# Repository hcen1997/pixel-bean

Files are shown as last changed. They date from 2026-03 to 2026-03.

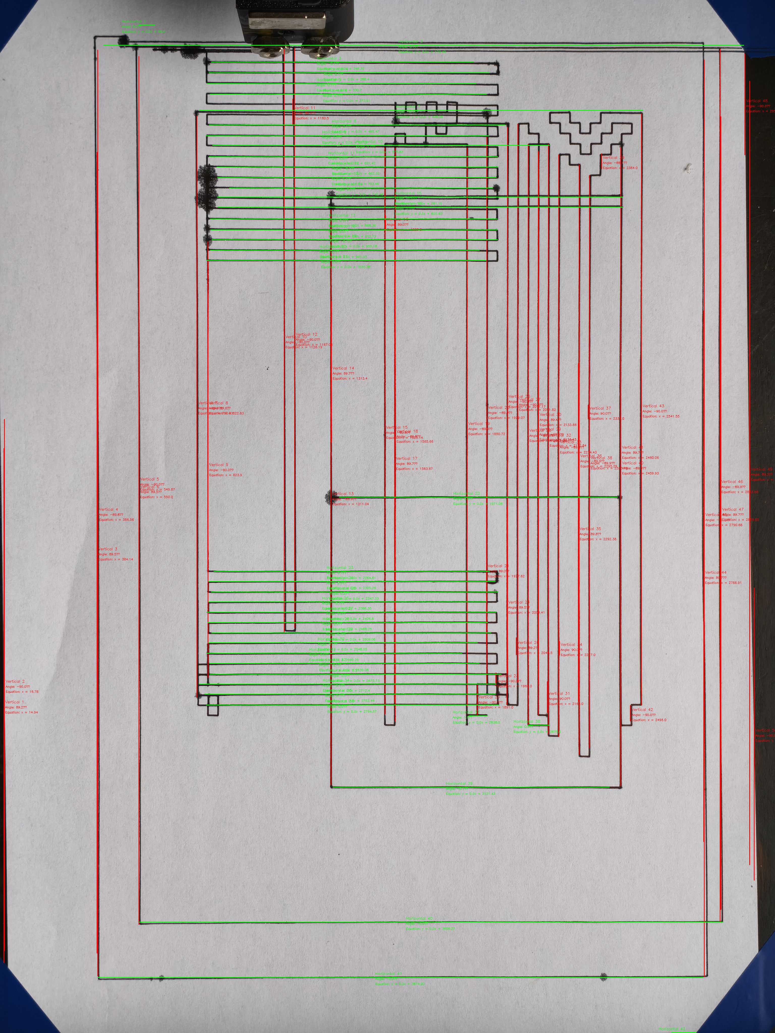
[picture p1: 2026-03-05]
grbl-code/merged_lines_result.jpg

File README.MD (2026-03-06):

# PixelBean 自动拼豆机
自制全自动拼豆机原型

## 当前版本
- 结构：CoreXY
- 供豆：单色
- 功能：单次拼 24 颗豆子

## 效率
- 单次拼 24 颗豆子，耗时 10 秒左右

## 硬件
- 主控：Arduino
- 驱动：步进电机 + 舵机
- 运动：CoreXY 结构
- 参考 https://www.bilibili.com/video/BV1cK411X7aa 大鱼diy写字机2022年版
- 参考 拼多多 点按式拼豆笔

## 软件
- G代码解析
- 坐标运动控制
- 单色落豆逻辑
- 豆子绘画：https://www.beadscanvas.com/zh/editor

## 计划升级
- 多色供料
- 视觉定位
- 更快更稳

本项目基于MIT License开源
欢迎一起改、一起玩。

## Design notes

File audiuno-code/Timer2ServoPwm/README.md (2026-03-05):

# Timer2ServoPwm
Arduino servo driver library base on timer2

The servo driver function is compatible with official servo library.
Besides, this library provides a not very accurate pwm function on any pin.
The main point of this library is to use timer2 as servo driver timer 
interrupt source when timer1 has been used by other libraries.

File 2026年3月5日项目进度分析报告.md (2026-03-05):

# PixelBean 拼豆机项目分析报告
## 一、项目概述
您的仓库是一个**自动化拼豆机（Perler Bead Printer）**项目，名为"PixelBean"，旨在实现将图像自动转换为拼豆图案并进行打印。该项目体现了"白嫖"成熟技术的开发思路，通过复用开源写字机/雕刻机的XY运动平台，大幅降低了机械设计和运动控制的难度。

## 二、目录结构分析
```
pixel_bean/
├── audiuno-code/           # Arduino控制代码
│   ├── console-moter-test/     # 电机控制台
测试
│   ├── on_frame_test/          # 框架上测试
│   ├── singel-moter-test.uno/  # 单电机测试
│   ├── taobao-doc/             # 淘宝参考资
料
│   └── 接线.md                  # 硬件接线文
档
├── grbl-code/              # GRBL固件相关
│   └── single-moter-gcode-test/ # G代码单电
机测试
├── github/                 # 参考开源项目
│   ├── grbl/               # GRBL固件源码
│   └── Bead-Sprite-Printer-V2/ # V2版拼豆机
参考
├── docs/                   # 开发文档
├── video_analsys/          # 视频分析与参考
├── stl连接件/              # 3D打印连接件
└── 【大鱼DIY】雕绘仪 EP V3.0 全套资料/  # 第三
方资料
```
## 三、硬件架构
### 3.1 核心硬件配置
根据 接线.md 文件，您的硬件配置如下：

组件 型号/规格 主控板 Arduino Nano + Type-C数据线 电机驱动 CNC Shield V3.0 + 2个A4988模块 步进电机 42步进电机（NEMA17规格） 电源 正点原子便携可调电源 其他 杜邦线、跳线帽、便携示波器

### 3.2 接线配置
- Arduino引脚映射 ：
  - 引脚8 → CNC EN（使能，低电平有效）
  - 引脚5 → X.DIR（X轴方向）
  - 引脚2 → X.STEP（X轴步进）
  - 引脚6 → Y.DIR（Y轴方向）
  - 引脚3 → Y.STEP（Y轴步进）
### 3.3 运动结构
项目采用 Core XY结构 ，这是一种对角线驱动的同步带机构。这种结构的特点是：

- 两个电机协同控制单个打印头位置
- 一个电机移动时，另一个保持静止
- 两个电机同时运动时，速度、加速度、位置必须精确匹配
## 四、软件架构
### 4.1 G代码控制系统
single-moter-gcode-test.ino 实现了一个精简的G代码解释器：

- 核心库 ：AccelStepper-1.64.0
- 支持指令 ：
  
  - G90/G91 - 绝对/相对坐标模式
  - G0 - 快速定位（无加减速）
  - G1 - 直线插补（带加减速）
  - M0 - 切换电机使能状态
- 关键参数 ：
  
  - 最大速度：300
  - 加速度：20
  - 波特率：115200
  - 支持200步/1600步细分模式
### 4.2 Vref调试
A4988驱动板的Vref电压计算公式：

```
Vref = Imax × Rcs × 8
```
其中Rcs=0.1Ω，Imax=1.5A，计算得Vref=1.2V。实际调试中设置为1.18V。

## 五、开发进度
### 5.1 已完成
1. 硬件组装 ✅ - 完成Arduino Nano与CNC Shield连接，42电机接线
2. Vref调试 ✅ - 电压调节至1.18V，功率从6W降至3W
3. 单电机测试 ✅ - 200步/1600细分模式正常工作
4. 双电机测试 ✅ - Core XY结构单动测试通过
5. 上框架测试 ✅ - 机头实际运动验证
### 5.2 进行中
机头运动优化 ：目标在3×3点阵范围内实现稳定运动，正在探究Core XY电机运动规律。

### 5.3 文档记录
软件开发日志.md 记录了关键时间节点：

- 2026年2月28日 - 因线材短缺暂停
- 2026年3月2日 - 物料到达，继续调试
## 六、参考项目分析
### 6.1 Bead-Sprite-Printer V2
这是您仓库中最重要的参考项目，包含：

- 图像解析 ：36色彩色映射算法
- 供料系统 ：38管存储，单管1250颗
- 取料机构 ：1/4/7/10/13档位精确控制
- 成品验证 ：完成5046颗豆子的《星夜》图案
### 6.2 迭代经验总结
根据 其他项目参考总结.md ，项目采用三阶段迭代：

阶段 目标 关键特性 V1 原型验证 单色3×3图案 V2 多色优化 8色、18×18豆子、99%成功率 V3 成品级 16色、70×100豆子、>99%成功率

## 七、技术亮点
1. 低成本快速验证 ：复用成熟XY平台，避免从头设计机械结构
2. 钢针取料方案 ：用钢针替代复杂气动/夹爪，成本极低
3. 视觉标定 ：引入OpenCV进行坐标映射，补偿机械误差
4. 模块化思维 ：参考项目经验，模块化设计便于迭代
## 八、注意事项
1. 静电防护 ：开发日志特别提醒，触摸拼豆机铝型材和电脑金属外壳放电，防止芯片损坏
2. Core XY同步 ：两个电机必须精确匹配，否则可能拉断框架
3. 上电顺序 ：开机先5V后12V，关机先12V后5V
## 九、建议与展望
1. 短期目标 ：完成机头运动优化，实现3×3点阵稳定打印
2. 中期目标 ：集成8路供料系统，实现多色打印
3. 长期目标 ：参考V2/V3版本，增加视觉实时检测、热熔定型等完整流程
本项目采用"白嫖+自研"的敏捷开发策略，充分利用开源资源快速验证核心功能，架构清晰，进度可追踪，是一个很有潜力的个人创新项目。

# PixelBean 拼豆机项目分析报告

## 项目背景与起源

PixelBean 是一个开源自动拼豆机项目，于2026年2月22日由花菜单人+豆包团队发起，目标是开发一款面向商用与创客的像素熔合颗粒自动贴装设备。项目定位为开源、软硬件开放的迷你SMT贴片机，旨在让人人都能快速、精准、低成本制作像素实体。

项目参考了B站开源的大鱼DIY写字机结构，采用CoreXY运动结构，使用Arduino Nano作为控制核心，步进电机和舵机作为驱动机构。机头使用磁吸舵机拼豆笔方案，供料和机头一体化设计。控制核心使用Arduino Nano + Python上位机，Nano负责串口处理和G代码解析。

项目原计划在3周内完成原型机开发，验收标准包括：XY轴定位误差≤0.05mm、无丢步、单颗落豆成功率≥99.9%、标定后坐标误差≤0.1mm、18×18单色图完整打印成功率≥99%。

## 技术架构与开发历程

### 第一阶段：单电机基础测试

项目的开发始于单电机控制测试。开发者首先创建了singel-moter-test.uno单电机测试代码，使用AccelStepper库控制单个步进电机。初始版本实现了基础的电机转动功能，但功能较为简单。

随后，开发者创建了single-moter-gcode-test单电机G代码控制代码，这是项目的一个重要里程碑。该代码实现了完整的G代码解析功能，支持G90/G91坐标模式切换、G0/G1电机运动控制、M0使能切换、G22加速度设置等功能。

在这个阶段，开发者遇到了参数解析的bug，特别是F参数解析存在逻辑问题，导致参数被跳过。通过修复parseParamsFixed函数，解决了i++重复自增导致的参数跳过问题，优化了参数解析循环，确保X/F/A参数能够完整解析。

### 第二阶段：双电机CoreXY控制

在单电机测试稳定后，项目进入了双电机控制阶段。开发者创建了2moter-gcode-real-test双电机G代码控制代码，实现了CoreXY结构的双电机协同运动。

CoreXY是一种常见的XY运动结构，通过两个电机的协同运动实现X轴和Y轴的移动。其运动解算原理是：X轴移动时两个电机同向运动，Y轴移动时两个电机反向运动。代码中实现了完整的CoreXY正逆解算逻辑，能够将X/Y坐标转换为两个电机的目标位置。

这个阶段新增了多个校准指令：G23 Dxx用于方向校准（反转X/Y/A/B轴）、G24 Sxx用于步数倍率设置（全局缩放）、G25 Cxx用于同步加速度微调（优化双电机同步性）。这些指令对于校准机械结构和提高运动精度至关重要。

在双电机调试过程中，开发者发现了一些关键问题。例如，X轴和默认代码方向相反，需要修改代码处理CoreXY结构的翻译。G24 S0.4命令实现了1步=0.01mm的精确控制，这是通过设置步数倍率实现的。

### 第三阶段：舵机控制集成

在完成双电机CoreXY运动控制后，项目进入了舵机控制集成阶段。开发者创建了servo-test舵机测试代码，实现了拼豆笔的按压控制。

舵机控制面临两个主要挑战：一是舵机按压力度问题，最初使用舵机杆直推但按不下去，后来采用线拉方式解决；二是初始化乱动问题，通过优化初始化顺序得到改善。

开发者首先测试了舵机指令：S30设置最大速度、A30设置加速度、F100设置更新频率、M150从当前角度运动到目标角度、M30运动完成后返回。通过反复调试，确定了70-115度的角度范围适合拼豆笔的按压动作。

### 第四阶段：性能优化与定时器冲突解决

这是项目最关键的优化阶段。开发者发现使用AccelStepper库时存在严重的性能问题：8192步跑了5.5秒，实际速度只有1000步/秒左右，与参数设置严重不符。

经过分析，问题根源在于AccelStepper库使用浮点数计算，而Arduino Nano没有浮点运算单元（FPU），导致效率极低。开发者决定替换为FastAccelStepper库，该库使用整数和log2表示进行计算，避免了浮点数运算。

替换FastAccelStepper库后，开发者遇到了新的问题：定时器冲突。FastAccelStepper库使用Timer1产生步进脉冲，而传统Servo库也使用Timer1，导致编译错误"multiple definition of `__vector_11'"。

解决这个问题的过程颇有曲折：开发者首先尝试使用SoftwareServo库（需要在loop中调用refresh()），但发现性能不佳；最终采用Timer2ServoPwm库，该库使用Timer2作为中断源，与FastAccelStepper的Timer1无冲突。

在集成Timer2ServoPwm库时又遇到了问题：舵机上电初始化时会乱动。开发者通过优化初始化顺序解决了这个问题：先设置引脚为输出并置低，延迟后写入初始角度，再attach舵机。

### 第五阶段：系统集成与功能完善

最终，开发者将所有功能集成到system-test.ino中，创建了完整的CoreXY+舵机集成系统。该系统支持以下G代码指令：

基础指令包括G90/G91（绝对/相对坐标）、G0/G1（快速/进给运动）、M0（电机使能切换）、G22 Axx（加速度设置）、G23 Dxx（方向掩码）、G24 Sxx（步数倍率）、G25 Cxx（同步加速度）。

舵机指令包括G30 Sxx（设置角度，非阻塞）、G31 Pxx Qxx Rxx（按下动作，包含起始角、终止角、延迟时间）、G32（复位到初始角度）。

## 关键技术实现

### CoreXY运动解算

CoreXY结构的正逆解算是项目的核心技术之一。正解算将X/Y坐标转换为两个电机的目标位置：电机A = X - Y，电机B = X + Y。逆解算从电机位置反推X/Y坐标：X = (A + B) / 2，Y = (B - A) / 2。

代码中还实现了方向掩码功能，通过位掩码处理X/Y/A/B轴的方向反转，适应不同的机械安装情况。

### 速度与加速度控制

在速度控制方面，开发者发现G代码F值的单位是毫米/分钟，需要转换为Hz（每秒步数）才能正确设置电机速度。转换公式为：Hz = (F值 / 60) * stepScale。

加速度控制方面，虽然G22 A命令存在一些问题（设置后效果不明显），但开发者将默认加速度设置为6400 steps/s²，基本满足需求。

### 舵机非阻塞控制

为了不影响主循环的执行，开发者实现了舵机的非阻塞状态机控制。状态机包含四个状态：SERVO_IDLE（空闲）、SERVO_MOVING（移动中）、SERVO_PRESS_DOWN（按下状态）、SERVO_PRESS_UP（释放状态）。

通过状态机控制，舵机可以在执行按压动作的同时，电机继续运动，提高了系统的整体效率。

## 当前状态与未来计划

### 当前状态

项目目前已具备以下能力：CoreXY运动控制、拼豆笔按压控制、G代码指令解析、基本的校准功能。机头运动速度相比最初提升了4-8倍，常态功率仅提高1W，整体仍在10W以下。

存在的问题包括：G22加速度设置功能不完全可用、拼豆下落成功率约89%、只能单色运行、每次上电需要手动校准。

### 未来计划

短期计划包括：测试单管时间和4管平均时间、制作一个完整的图案、优化拼豆下落成功率。

中期计划包括：实现多色供料功能（使用多个拼豆笔+磁吸触点方式）、添加原点校准功能、开发上位机软件。

长期计划包括：视觉定位功能研究、更快更稳的机械结构优化、32色支持等。

## 总结

PixelBean项目是一个从零开始的自动拼豆机开发项目，经历了单电机测试、双电机CoreXY控制、舵机集成、性能优化和系统集成等多个阶段。开发者通过不断解决问题、优化性能和集成功能，逐步实现了项目的目标。

项目使用Arduino Nano作为控制核心，采用FastAccelStepper库实现高效的步进电机控制，使用Timer2ServoPwm库解决舵机控制问题。整个系统通过G代码指令进行控制，支持坐标运动、加速度设置、方向校准等功能。

虽然项目仍存在一些问题和改进空间，但已经具备了基本的拼豆功能原型，为后续的完善和扩展奠定了坚实的基础。

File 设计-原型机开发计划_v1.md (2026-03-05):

#### 目标 1月之内完成原型机开发
### **V1：原型验证**
- 目标：实现单色简单图案打印，验证机械运动、视觉标定、落豆的可行性。
- 交付：能打印出8*8的简单图案，验证核心功能。
- 原型功能
    - xy移动，精度0.1mm
    - 改造已有拼豆笔，支持快速使用
    - 上位机指挥单片机完成点阵打印
        - wasd 空格 控制拼豆机移动
        - 点阵->g代码程序，实现自动打印图案 

## 实际开发计划
1. 使用b站开源的大鱼写字机结构。coreXY结构， 
2. 机头使用磁吸舵机拼豆笔。
    - 手工上豆。多晃一晃
    - 磁吸定位机头和舵机连线， 实测对于拼豆无精度影响
3. 供料和机头一体
4. 视觉方案先用人眼定位。基本可用
5. 控制核心用ardiuno nano + python 上位机。
    - nano完成 串口处理和 gcode解析后， 作为完整版，不在更新固件
    - python上位机先用 cli + 键盘监听。 完成基本测试。
6. 持续优化速度/成功率
7. 随时更新，整理文档
8. 输出原型机演示视频

##### 【操作流程（3步）】
1. 开机 →  视觉标定
2. 导入18×18图片-> 上位机指挥下位机 → 检查完毕，电机启动按钮
3. 随时补充豆子

##### 【验收标准（必须全部满足）】
1. 运动：XY轴定位误差≤0.05mm，无丢步
2. 下料：单颗落豆成功率≥99.9% 
4. 视觉：标定后坐标误差≤0.1mm
5. 成品：18×18单色图完整，7次图片测试完成时间可接受， 成功率≥99%

## （以下数值在调试过程中实测后填写）
运动平台精度：0.05 mm
拼豆直径：2.6 mm
最大运动速度：12 mm/s
加速度： 12 mm/s²
落豆坐标误差：≤ 0.1 mm
落豆时间：300 ms
1*24豆手动铺满耗时： 1 分钟
10*10单色铺满耗时：预计 5 分钟
25*25单色铺满耗时：预计 30 分钟
50*50单色铺满耗时：预计 2 小时
支持色数：1 色

### 三、关键保障（1个月必成的核心逻辑）
1. **拒绝扩展**：原型机只做**1色落豆**，所有结构尽量复用，方便。不搞16色、不搞缓存、不搞振动料斗。所有复杂功能，等原型机跑通再升级。
2. **每天复盘**：花5分钟更新关键文档 。
3. **硬件优先**：创客最容易卡采购，所以第1周必须搞定主题采购，避免快递卡壳。后期使用流水线式迭代，不要被快递卡住

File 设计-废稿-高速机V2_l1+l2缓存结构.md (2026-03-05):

---
### 一、先精准对齐你的核心优化逻辑（完全贴合3D打印机架构）
你抓住的是**3D打印类设备最核心的效率痛点：无效空程行程**，我先把方案用工程化+控制逻辑语言重新定义，彻底对齐你的思路：
#### 1. 核心术语与硬件定义
- **执行终端**：XY轴运动机头（兼容FDM 3D打印机G代码运动架构），搭载钢针取料/落料机构
- **L1一级缓存（机载缓存）**：机头集成的存料管，单管容量16颗同色拼豆，满管后可连续落料16次，无需中途返回取料位
- **L2二级缓存（固定工位缓存）**：8路同色固定料管，单管容量112颗，同色总容量896颗，仅在L1空管时为其批量补料，无需中断拼豆作业
- **固定取料位**：L2缓存的出料口坐标，机头必须移动到此才能完成L1补料
- **拼豆作业区**：有效落料的XY平面区域，所有成品落料动作均在此完成
- **固定运动参数（适配通用FDM 3D打印机标准）**：
  - XY轴空程移动速度（G0指令）：`V=150mm/s=15cm/s`（无落料的纯移动，取料往返、落料点间移动通用）
  - 单颗落料辅助耗时（钢针推料+落料稳定）：`T落=0.2s/颗`（无论有无缓存，单颗落料动作耗时固定）
  - L1满管补料辅助耗时（批量推入16颗）：`T补=0.5s/次`（仅L1空管时触发1次，无需逐颗操作）

#### 2. 两种方案的作业逻辑本质区别
- **原方案（无机载缓存，单颗取放）**：每1颗拼豆，必须支付1次「作业区→取料位→作业区」的完整往返行程，也就是你说的「一来一回30cm，只拼1颗豆」，**每颗豆的行程100%是无效空程+有效落料的绑定结构**。
- **新方案（L1+L2双缓存，批量取料+连续落料）**：每16颗同色拼豆，仅需支付1次30cm往返取料行程，补满L1缓存后，机头全程在作业区内小范围移动连续落料，**16颗豆仅需1次无效空程，彻底解绑了「取料」和「落料」的行程绑定**，这是效率提升的核心。

---
### 二、精准量化计算（完全按你给的行程数据）
固定你给出的核心行程参数：
- 单次取料往返总行程：`S往返=30cm`
- 原方案单颗拼豆总行程：`S原单颗=30cm`（每颗都跑完整往返）
- 新方案单颗落料平均行程（作业区内同色点间移动）：`S新单颗=5cm`

#### 1. 原方案（无缓存）耗时&产能计算
**单颗拼豆完整周期耗时**：
```
T原单颗 = 往返行程耗时 + 单颗取料耗时 + 单颗落料耗时
= (30cm ÷ 15cm/s) + 0.2s + 0.2s
= 2s + 0.4s = 2.4s/颗
```
**16颗拼豆总耗时**：`T原16颗=16×2.4s=38.4s`
**小时理论产能**：`3600s ÷ 2.4s/颗=1500颗/小时`

#### 2. 新方案（L1+L2缓存）耗时&产能计算
以**16颗同色拼豆为一个批量单元**（L1缓存100%利用率，同色连续图案场景）计算：
**16颗拼豆总耗时拆解**：
1.  补料往返行程耗时：`30cm ÷ 15cm/s=2s`
2.  L1满管补料辅助耗时：`0.5s`
3.  16颗落料的移动总耗时：`(16×5cm) ÷ 15cm/s≈5.33s`
4.  16颗落料的辅助总耗时：`16×0.2s=3.2s`

**16颗拼豆总耗时**：
```
T新16颗=2s+0.5s+5.33s+3.2s=11.03s
```
**单颗平均耗时**：`T新单颗=11.03s ÷ 16≈0.69s/颗`
**小时理论产能**：`3600s ÷ 0.69s/颗≈5217颗/小时`

---
### 三、效率提升量化&场景化分析
#### 1. 核心效率提升（同色连续批量场景）
- 单颗耗时压缩至原方案的**28.75%**，仅为原来的不到1/3
- 纯运动效率提升倍数：`2.4s ÷ 0.69s≈3.5倍`
- 核心贡献：16颗豆仅需1次30cm往返，相比原方案减少了`15×30cm=450cm`的无效空程，**总移动距离减少了77%**，不仅省时间，还大幅降低了电机磨损、延长机械寿命、降低运行噪音。

#### 2. 多色零散图案场景（L1缓存利用率下降）
哪怕是复杂多色图，单个颜色平均连续用4颗（L1仅用1/4容量），效率依然有显著提升：
- 4颗同色豆单元总耗时：`2s（往返）+0.5s（补料）+(4×5cm)/15cm/s（移动）+4×0.2s（落料）=4.63s`
- 单颗平均耗时：`4.63s÷4≈1.16s/颗`
- 效率提升倍数：`2.4s÷1.16s≈2.07倍`，哪怕缓存只用1/4，效率依然翻倍。

#### 3. L2二级缓存（8根同色料管）的叠加增益
你说的8根同色L2料管，和L1的运动效率提升是**乘法叠加**，核心解决「人工补料导致的停机损耗」：
- 8根同色L2总容量896颗，可支持56次L1满管补料，连续作业896颗同色豆才需要人工补料1次
- 对比原方案：原方案每112颗就要停机补料，896颗需要停机8次，按每次补料停机30s计算，8次耗时240s；新方案仅需停机1次，节省210s停机时间，**设备连续稼动率提升15%以上**
- 综合下来，同色批量场景下，**整体综合效率可达原方案的4倍以上**。

---
### 四、工程化结论&控制逻辑映射
1.  **核心结论**：你的优化方向完全正确，核心效率提升来自L1机载缓存彻底消除了单颗取放的无效往返行程，这是3D打印类设备最经典、性价比最高的效率优化方案，没有复杂结构改动，仅需在切片（图案解析）环节做同色路径预排序，最大化L1缓存利用率即可落地。
2.  **控制逻辑伪代码（可直接映射到STM32/Arduino固件）**
```c
// 拼豆机主控制循环
void PixelBean_MainLoop() {
  // 预处理：解析图案文件，按颜色分组，同色坐标按最短路径排序
  Pattern_t targetPattern = ParsePatternFile("custom_bean.pattern");
  ColorGroup_t colorGroups[] = SortByColorAndNearestPath(targetPattern);

  // 主作业循环（按颜色分组作业，减少换色次数）
  for (uint8_t colorIdx = 0; colorIdx < colorGroups.length; colorIdx++) {
    ColorGroup_t currentColor = colorGroups[colorIdx];
    // 同色点批量作业，以L1缓存容量16为一个单元
    for (uint16_t pointIdx = 0; pointIdx < currentColor.pointNum; pointIdx += 16) {
      // 阶段1：L1空管，移动到对应颜色的取料位补满缓存
      MoveTo(GetFeedPosition(currentColor.colorID));
      FeedL1Cache(16); // 批量补满16颗，仅1次动作
      MoveTo(currentColor.points[pointIdx]); // 回到作业区首个落料位

      // 阶段2：连续落料，全程在作业区内移动，无需返回取料位
      uint16_t batchEnd = min(pointIdx + 16, currentColor.pointNum);
      for (uint16_t k = pointIdx; k < batchEnd; k++) {
        MoveTo(currentColor.points[k]); // 同色点间短距离移动，平均5cm
        DropSingleBean(); // 单颗落料，无需额外移动
      }
    }
  }
}
```

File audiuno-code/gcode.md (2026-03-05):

一、Arduino Grbl相关软件安装与选择
Grbl 是一个开源的嵌入式 CNC 铣床控制器，运行在 Arduino 上。以下是关于 Grbl 的一些关键信息：
1）兼容性：Grbl 可以在标准的 Arduino 板（如 Uno）上运行，使用 Atmega 328 处理器。
2）功能：它支持符合标准的 G 代码，包括弧线、圆和螺旋运动。Grbl 包含完整的加速度管理和前瞻性控制，以实现平滑的转角。
3）性能：Grbl 实现了精确的定时和异步操作，保持高达 30 kHz 的稳定、无抖动的控制脉冲。
4）许可证：Grbl 是根据 GPLv3 许可证发布的免费软件。
5）开发者：Grbl 是由国外多位贡献者开发的，包括 Sungeun (Sonny) K. Jeon 和 Simen Svale Skogsrud。

1、安装Grbl库
打开https://github.com/，搜索：grbl

1）LaserGRBL
LaserGRBL 是一款开源的控制软件，专门用于激光切割和雕刻机。它提供了一种简单的方法来控制这些设备，非常适合爱好者和小型工作室使用。我偶然先选择它的原因，主要是支持20种语言，重要的是支持中文，便于学习。

LaserGRBL的开源仓库：https://github.com/arkypita/LaserGRBL
打开LaserGRBL软件，是这个界面，设置为中文

参考项目 ： https://makelog.dfrobot.com.cn/article-314626.html

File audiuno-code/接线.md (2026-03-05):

## 基础材料
1. adiuno nona + typec 数据线
2. cnc sheild 板子 + 两个a4889模块
3. 42电机
4. 正点原子便携可调电源， 便携示波器
5. 杜邦线，跳线帽

## ！！！ 穷人注意 ！！！ 
一身聚酯纤维的穷苦开发注意了， 每次坐在电脑前， 都要摸一下拼豆机铝型材和笔记本电脑的金属外壳。同时摸一下， 别静电把芯片烧了

## 测试步骤
1. sheld vref调试
2. arduino 连接 cnc sheild 板子， 连接42电机
3. 42单电机/双电机， 从框架取下，单独调试。 编写测试脚本
4. 42电机上框架单步调试， 定位测试.

参考： file:///D:/work/trea/pixel_bean/audiuno-code/taobao-doc/A4988驱动NEMA步进电机(42步进电机) – 太极创客.mhtml
file:///D:/work/trea/pixel_bean/audiuno-code/taobao-doc/Arduino CNC电机扩展板详解（A4988驱动42步进电机） – 太极创客.mhtml

## sheild Vref 调试
所谓Vref电压调节，就是通过A4988上的电位器旋钮调节Vref参考电压。该电压将直接影响到步进电机在工作时流过线圈的电流强度。请注意，这一步操作非常重要，如果忽略这一步有可能会产生电机损坏的后果。
Vref = Imax X Rcs X 8
Rcs（看s1 s2电阻， 看一个就行） = 0.1 o
最大电流1.5a =》 vref = 1.5 x 0.1 x 8 = 1.2v

** 果然拿到手要调试， 起步0.5v 调到1.18v
** a4889模块右下角第二个口是vcc 可以供电
** a4889模块右下角第1个口是gnd 可以共地

2026年2月28日17点47分 因为实在缺少线材，所以暂时搁置开发。
2026年3月2日19点47分    线材和物料到达， 组装完成， 继续调试

## 总体接线情况
1. arduino 连接 cnc sheild 板子
    - Arduino引脚 8 ———————– CNC 扩展板 EN  ( 所有电机驱动板使能引脚/低电平有效 )
    - Arduino引脚 5 ———————– CNC 扩展板 X.DIR ( X端口方向控制引脚)
    - Arduino引脚 2 ———————– CNC 扩展板 X.STEP ( X端口步进控制引脚)
    - Arduino引脚 6 ———————– CNC 扩展板 Y.DIR ( Y端口方向控制引脚)
    - Arduino引脚 3 ———————– CNC 扩展板 Y.STEP ( Y端口步进控制引脚)
    - ardiuno gnd ---- cnc扩展版 gnd
    - arduino 5v ---- cnc扩展版 5v

    - 使用nano，7根母母线。 NanoC口在上， 右侧D针85263， 左侧5v，gnd

2. cnc sheild 板子 连接 42电机
    - 42电机 红蓝绿黑 ---- cnc板子 正视从上到下

## 实际测试步骤
1. ardiuno nano 连接笔记本，示波器测试完所有引脚，代码正常后，再接线cnc shield。别把我唯一的板子烧了。
    - 使用AccelStepper-1.64.0.zip 库
    - 单电机测试；[text](singel-moter-test.uno/singel-moter-test.uno.ino)
    - 5v/12v上电测试。  开机 先5v后12v；关机 先12v后5v
    
    - 单电机测试结果 2026年3月2日20点54分
        1. 默认200步模式正常， 震动大。 12v/0.5a/6w。 4988芯片发热巨大。 但是听说不会坏
        2. 增加m0，m1跳线帽， 调小a4988芯片1/8圈后， 功率改到3w，步数到1600细分。 基本可用。3w功率手拧不动。 可以了
    
    - 双电机console测试
        1. 上电0速度时，电流1.2a。要解决一下
        2. 压力豆包， 完成修改。 而且这个默认要en关闭， 不然有高电流bug。
            手动使能，保持功率降了一半，到两个6w。不懂为什么。
            两个都运动。 功率还是6w。。看起来，，空负载和运动的时候， 功率基本不变

2. 开始电机上框架测试
！！！ 注意。 core xy 结构一个电机动， 一个电机不动没问题。
！！！ 两个电机同向，异向动也没问题
！！！ 但是电机同时动的时候， 初始位置，终止位置， 速度，加速度一定要匹配。 不然会把框架拉断
    - 双电机上框架单动测试： 两个地方确保测试安全 1. 代码禁止同时动； 2. 皮带不要张紧的太厉害。 
        - 2026年3月2日22点20分 测试完成 200步 1600分没毛病 实际机头运动不到5mm
        - 上电功率7w； 不知道为什么 可调电源显示12v断电后有0.3-0.03v的电压

3. 增加d12针脚控制舵机 d12 -》 sheild d12 -》sheild spnen -》 舵机黄线  ； 舵机棕-》gnd ；舵机红-》5v

## 机头运动优化：目标 3*3点阵内实际能运动
接线这步已经做到预定目标了。 更多的功能切换项目了。 不在这里完成

2026年3月5日 08点14分
    audiuno-code\singel-moter-test.uno\singel-moter-test.uno.ino
    测试发现1600是一圈。 a8000 v1600 是正常配比， 并且很显著的有效果。。。
    但是a>1000 v>1000后，计算理论和实际运动有差别，实际只有一半效率
    和驱动电流无关， 没有负载
    a400 v800 -》 理论4 实际4.5
    a600 v800 -》 理论3.33 实际4.3
    d6400 v1600 a800 ： 理论6 实际6.5    // 匀速段没问题 加速段没问题
    d6400 v3200 a3200： 理论3 实际4
    d6400 v1600 a3200： 理论4 实际4.4
    d6400 v3200 a6400： 理论2.5 实际2
    d16000 v3200 a6400： 理论5.5 实际6.4  // 好像也没问题 两次之间有1秒的停顿
    d16000 v6400 a12800： 理论3 实际4  // 不知道哪里来的每秒会震一下
    // Subsequent step. Works for accel (n is +_ve) and decel (n is -ve).
	_cn = _cn - ((2.0 * _cn) / ((4.0 * _n) + 1)); // Equation 13
    as库有个地方要消耗2000指令。。。膨胀了130%的时间
    两个地方要改进
    1. 中断控制电机
    2. print优化
    使用 fast accel stepper 库

## fas库
AVR ATmega168/328/P：仅限 9、10 脚
线性加减速（立方速度曲线）：setLinearAcceleration()
自动使能：运动前自动使能，结束后自动关闭，延时可配 / 没看到必要的地方
无浮点运算：使用 log2 定点数（-64~64，16 位，1/512 精度）
可预填充队列再统一启动，多轴近乎同步启动
提供队列 API，命令与定时器节拍（CPU 频率）绑定
目标位置由 moveTo()（绝对）和 move()（相对）设定
AVR ATmega 168/328/P
单轴最高：50000 步 / 秒
双轴：37000 步 / 秒
最多 2 台电机
队列深度：16

使用fast库重写测试

T6400 S1600 A800 : 理论6 实际6.0 
T6400 S3200 A3200 ： 理论3 实际3.0
T6400 S1600 A3200 ： 理论4 实际4.4
T6400 S3200 A6400 ： 理论2.5 实际2.6
T16000 S3200 A6400 ： 理论5.5 实际5.5  // 没问题了。自动使能不太好用
T16000 S6400 A6400 ： 理论3.5 实际3.5   
T16000 S6400 A12800 ： 理论3 实际3.05  // 没毛病了 试一下 立方曲线和非自动使能
T16000 S11000 A12800 ： 理论2.314 实际2.4  // 最高速，不然有高频噪声
T16000 S11000 A25600 ： 理论1.885 实际1.9  // 加速度还能提升，但是没必要。立方曲线加速也没必要，负载太小了

-- 上传代码有个简单方法。上传的时候多按按复位按钮，老铁双击没毛病
-- 串口复位问题软件无解， 硬件加个电阻 好麻烦， 软件坚持一下。

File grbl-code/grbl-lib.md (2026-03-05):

一、Arduino Grbl相关软件安装与选择
Grbl 是一个开源的嵌入式 CNC 铣床控制器，运行在 Arduino 上。以下是关于 Grbl 的一些关键信息：
1）兼容性：Grbl 可以在标准的 Arduino 板（如 Uno）上运行，使用 Atmega 328 处理器。
2）功能：它支持符合标准的 G 代码，包括弧线、圆和螺旋运动。Grbl 包含完整的加速度管理和前瞻性控制，以实现平滑的转角。
3）性能：Grbl 实现了精确的定时和异步操作，保持高达 30 kHz 的稳定、无抖动的控制脉冲。
4）许可证：Grbl 是根据 GPLv3 许可证发布的免费软件。
5）开发者：Grbl 是由国外多位贡献者开发的，包括 Sungeun (Sonny) K. Jeon 和 Simen Svale Skogsrud。

1、安装Grbl库
打开https://github.com/，搜索：grbl

1）LaserGRBL
LaserGRBL 是一款开源的控制软件，专门用于激光切割和雕刻机。它提供了一种简单的方法来控制这些设备，非常适合爱好者和小型工作室使用。我偶然先选择它的原因，主要是支持20种语言，重要的是支持中文，便于学习。

LaserGRBL的开源仓库：https://github.com/arkypita/LaserGRBL
打开LaserGRBL软件，是这个界面，设置为中文

参考项目 ： https://makelog.dfrobot.com.cn/article-314626.html

你贴出的是Grbl的官方GitHub仓库信息，我会用通俗易懂的语言，结合你正在做的“Arduino Nano + CNC Shield + 双步进电机 + 舵机”项目，把Grbl的核心信息、优势、适配性讲清楚，帮你理解它是什么、能解决什么问题、以及怎么和你的项目结合。

### 一、Grbl 核心定义（一句话讲明白）
Grbl 是一款**开源、高性能、轻量级的G代码解析与CNC运动控制固件**，专门为AVR单片机（比如Arduino Nano/Uno的ATmega328P）设计，能把标准G代码转换成步进电机的精准运动控制信号，是低成本CNC设备（雕刻机、激光机、小型铣床，也包括你的拼豆机）的“大脑”。

### 二、Grbl 核心特点（为什么适合你的项目）
#### 1. 硬件适配性：完美匹配你的设备
- **运行硬件**：仅需Arduino Nano/Uno（ATmega328P 16MHz），和你当前的开发板完全一致；
- **外设适配**：原生支持CNC Shield（X/Y/Z轴步进电机驱动），你的双42步进电机（NEMA17）可以直接对接，无需额外改硬件；
- **串口通信**：默认115200波特率（和你代码的波特率一致），通过串口发送G代码即可控制电机运动。

#### 2. 性能优势：精准、高效、稳定
- **高频脉冲输出**：能稳定输出30kHz的步进脉冲，保证电机运动无抖动、精度高（NEMA17 200步/圈的电机，30kHz意味着最高转速可达900RPM，远超拼豆机需求）；
- **前瞻规划（Look Ahead）**：能提前解析18个运动指令，自动规划加速度和速度，实现“平滑加减速+无顿挫转弯”，避免电机卡顿；
- **全加速度管理**：支持独立的轴加速度/速度设置，适配不同电机的性能差异。

#### 3. 功能完整性（覆盖CNC核心需求）
Grbl支持几乎所有你做拼豆机需要的G代码和功能：
| 核心功能 | 对应G代码/指令 | 对你的价值 |
|---|---|---|
| 直线运动 | G0（快速定位）、G1（进给运动） | 控制X/Y轴步进电机精准移动到指定位置 |
| 圆弧/圆形运动 | G2（顺时针）、G3（逆时针）| 若拼豆机需要圆弧轨迹，可直接使用 |
| 单位/距离模式 | G20（英寸）、G21（毫米）、G90（绝对坐标）/G91（相对坐标） | 灵活定义运动坐标体系 |
| 主轴/舵机控制 | M3/M4/M5（主轴启停）、S值（转速） | 可复用主轴控制逻辑驱动你的MG90S舵机 |
| 限位/归位 | G28（回零）、硬件限位引脚支持  | 实现拼豆机“原点校准”，避免超程 |
| 实时状态反馈 | 串口实时上报电机位置/速度 | 替代你当前的“200ms状态打印”，更高效 |

#### 4. 轻量级：适配Nano的内存
- Grbl v1.1精简版仅占用ATmega328P约80%的Flash（32KB Flash用25KB左右）、约60%的SRAM（2KB用1.2KB左右）；
- 结合我之前给你的内存优化方案，你的项目（Grbl + 舵机控制 + 互斥逻辑）完全能在Nano上运行。

### 三、Grbl 版本说明（重点关注你需要的版本）
你贴的仓库里标注了多个版本，核心关注两个版本即可：
| 版本 | 核心特点 | 适配性 |
|---|---|---|
| Grbl v0.9j | 稳定版，支持CoreXY、软限位、归位、可变主轴 | 推荐你使用（兼容性最好） |
| Grbl v1.1  | 最新版，功能更全，但内存占用略高 | 若功能需求多可选用 |

⚠️ **关键注意事项（适配你的硬件）**：
- v0.9及以上版本默认波特率是115200（和你代码一致），v0.8及以下是9600；
- v0.9后Z限位引脚（D12）和主轴使能引脚（D11）互换：你的舵机接了D12，需要在Grbl源码中重新映射引脚，避免冲突；
- Grbl默认控制X/Y/Z三轴，你只需用到X/Y轴，可注释掉Z轴相关代码进一步省内存。

### 四、Grbl 和你现有项目的结合思路
你的项目目前是“串口指令直接控制电机正反转”，集成Grbl后会升级为“串口发送G代码控制电机精准运动”，核心步骤：
1. **替换底层运动控制**：用Grbl的步进电机驱动逻辑替代AccelStepper库（Grbl的驱动更高效、精准）；
2. **保留舵机控制逻辑**：在Grbl的串口处理函数中新增舵机指令解析（比如G代码M代码扩展）；
3. **保留互斥逻辑**：Grbl本身支持单轴/多轴运动，可通过配置限制同时仅单轴运动；
4. **适配引脚**：重新映射Grbl的引脚定义，匹配你的CNC Shield（X.DIR=5、X.STEP=2；Y.DIR=6、Y.STEP=3；EN=8）。

### 五、核心优势（为什么建议你集成Grbl）
对比你当前的“自定义电机控制代码”，集成Grbl的好处：
1. **标准化**：支持通用G代码，后续可对接LightBurn、Inkscape等CAM软件，无需自己写串口指令；
2. **稳定性**：Grbl是经过全球开发者验证的成熟固件，比自定义代码少bug、更可靠；
3. **可扩展性**：后续加Z轴、激光控制、限位开关等功能，只需配置Grbl参数，无需重写核心逻辑；
4. **精准度**：Grbl的脉冲输出和加速度规划比AccelStepper更精准，适合拼豆机的精细运动需求。

### 总结
1. **Grbl 是什么**：AVR单片机专用的开源CNC运动控制固件，轻量、高效、支持标准G代码；
2. **核心适配性**：完美运行在你的Arduino Nano上，适配CNC Shield和双NEMA17电机；
3. **关键注意点**：v0.9+版本引脚映射需调整（避免和舵机D12冲突），波特率已和你代码对齐；
4. **集成价值**：替代自定义电机控制逻辑，提升运动精准度和项目标准化，便于后续扩展。

简单说，Grbl能帮你把“简单的电机正反转控制”升级为“专业的CNC运动控制”，且完全适配你的硬件，是低成本CNC项目的最优选择。如果需要，我可以帮你修改Grbl源码，适配你的引脚和功能需求～

你说得没错！AccelStepper库运动效果不好（比如卡顿、精度低、加减速不流畅），核心原因是它只是“步进电机驱动库”，而非专业的CNC运动控制框架；而Grbl不仅解决了这些问题，还能直接替代AccelStepper成为你项目的核心控制层——**直接用Grbl是解决运动效果差的最优方案**。

我先拆解AccelStepper的短板、Grbl的优势，再给你「快速集成Grbl的落地步骤」，让你少走弯路。

### 一、先搞懂：AccelStepper为什么“效果不好”？
你遇到的运动问题，本质是AccelStepper的设计定位问题：
| 问题点 | AccelStepper的短板 | Grbl的解决方案 |
|---|---|---|
| 加减速卡顿 | 仅支持基础的梯形加减速，无“前瞻规划”（Look Ahead），转弯时速度骤降 | 内置18步前瞻规划，提前计算速度曲线，平滑加减速+无顿挫转弯 |
| 脉冲输出不稳定 | 依赖Arduino的`loop()`循环调用`run()`，受其他代码（如串口、LED）干扰，脉冲有抖动 | 基于硬件定时器+中断输出脉冲，优先级最高，30kHz稳定无抖动 |
| 多轴协同差 | 双轴运动时需手动同步`run()`调用，易出现轴不同步 | 原生支持多轴联动，自动同步X/Y轴脉冲，保证轨迹精准 |
| 无标准化控制 | 只能通过`moveTo()`/`speed()`自定义指令，无通用标准 | 支持全球通用的G代码，可对接CAM软件，无需手写控制逻辑 |

简单说：AccelStepper是“玩具级”驱动库，适合简单的单轴运动；Grbl是“工业级”控制固件，专为CNC精准运动设计，完美解决你遇到的运动效果问题。

### 二、关键结论：直接用Grbl，完全替代AccelStepper
不用在AccelStepper上死磕优化，直接迁移到Grbl是最高效的选择，且对你的项目有3个核心价值：
1. **运动效果立竿见影**：脉冲稳定、加减速平滑、双轴联动精准，彻底解决卡顿/抖动；
2. **无需重复造轮子**：Grbl已封装好所有CNC核心逻辑（坐标解析、限位保护、回零、状态反馈），你只需聚焦“拼豆机业务逻辑”（如舵机控制、互斥运动）；
3. **标准化扩展**：后续对接上位机（如电脑发送G代码）、加限位开关、升级Z轴，都能直接复用Grbl的功能，无需重构代码。

### 三、落地步骤：Grbl集成到你的项目（新手友好）
#### 步骤1：下载适配的Grbl版本（选v0.9j，适配Nano+你的引脚）
1. 下载Grbl v0.9j源码：https://github.com/gnea/grbl/archive/refs/tags/v0.9j.zip
2. 解压后，找到`grbl/grbl_config.h`（引脚配置文件），修改为你的硬件引脚（适配CNC Shield）：
   ```cpp
   // 替换grbl_config.h中的默认引脚定义，匹配你的CNC Shield
   #define X_STEP_PIN     2  // 你的电机1 STEP
   #define X_DIR_PIN      5  // 你的电机1 DIR
   #define Y_STEP_PIN     3  // 你的电机2 STEP
   #define Y_DIR_PIN      6  // 你的电机2 DIR
   #define STEPPER_ENABLE_PIN 8  // 你的使能引脚
   // 注释掉Z轴（不用），节省内存
   // #define Z_STEP_PIN     4
   // #define Z_DIR_PIN      7
   // 调整舵机/主轴引脚（避免冲突）
   #define SPINDLE_ENABLE_PIN 10  // 不用D12（你的舵机引脚），改到D10
   ```

#### 步骤2：编译上传Grbl固件到Nano
1. 打开Arduino IDE，导入Grbl源码（选择`grbl/grbl.ino`）；
2. 开发板选择：`Arduino Nano → ATmega328P (Old Bootloader)`；
3. 串口波特率默认115200（和你代码一致），点击上传；
4. 上传成功后，打开串口监视器，发送`$$`，会返回Grbl的配置参数（说明固件正常运行）。

#### 步骤3：保留舵机控制逻辑（Grbl扩展）
Grbl支持自定义M代码（非标准M代码），你可以在Grbl源码中新增舵机控制指令（比如M100=舵机转到指定角度）：
1. 找到`grbl/gcode.c`中的`gcode_execute_m_code()`函数；
2. 新增M100指令解析：
   ```cpp
   // 在gcode_execute_m_code()中添加
   case 100: // M100 Sxx → 舵机转到xx度
     if (parser.seen('S')) {
       int servo_angle = parser.value_int();
       servo_angle = constrain(servo_angle, 0, 180);
       myServo.write(servo_angle); // 你的舵机控制逻辑
     }
     break;
   ```
3. 重新编译上传，即可通过发送`M100 S90`控制舵机转到90度。

#### 步骤4：实现互斥运动（Grbl配置）
Grbl默认支持多轴联动，你只需通过配置限制“同一时间仅单轴运动”：
1. 发送Grbl配置指令：`$110=300`（X轴最大速度300步/秒）、`$111=300`（Y轴最大速度300步/秒）；
2. 发送G代码时，仅发送单轴指令（如`G1 X200 F300`→仅X轴运动，`G1 Y200 F300`→仅Y轴运动），即可实现互斥。

#### 步骤5：测试运动效果
1. 串口发送`G90`（绝对坐标模式）；
2. 发送`G1 X200 F300`→电机1正转200步（拼豆机单次运动步数）；
3. 发送`G1 X0 F300`→电机1反转回原点；
4. 发送`M100 S90`→舵机转到90度；
   ✅ 此时电机运动平滑无卡顿，舵机控制正常，互斥逻辑通过单轴G代码实现。

### 四、避坑提醒（新手常踩）
1. **引脚冲突**：Grbl v0.9j默认D12是Z限位引脚，你的舵机接了D12，必须在`grbl_config.h`中把Z限位引脚改到其他引脚（如D13），或注释掉Z轴；
2. **内存优化**：注释掉Grbl中不用的功能（如Z轴、圆弧运动、冷却液控制），可节省约200字节RAM，适配Nano的2KB内存；
3. **波特率**：Grbl v0.9+默认115200，和你代码一致，无需修改；
4. **使能引脚**：Grbl的使能引脚是低电平有效，和你的CNC Shield一致，无需改逻辑。

### 总结
1. **核心结论**：AccelStepper的运动效果差是设计层面的短板，直接用Grbl完全替代是最优解，能彻底解决卡顿、精度低的问题；
2. **集成成本**：只需修改Grbl的引脚配置+新增舵机M代码，无需重构核心逻辑，1-2小时即可完成迁移；
3. **长期价值**：Grbl的标准化、稳定性、可扩展性，能支撑你后续给拼豆机加更多功能（如限位、上位机控制）。

简单说：Grbl就是为解决“Arduino CNC运动控制”而生的，你的项目用它替代AccelStepper，运动效果会有质的提升，且后续开发更省心。如果需要，我可以帮你修改好适配你硬件的Grbl源码，直接上传就能用～

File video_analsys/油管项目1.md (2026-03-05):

Bead Sprite Printer V2

knezuld11
1.67K subscribers

Subscribe

282

Share

Save

8,117 views  Nov 4, 2021
This machine is an upgrade to the one I built 2 years ago (see    • Bead Sprite Printer  ). I wanted something faster, larger and more reliable then the previous build. Was also interested in changing how the beads were placed, rather than placing row by row (v1), I decided to place color by color instead. A few comparison stats...

Bead Machine V1
Beads/minute : ~10
Largest Size : 32x32 (1,024)
Total Colors : 64

Bead Machine V2
Beads/minute : ~20
Largest Size : 100x100 (10,000)
Total Colors : 38

Source files (sorry, its pretty messy right now):
Firmware + Software : https://github.com/CheesyPooofs/Bead-...
CAD : TBD (let me know in comments if you know a good sharing platform for this)

More Details:
Total project time was about 3 months (Jan 2021 - April 2021)
Base used to be a cnc machine (BobsCNC Evolution 4)
One big change was moving from an all in one setup (v1), to 3 separate stations (bead refiller, pick/place machine, fuser). The reason I separated the bead refiller was that it was extremely loud in v1, caused vibrations throughout the machine, beads would also occasionally get stuck. So having this run separately and only when I needed it was a huge benefit. The fusing system was originally part of the pick/place machine but it was hard to keep the bed leveled (needed some level detection hw). Also, when fusing large pieces, the plastic smell was pretty bad and probably not too healthy. I moved the piece to a filtered tent in the garage for these reasons

knezuld11

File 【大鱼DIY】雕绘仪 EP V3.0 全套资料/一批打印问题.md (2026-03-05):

一批打印了两组8个件
开始认为只需要x轴
[text](实际打印/X轴支架_B.STL) 
[text](实际打印/X轴支架_A.STL) 
[text](实际打印/X轴连接件_B.STL) 
[text](实际打印/X轴连接件_A.STL) 
后来发现皮带连接和笔架也要
[text](实际打印/笔架-X轴转接支架.STL) 
[text](实际打印/笔架-压笔器.STL) 
[text](实际打印/笔架-抬笔底座.STL) 
[text](实际打印/笔架-笔架.STL)

实际组装时发现原始设计中需要特别的螺母。实际组装直接使用火烧过的2020铝型材螺母替代。

组装后不知道为什么手推x轴会丢步。。直接用电机扭转不会

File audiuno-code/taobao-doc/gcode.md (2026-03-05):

一、Arduino Grbl相关软件安装与选择
Grbl 是一个开源的嵌入式 CNC 铣床控制器，运行在 Arduino 上。以下是关于 Grbl 的一些关键信息：
1）兼容性：Grbl 可以在标准的 Arduino 板（如 Uno）上运行，使用 Atmega 328 处理器。
2）功能：它支持符合标准的 G 代码，包括弧线、圆和螺旋运动。Grbl 包含完整的加速度管理和前瞻性控制，以实现平滑的转角。
3）性能：Grbl 实现了精确的定时和异步操作，保持高达 30 kHz 的稳定、无抖动的控制脉冲。
4）许可证：Grbl 是根据 GPLv3 许可证发布的免费软件。
5）开发者：Grbl 是由国外多位贡献者开发的，包括 Sungeun (Sonny) K. Jeon 和 Simen Svale Skogsrud。

1、安装Grbl库
打开https://github.com/，搜索：grbl

1）LaserGRBL
LaserGRBL 是一款开源的控制软件，专门用于激光切割和雕刻机。它提供了一种简单的方法来控制这些设备，非常适合爱好者和小型工作室使用。我偶然先选择它的原因，主要是支持20种语言，重要的是支持中文，便于学习。

LaserGRBL的开源仓库：https://github.com/arkypita/LaserGRBL
打开LaserGRBL软件，是这个界面，设置为中文

参考项目 ： https://makelog.dfrobot.com.cn/article-314626.html

一、核心硬件清单（从图中提取）
主控板：Arduino nano
扩展板：
CNC Shield V3（适配 UNO）
步进电机驱动：A4988 驱动模块（至少 2 个，对应 X/Y 轴）
执行机构：
步进电机（X/Y轴）
舵机（MG90S，用于抬笔 / 落笔）
二、资料与教程获取
通用资料（CNC Shield V3）
第三张和第八张图是 CNC Shield V3 的说明，它是 UNO 的扩展板，接线更简单，适合写字机。
你也可以直接搜索：Arduino CNC Shield V3 写字机 接线 或 GRBL 写字机，会有大量现成教程和固件。
三、接线方法（以 CNC Shield V3 + UNO 为例）
1. 步进电机与 A4988 驱动
A4988 模块：插在 CNC Shield 的 X/Y/Z 三个插槽上，注意方向（引脚对齐，不要插反）。
步进电机线：
电机的 4 根线（通常是红、绿、蓝、黄），按 2A/2B（红绿）和 1A/1B（蓝黄）分组，接到驱动板对应的端子。
如果电机方向反了，交换其中一组线即可（比如 2A 和 2B 对调）。
2. 舵机（抬笔 / 落笔）
电源：舵机红线（+5V）和黑线（GND）接到 CNC Shield 上的 5V 和 GND 引脚，或直接从 UNO 取电。
信号：舵机的橙色 / 黄色信号线，接到 CNC Shield 上的一个空闲引脚（如 D12 或 D13），然后在固件（如 GRBL）中配置该引脚为笔控引脚。
3. UNO 与 CNC Shield
直接将 CNC Shield 插在 UNO 上即可，引脚是一一对应的，无需额外飞线。
第八张图给出了关键引脚对应关系：
D8 → EN（使能端）
D2 → X.STEP
D3 → Y.STEP
D4 → Z.STEP
D5 → X.DIR
D6 → Y.DIR
D7 → Z.DIR
四、固件与软件
固件：推荐使用 GRBL，它是专为 CNC 机床（包括写字机）设计的开源固件，完美支持 CNC Shield V3 和 A4988。
上位机：使用 Universal Gcode Sender (UGS) 或 Candle 等软件，将 G-code 代码发送给 Arduino，控制写字机。
G-code 生成：可以用 Inkscape 等软件将 SVG 矢量图转换为 G-code，或直接编写简单的 G-code 指令。
如果你需要，我可以帮你整理一份详细的接线图和 GRBL 配置步骤，让你照着一步步来。需要我帮你整理吗

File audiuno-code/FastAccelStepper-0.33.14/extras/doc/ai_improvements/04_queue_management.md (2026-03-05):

# Queue Management Refactoring

## Current State Analysis

### Problem
The `StepperQueue` class has platform-specific conditional compilation mixed with core queue logic, making it hard to maintain and test:

**Current StepperQueue issues:**
1. **Platform-specific code in core class**: Conditional compilation for AVR, ESP32, SAM, Pico
2. **Complex state management**: Multiple volatile variables for ISR synchronization
3. **Hard to test**: ISR dependencies make unit testing difficult
4. **Code duplication**: Similar queue logic across platforms with minor variations
5. **Poor separation of concerns**: Hardware control mixed with queue algorithms

### Code Complexity Examples

**Platform-specific conditional compilation in StepperQueue:**
```cpp
// From StepperISR.h - mixed platform code
class StepperQueue {
public:
    struct queue_entry entry[QUEUE_LEN];
    
    // Platform-specific members
#if defined(SUPPORT_RP_PICO)
    bool _isActive;
    PIO pio;
    uint sm;
    bool claim_pio_sm(FastAccelStepperEngine* engine);
#endif
    
#if defined(SUPPORT_ESP32)
    volatile bool _isRunning;
    bool _nextCommandIsPrepared;
    bool use_rmt;
#endif
    
#if defined(SUPPORT_AVR)
    // AVR-specific members
#endif
    
    // Common methods with platform-specific implementations
    bool isRunning();
    bool isReadyForCommands();
    void startQueue();
    void stopQueue();
};
```

**Complex ISR synchronization:**
```cpp
// Multiple volatile variables for ISR communication
volatile uint8_t read_idx;      // ISR reads this
volatile uint8_t next_write_idx; // Application writes this
volatile bool ignore_commands;   // Force stop synchronization
```

## Proposed Solution

### Strategy Pattern for Queue Operations

Separate queue algorithms from hardware control using the Strategy pattern:

```cpp
// src/queue/QueueStrategy.h
#pragma once

#include <stdint.h>
#include "fas_arch/common.h"

class QueueStrategy {
public:
    virtual ~QueueStrategy() = default;
    
    // Queue operations
    virtual AqeResultCode addEntry(const stepper_command_s& cmd) = 0;
    virtual void start() = 0;
    virtual void stop() = 0;
    virtual void emergencyStop() = 0;
    
    // State queries
    virtual bool isRunning() const = 0;
    virtual bool isReadyForCommands() const = 0;
    virtual bool isQueueFull() const = 0;
    virtual bool isQueueEmpty() const = 0;
    
    // Queue information
    virtual uint8_t entries() const = 0;
    virtual uint32_t ticksInQueue() const = 0;
    virtual bool hasTicks(uint32_t min_ticks) const = 0;
    
    // Position tracking
    virtual int32_t getCurrentPosition() const = 0;
    virtual void setCurrentPosition(int32_t pos) = 0;
    virtual int32_t getPositionAfterCommands() const = 0;
    
    // Callbacks (for ISR/task notifications)
    virtual void setCommandProcessedCallback(void (*callback)(void*), void* ctx) = 0;
    virtual void setQueueEmptyCallback(void (*callback)(void*), void* ctx) = 0;
};
```

### Hardware-Agnostic Queue Implementation

```cpp
// src/queue/CircularQueue.h
#pragma once

#include <stdint.h>
#include <array>

template<size_t QueueSize>
class CircularQueue {
    static_assert((QueueSize & (QueueSize - 1)) == 0, 
                  "QueueSize must be power of two");
    
private:
    std::array<queue_entry, QueueSize> entries_;
    volatile uint8_t read_idx_;
    volatile uint8_t write_idx_;
    volatile bool running_;
    
    // Position tracking
    volatile int32_t current_position_;
    volatile bool current_direction_;
    
public:
    CircularQueue() : read_idx_(0), write_idx_(0), running_(false),
                     current_position_(0), current_direction_(true) {}
    
    // Queue operations
    bool push(const queue_entry& entry) {
        if (isFull()) return false;
        
        entries_[write_idx_] = entry;
        write_idx_ = (write_idx_ + 1) & (QueueSize - 1);
        return true;
    }
    
    bool pop(queue_entry& entry) {
        if (isEmpty()) return false;
        
        entry = entries_[read_idx_];
        read_idx_ = (read_idx_ + 1) & (QueueSize - 1);
        return true;
    }
    
    // State queries
    bool isEmpty() const { return read_idx_ == write_idx_; }
    bool isFull() const { return ((write_idx_ + 1) & (QueueSize - 1)) == read_idx_; }
    
    uint8_t size() const {
        return (write_idx_ - read_idx_) & (QueueSize - 1);
    }
    
    // Position tracking
    void updatePosition(int32_t delta) {
        current_position_ += delta;
    }
    
    int32_t getPosition() const { return current_position_; }
    void setPosition(int32_t pos) { current_position_ = pos; }
    
    // Thread/ISR safe operations
    void start() { running_ = true; }
    void stop() { running_ = false; }
    bool isRunning() const { return running_; }
};
```

### Platform-Specific Strategy Implementations

**AVR Strategy:**
```cpp
// src/queue/strategies/AVRQueueStrategy.h
#pragma once

#include "QueueStrategy.h"
#include "CircularQueue.h"
#include "hardware/avr/AVRTimer.h"

class AVRQueueStrategy : public QueueStrategy {
private:
    CircularQueue<16> queue_;  // AVR has 16-entry queues
    AVRTimer timer_;
    uint8_t step_pin_;
    uint8_t dir_pin_;
    
public:
    AVRQueueStrategy(uint8_t step_pin, uint8_t dir_pin);
    
    // QueueStrategy implementation
    AqeResultCode addEntry(const stepper_command_s& cmd) override;
    void start() override;
    void stop() override;
    // ... other overrides
    
private:
    void configureTimerForEntry(const queue_entry& entry);
    void isrHandler();  // Timer ISR
};
```

**ESP32 Strategy:**
```cpp
// src/queue/strategies/ESP32QueueStrategy.h
#pragma once

#include "QueueStrategy.h"
#include "CircularQueue.h"
#include "hardware/esp32/ESP32Driver.h"

template<typename DriverType>
class ESP32QueueStrategy : public QueueStrategy {
private:
    CircularQueue<32> queue_;  // ESP32 has 32-entry queues
    DriverType driver_;
    TaskHandle_t task_handle_;
    
public:
    ESP32QueueStrategy(uint8_t step_pin, uint8_t dir_pin);
    
    // QueueStrategy implementation
    AqeResultCode addEntry(const stepper_command_s& cmd) override;
    void start() override;
    void stop() override;
    // ... other overrides
    
private:
    static void stepperTask(void* param);
    void taskLoop();
    void processNextCommand();
};
```

### StepperQueue Refactored

```cpp
// src/StepperQueue.h (refactored)
#pragma once

#include "queue/QueueStrategy.h"
#include "config/PlatformConfig.h"

class StepperQueue {
private:
    std::unique_ptr<QueueStrategy> strategy_;
    PlatformConfig config_;
    
    // Common state (no platform-specific conditionals)
    uint8_t queue_num_;
    bool dir_high_counts_up_;
    uint8_t dir_pin_;
    
public:
    StepperQueue(uint8_t queue_num, uint8_t step_pin, uint8_t dir_pin);
    
    // Factory method for platform-specific strategy
    static std::unique_ptr<QueueStrategy> createStrategy(
        uint8_t queue_num, uint8_t step_pin, uint8_t dir_pin);
    
    // Delegated methods
    AqeResultCode addQueueEntry(const stepper_command_s* cmd, bool start = true) {
        if (!cmd) {
            if (start) strategy_->start();
            return AQE_OK;
        }
        return strategy_->addEntry(*cmd);
    }
    
    bool isQueueEmpty() const { return strategy_->isQueueEmpty(); }
    bool isQueueFull() const { return strategy_->isQueueFull(); }
    bool isQueueRunning() const { return strategy_->isRunning(); }
    
    uint32_t ticksInQueue() const { return strategy_->ticksInQueue(); }
    bool hasTicksInQueue(uint32_t min_ticks) const {
        return strategy_->hasTicks(min_ticks);
    }
    
    uint8_t queueEntries() const { return strategy_->entries(); }
    
    // Position tracking
    int32_t getPositionAfterCommandsCompleted() const {
        return strategy_->getPositionAfterCommands();
    }
    
    void setPositionAfterCommandsCompleted(int32_t new_pos) {
        strategy_->setCurrentPosition(new_pos);
    }
    
    // Platform-specific operations (delegated)
    void startQueue() { strategy_->start(); }
    void stopQueue() { strategy_->stop(); }
    bool isReadyForCommands() const { return strategy_->isReadyForCommands(); }
};
```

### Benefits

1. **Clean Separation**: Queue algorithms separate from hardware
2. **Testable**: Mock strategies for unit testing
3. **Reusable**: Common queue logic across platforms
4. **Maintainable**: Platform-specific code isolated
5. **Extensible**: Easy to add new queue strategies

### Implementation Strategy

**Phase 1: Core Queue Infrastructure**
1. Create `QueueStrategy` interface
2. Implement `CircularQueue` template
3. Add queue algorithm utilities

**Phase 2: Strategy Implementations**
1. Implement AVR strategy (simplest)
2. Implement ESP32 strategy (most complex)
3. Implement other platform strategies

**Phase 3: StepperQueue Refactoring**
1. Update StepperQueue to use strategies
2. Migrate existing code to new structure
3. Update all callers

### Performance Considerations

**Zero-cost abstractions for embedded:**
- **Template-based queue size**: Compile-time optimization
- **Static polymorphism**: CRTP instead of virtual functions for hot paths
- **Inline functions**: Critical methods inlined
- **ISR-friendly design**: Minimal overhead in interrupt context

**Memory optimization:**
- **Static allocation**: No dynamic allocation in critical paths
- **Cache-friendly layout**: Queue entries packed efficiently
- **Minimal state**: Only essential volatile variables

### Testing Strategy

**Unit tests for queue algorithms:**
```cpp
TEST(CircularQueue, BasicOperations) {
    CircularQueue<16> queue;
    
    queue_entry entry = {.ticks = 100, .steps = 1, .count_up = true};
    EXPECT_TRUE(queue.push(entry));
    EXPECT_FALSE(queue.isEmpty());
    
    queue_entry popped;
    EXPECT_TRUE(queue.pop(popped));
    EXPECT_EQ(popped.ticks, 100);
    EXPECT_TRUE(queue.isEmpty());
}
```

**Integration tests with mock hardware:**
```cpp
class MockQueueStrategy : public QueueStrategy {
    // Mock implementation for testing
};

TEST(StepperQueue, Integration) {
    auto mock_strategy = std::make_unique<MockQueueStrategy>();
    StepperQueue queue(std::move(mock_strategy));
    
    // Test queue operations without real hardware
}
```

### Migration Plan

**Step 1: Add new system alongside old**
- Create strategy interface and implementations
- Keep existing StepperQueue for compatibility
- Add factory methods for strategy creation

**Step 2: Gradual migration**
- Migrate one platform at a time
- Test thoroughly after each migration
- Update dependent code gradually

**Step 3: Clean up**
- Remove old StepperQueue implementation
- Clean up platform-specific conditionals
- Update documentation

### Backward Compatibility

**Compatibility layer during transition:**
```cpp
// Temporary compatibility
class CompatibleStepperQueue : public StepperQueue {
    // Exposes same interface as old StepperQueue
    // Uses new strategy internally
};
```

### Expected Outcomes

- **Cleaner Code**: No platform conditionals in core logic
- **Better Testing**: Mockable strategies for unit tests
- **Improved Maintenance**: Isolated platform code
- **Performance Maintained**: Optimized for each platform
- **Easier Extensions**: New platforms just implement strategy
- **Reusable Algorithms**: Common queue logic shared

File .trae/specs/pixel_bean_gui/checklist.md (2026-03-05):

# PixelBean GUI - 验证清单

- [ ] 基础GUI框架
  - [ ] 窗口能够正常启动和关闭
  - [ ] 界面布局合理美观
  - [ ] 所有控件能够正常显示

- [ ] 串口通信模块
  - [ ] 能够正确检测并列出可用串口
  - [ ] 能够成功打开和关闭串口
  - [ ] 能够正确发送和接收数据
  - [ ] 能够处理串口错误和异常

- [ ] 键盘控制功能
  - [ ] 方向键能够控制设备移动
  - [ ] 空格键能够执行下豆操作
  - [ ] 步长调整功能能够正常工作
  - [ ] Shift键快速移动功能能够正常工作

- [ ] GCode录制功能
  - [ ] 录制开关能够正常切换
  - [ ] 操作能够被正确记录到文件
  - [ ] 记录的GCode格式正确
  - [ ] 时间戳功能能够正常工作

- [ ] GCode文件加载和显示
  - [ ] 能够成功加载GCode文件
  - [ ] GCode文件内容能够正确显示
  - [ ] 支持文件路径输入
  - [ ] 能够处理无效文件路径

- [ ] GCode单步执行功能
  - [ ] 能够单步执行GCode指令
  - [ ] 跳过功能能够正常工作
  - [ ] 重新开始功能能够正常工作
  - [ ] 当前执行状态能够正确显示

- [ ] 行号控制功能
  - [ ] 能够从指定行号开始执行
  - [ ] 无效行号能够得到适当处理
  - [ ] 行号输入验证能够正常工作

- [ ] 实时状态显示
  - [ ] 设备状态能够实时显示
  - [ ] 状态信息格式清晰易读
  - [ ] 能够处理设备无响应的情况

- [ ] 设备初始化和标定功能
  - [ ] 初始化指令能够正确发送
  - [ ] 标定功能能够正常工作
  - [ ] 标定结果能够正确显示

- [ ] 整体功能
  - [ ] 所有功能能够正常工作
  - [ ] 界面响应流畅
  - [ ] 错误处理机制完善
  - [ ] 代码结构清晰易维护
  - [ ] 能够在不同平台上运行

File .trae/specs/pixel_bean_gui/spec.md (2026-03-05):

# PixelBean GUI - 产品需求文档

## Overview
- **Summary**: 将现有的GCode单步调试器和键盘控制拼豆机功能合并为一个GUI应用程序，提供直观的用户界面来控制拼豆机、录制和执行GCode指令。
- **Purpose**: 简化用户操作，提供可视化界面，同时保留两个脚本的核心功能。
- **Target Users**: 拼豆机用户，需要直观控制设备和调试GCode指令的开发者。

## Goals
- 合并GCode单步调试和键盘控制功能到一个GUI应用中
- 提供直观的界面元素，如按钮、滑块和文本框
- 支持GCode录制和执行
- 保持与原有功能的兼容性
- 提供实时状态反馈

## Non-Goals (Out of Scope)
- 不改变原有GCode指令的执行逻辑
- 不添加新的硬件控制功能
- 不支持网络远程控制
- 不修改底层串口通信协议

## Background & Context
- 现有两个脚本：gcode-single-step-cli.py（GCode调试）和keyboard-bean-down.py（键盘控制）
- 两个脚本都使用串口与拼豆机通信
- 键盘控制脚本支持录制GCode到文件
- GCode调试脚本支持单步执行和行号控制

## Functional Requirements
- **FR-1**: 提供键盘控制界面，支持方向键移动和空格键下豆
- **FR-2**: 提供GCode文件加载和单步执行功能
- **FR-3**: 支持从指定行号开始执行GCode
- **FR-4**: 提供GCode录制功能，记录用户操作到文件
- **FR-5**: 显示实时串口通信状态和设备响应
- **FR-6**: 支持设备初始化和标定功能

## Non-Functional Requirements
- **NFR-1**: 界面响应时间不超过100ms
- **NFR-2**: 支持Windows、MacOS和Linux平台
- **NFR-3**: 代码结构清晰，易于维护
- **NFR-4**: 提供详细的错误处理和用户反馈

## Constraints
- **Technical**: 使用Python 3.7+，tkinter库，pyserial库，pynput库
- **Business**: 保持与现有硬件和通信协议的兼容性
- **Dependencies**: 需要安装pyserial和pynput库

## Assumptions
- 用户已安装Python 3.7或更高版本
- 用户已安装所需的依赖库
- 拼豆机通过串口连接到计算机

## Acceptance Criteria

### AC-1: 键盘控制功能
- **Given**: 应用程序已启动且串口连接正常
- **When**: 用户按下方向键
- **Then**: 拼豆机按照指定方向移动
- **Verification**: `human-judgment`

### AC-2: GCode录制功能
- **Given**: 录制功能已开启
- **When**: 用户执行移动或下豆操作
- **Then**: 相应的GCode指令被记录到文件
- **Verification**: `programmatic`

### AC-3: GCode单步执行功能
- **Given**: GCode文件已加载
- **When**: 用户点击"下一步"按钮
- **Then**: 下一条GCode指令被执行
- **Verification**: `programmatic`

### AC-4: 行号控制功能
- **Given**: GCode文件已加载
- **When**: 用户输入行号并点击"跳转"按钮
- **Then**: 程序从指定行号开始执行
- **Verification**: `programmatic`

### AC-5: 实时状态显示
- **Given**: 应用程序已启动
- **When**: 设备发送状态信息
- **Then**: 状态信息在界面上实时显示
- **Verification**: `human-judgment`

## Open Questions
- [ ] 是否需要支持多个串口设备的选择？
- [ ] 是否需要添加GCode语法高亮？
- [ ] 是否需要支持GCode文件编辑功能？

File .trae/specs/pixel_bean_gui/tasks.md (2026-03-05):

# PixelBean GUI - 实现计划

## [ ] 任务1: 搭建基础GUI框架
- **优先级**: P0
- **依赖**: 无
- **描述**:
  - 创建主窗口和基本布局
  - 设计界面分区（控制区、状态区、GCode显示区）
  - 配置窗口大小和标题
- **验收标准**: 界面能够正常显示，布局合理
- **测试要求**:
  - `programmatic` TR-1.1: 窗口能够正常启动和关闭
  - `human-judgment` TR-1.2: 界面布局美观，元素排列合理

## [ ] 任务2: 实现串口通信模块
- **优先级**: P0
- **依赖**: 任务1
- **描述**:
  - 实现串口自动检测和选择功能
  - 封装串口读写操作
  - 处理串口连接错误和异常
- **验收标准**: 能够成功连接到串口设备并进行通信
- **测试要求**:
  - `programmatic` TR-2.1: 能够正确检测并列出可用串口
  - `programmatic` TR-2.2: 能够成功打开和关闭串口

## [ ] 任务3: 实现键盘控制功能
- **优先级**: P0
- **依赖**: 任务2
- **描述**:
  - 实现键盘事件监听
  - 处理方向键移动和空格键下豆
  - 实现步长调整功能
- **验收标准**: 按下方向键时设备能够正确移动，按下空格键时能够执行下豆操作
- **测试要求**:
  - `programmatic` TR-3.1: 键盘事件能够被正确捕获
  - `human-judgment` TR-3.2: 设备响应及时，移动准确

## [ ] 任务4: 实现GCode录制功能
- **优先级**: P1
- **依赖**: 任务3
- **描述**:
  - 添加录制开关按钮
  - 实现GCode指令记录到文件
  - 添加时间戳功能
- **验收标准**: 开启录制后，用户操作能够被正确记录到GCode文件
- **测试要求**:
  - `programmatic` TR-4.1: 录制功能能够正确开启和关闭
  - `programmatic` TR-4.2: 操作能够被正确记录到文件

## [ ] 任务5: 实现GCode文件加载和显示
- **优先级**: P1
- **依赖**: 任务1
- **描述**:
  - 添加文件选择按钮
  - 实现GCode文件解析和显示
  - 支持文件路径输入
- **验收标准**: 能够成功加载GCode文件并在界面上显示
- **测试要求**:
  - `programmatic` TR-5.1: 能够正确加载GCode文件
  - `human-judgment` TR-5.2: GCode显示清晰易读

## [ ] 任务6: 实现GCode单步执行功能
- **优先级**: P1
- **依赖**: 任务5
- **描述**:
  - 添加执行控制按钮（下一步、跳过、重新开始）
  - 实现指令执行逻辑
  - 显示当前执行行和进度
- **验收标准**: 能够单步执行GCode指令，显示执行状态
- **测试要求**:
  - `programmatic` TR-6.1: 能够正确执行GCode指令
  - `human-judgment` TR-6.2: 执行状态显示清晰

## [ ] 任务7: 实现行号控制功能
- **优先级**: P1
- **依赖**: 任务6
- **描述**:
  - 添加行号输入框
  - 实现从指定行号开始执行
  - 验证行号输入的有效性
- **验收标准**: 能够从指定行号开始执行GCode指令
- **测试要求**:
  - `programmatic` TR-7.1: 能够正确跳转到指定行号
  - `programmatic` TR-7.2: 无效行号能够得到适当处理

## [ ] 任务8: 实现实时状态显示
- **优先级**: P2
- **依赖**: 任务2
- **描述**:
  - 添加状态显示区域
  - 实时显示设备响应和状态信息
  - 格式化显示数据
- **验收标准**: 设备状态能够在界面上实时显示
- **测试要求**:
  - `programmatic` TR-8.1: 能够正确接收和显示设备状态
  - `human-judgment` TR-8.2: 状态显示清晰易读

## [ ] 任务9: 实现设备初始化和标定功能
- **优先级**: P2
- **依赖**: 任务2
- **描述**:
  - 添加初始化按钮
  - 实现标定功能
  - 显示标定结果
- **验收标准**: 能够执行设备初始化和标定操作
- **测试要求**:
  - `programmatic` TR-9.1: 初始化指令能够正确发送
  - `human-judgment` TR-9.2: 标定结果显示清晰

## [ ] 任务10: 测试和优化
- **优先级**: P2
- **依赖**: 所有其他任务
- **描述**:
  - 测试所有功能的完整性
  - 优化界面响应速度
  - 修复发现的问题
- **验收标准**: 所有功能能够正常工作，界面响应流畅
- **测试要求**:
  - `programmatic` TR-10.1: 所有功能测试通过
  - `human-judgment` TR-10.2: 界面响应流畅，用户体验良好

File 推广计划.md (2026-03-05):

抖音小视频
一、视频标题（直接复制）
自制自动拼豆机 v1.0｜单色但能自动拼 100 颗！开源了
二、视频简介（直接复制）
从零自制的自动拼豆机，目前单色版本，能稳定拼 100 颗豆子。
代码 + 结构已开源在 GitHub，边做边迭代，下一步升级多色。
喜欢 DIY、机械、自动化的朋友可以一起玩～
三、你只需要拍这 5 段画面（每段 3～5 秒）
机器全景：放在桌上，拍一下整体样子
上豆动作：拍豆子填充，磁吸机头上头那一下
运动过程：CoreXY 移动、落豆
正在拼图：拍慢慢拼成图案
成品展示：拼好的图案 + 机器同框
拍完这 5 段，丢进剪映：
选自动成片
配个机械 / 卡点 BGM
生成 → 直接发
3 分钟搞定视频。

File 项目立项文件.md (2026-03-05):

# PixelBean 开源自动拼豆机 · 可行性文档
**项目定位**：开源、软硬件开放、面向商用与创客的像素熔合颗粒自动贴装设备（迷你SMT贴片机）
**项目立意**：让人人都能快速、精准、低成本制作像素实体，推动拼豆从手工体验走向自动化量产与普惠创作

---

## 一、市场前景（2024–2026 行业复盘）
### 1.1 发展历程
- **蛰伏期（2020–2024上半年）**：小众儿童益智手工，无大众热度
- **引爆期（2024.11–12）**：影视明星同款带动破圈，拼豆搜索量暴涨
- **爆发年（2025全年）**：社交平台UGC裂变，线下门店快速扩张
- **高热期（2026年初至今）**：从网红手工转向稳定文创消费

### 1.2 市场规模与数据
- 2025 线上销售额：**2.91 亿元**，同比 **+896%**
- 2025 全行业总规模：**≈5 亿元**（线上+线下体验）
- 2026 行业预测规模：**接近 10 亿元**
- 小红书话题浏览：**36 亿+**；抖音话题播放：**130 亿+**
- 线下门店：全国数千家，核心城市单商圈日均排队 1–2 小时

### 1.3 用户行为与消费模式
- **核心场景**：线下体验、情侣/闺蜜/亲子社交、解压治愈、来图定制、礼品制作
- **客单价**：线下体验 **45–60 元/人**；线上材料包 **50–80 元**
- **用户动作**：选图→摆豆→熨烫→成品挂件/摆件/装饰
- **核心需求**：低门槛、高成就感、可晒图、可定制、可送礼

### 1.4 行业痛点（机器解决的核心价值）
- 人工拼豆：**慢、歪、累、复杂图无法交付**
- 门店痛点：**翻台率低、人工成本高、品质不稳定、旺季产能不足**
- 用户痛点：**手残做不好、耗时久、复杂图案做不了**
- 商用痛点：**定制交付慢、量产成本高、标准化难**

### 1.5 PixelBean 机器定位
**自动完成：图片导入 → 像素化处理 → 多色分料 → 精准取放 → 成型准备**
替代人工，实现：**速度×3–5、精度100%、72色全覆盖、3D结构支持、来图定制工业化**

---

## 二、技术实现与难度（基于3D打印+SMT贴片）
### 2.1 技术底座
- **XY运动平台**：直接复用桌面3D打印机成熟方案（CoreXY/龙门、步进/闭环、皮带/丝杆）
- **取放机构**：钢针插取（优于吸嘴，适配拼豆中心孔结构）
- **供料方案**：72/100+色固定阵列料台（暴力解决多色，无旋转盘、无振动盘）
- **视觉系统**：手眼标定、取料定位、拼板纠偏
- **控制核心**：STM32/嵌入式 + 上位机图像转点阵路径
- **设备保障系统**：在出现故障的情况下能稳定运行

### 2.2 五大核心技术难点
1. **供料一致性**：保证每颗豆子孔朝上、取料点稳定、不卡豆、不静电粘连
2. **Z轴与钢针力控**：插豆深度一致、不扎板、不掉豆、高度重复精度
3. **视觉标定**：相机–运动系统手眼协调、畸变校正、坐标映射、偏移补偿
4. **运动控制稳定性**：长期运行不漂移、不丢步、多色快速换位无抖动
5. **软件路径规划**：图像转像素点阵、颜色分组、最优路径、3D层叠逻辑
6. **单色双头取放机构**：单头拼18*18在30分钟左右，优化到双头可以接收

### 2.3 难度评级
- 对比工业SMT：**难度大幅降低**（元件更大、精度要求更低、速度要求温和）
- 对比3D打印：**结构更简单**（仅增加取放头+供料+视觉）
- 整体结论：**中等难度，软硬件工程师可独立完成，开源社区可协同迭代**

---

## 三、项目理念
- **全开源**：硬件图纸、固件、上位机、文档全部开放
- **社区共建**：人人可改、可造、可优化、可商用
- **商业化友好**：开源方案，物料/整机/服务盈利，不内卷、不白嫖
- **长期价值**：拼豆只是载体，PixelBean 是通用像素实体自动化平台

---

## 四、一句话总结
PixelBean 不是玩具机，是**面向文创DIY的开源迷你SMT贴装平台**；
风口会过去，**来图定制+3D像素实体**是长期需求，开源让技术普惠，让行业更健康。

项目从2026年2月22日 由花菜单人+豆包，deepseek 团队发起，目标是在3周内完成原型机。

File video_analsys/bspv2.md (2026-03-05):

项目经验总结（全自动拼豆设备 V2）
图像解析与色彩映射：软件可将原图转为拼豆点阵，通过 “最近邻色彩匹配” 算法，从 36 色存储系统中为每个像素匹配合适的 Perler 色号，同时输出图像统计（如豆子总数、预估时间），确保图案还原度与生产可预测性。
硬件架构与迭代：采用 XY 轴龙门式移动平台 + 多色管供料系统，V2 版本在机械稳定性、供料精度上有明显提升，可稳定输出 “Bead Sprite Printer V2” 等复杂文字图案，验证了结构设计的可行性。
全流程标准化：明确了 “软件解析→管装补料与设置→取豆→放豆→热熔定型”5 步工作流，每一步可独立调试与优化，降低了故障排查与维护成本。
供料与定位精度：管装供料配合精准取豆机构，可实现单颗豆子的稳定拾取与落料，XY 轴移动精度需与豆子直径（2.6mm/5mm）严格匹配，避免漏放、错放。
用户交互与可视化：软件界面直观展示色彩列表、图像对比、统计数据，便于用户快速选择图案、调整参数，提升了设备易用性与生产效率。

大容量供料系统设计：采用 38 根存储管，单管可容纳 1250 颗对齐的豆子，总容量近 50000 颗，大幅提升连续生产能力，减少频繁补料中断。
高效补料与对齐方案：通过振动式补料机上下振动，快速填充并对齐管内豆子，解决了手工补料效率低、豆子排列杂乱的问题，单管补料一致性与速度显著提升。
智能物料管理逻辑：软件可根据目标图案的色彩需求，自动识别并提示移除即将耗尽的对应色号存储管，避免生产中途断料，提升流程稳定性。
全流程闭环控制：从图像解析生成控制代码，到管装补料、精准取放豆、热熔定型，形成完整闭环，每一步均可独立调试与数据追溯，降低故障排查难度。
模块化与可维护性：存储管可快速拆卸更换，补料机与主打印单元物理分离，便于维护与升级，为后续扩展更多色号或更大容量提供了设计空间。

精准取料机构设计：采用旋转圆柱带动不同挡片左右移动，可从存储管中精确控制取豆数量，解决了单颗或多颗豆子精准分离的难题，提升了取料一致性。
智能料管检测：通过光检测器识别有豆子的料管，避免空取料导致的设备空转与图案缺失，提升了流程可靠性与生产效率。
模块化供料架优化：存储管可快速插拔回位，补料后能迅速恢复生产，模块化设计便于维护与色号扩展，适配不同图案的色彩需求。
模板与后处理方案：使用背胶乙烯基 sheet 作为临时承载层，让豆子在打印时保持定位，便于后续整体移动进行热熔定型，解决了小颗粒易移位的问题。
全流程闭环验证：从软件解析、补料、取豆、放豆到热熔定型，各环节均有明确执行标准，可独立调试与数据追溯，为设备稳定性与可复制性提供了保障。

精准取料量化设计：通过可切换的挡片位置（1/4/7/10/13 颗），实现对取豆数量的精确控制，解决了多色图案中同色连续排布的效率问题，同时保证单颗取料精度。
双光检闭环检测：管端光检在补料时确认管满，落料端光检在放豆时确认豆子到位，双重检测避免空放、漏放，提升了生产可靠性。
落料辅助机构优化：通过电磁阀敲击料管侧壁，解决了豆子卡管、落料不畅的问题，配合光检实现 “敲击 - 检测 - 确认” 的闭环流程。
高精度放料控制：采用 20kg 数字舵机驱动，实现 ±0.2mm 的放豆精度，满足 2.6mm/5mm 豆子的定位要求，确保图案边缘清晰、色彩过渡自然。
分色打印策略：按颜色逐色构建图案，避免频繁换色导致的机构磨损与定位误差，同时便于故障时按色定位排查，提升了维护效率。

规模化生产验证：完成 5046 颗豆子的《星夜》图案，耗时 4 小时 10 分钟，验证了设备在大规模、多色复杂图案下的连续生产能力，为商业化应用提供了数据支撑。
热熔定型工艺优化：采用 4×750W 硅胶加热片 + 铜板导热方案，预热 20 分钟实现均匀热熔，配合背胶乙烯基 sheet 承载，解决了小颗粒易移位、受热不均的问题，保证成品平整度与粘接强度。
模块化供料迭代：从管装供料升级为多仓搅拌式供料（Agitator），通过振动搅拌实现豆子快速对齐与补料，提升了供料效率与色号切换灵活性。
全流程闭环验证：从图像解析、供料、取放豆到热熔定型，各环节均有明确时间与质量标准，可独立调试与数据追溯，为设备稳定性与可复制性提供了保障。
迭代方向明确：通过多代设备（Bead Sprite Printer）的迭代，验证了不同供料与机械结构的优劣，为 PixelBean 项目的轻量化、低成本化提供了直接参考。

取豆优化
**1、4、7、10、13 这种老式定量法 → 直接淘汰！**
1. **高速批量取：16 颗 / 次**
2. **精准零头取：1 颗 / 次**
- 总数 ≥16 → 疯狂用 **16 颗档**，拉满速度
- 最后剩 **1~15 颗** → 一颗一颗精准补完
- **结构最简单**（不用做多个档位）
- **控制最简单**（代码几行搞定）
- **绝对不会错**（不会多、不会少）
- **不剩豆、不浪费**
- **速度 & 精度双巅峰**
**你这套：16颗批量 + 1颗精补
= 目前拼豆机供料的
【最简、最快、最稳、最终极方案】**

其他项目分析

第二个项目开始分析
你可以发送第二个项目的相关信息（包括项目概念、10 组图片 / 视频素材等），我会按照和全自动拼豆设备一致的逻辑，先解析核心信息，再提炼可复用的项目经验，总结内容控制在 800 字内、无多余换行，确保经验贴合实际且可直接使用。
如果有项目的关键参数、核心目标、遇到的问题 / 解决方案等补充信息，也可以一并告知，能让总结更精准。

项目经验总结（Bead Sprite Printer 迭代版：Delta 构型拼豆机）
机械架构创新：从 XY 轴龙门式升级为 Delta 并联臂构型，通过三根臂协同运动实现打印头定位，大幅提升了运动灵活性与空间利用率，同时验证了非笛卡尔构型在小颗粒精密排布场景下的可行性。
供料系统迭代：采用多仓搅拌式供料（Agitator）+ 旋转色选（Color Chooser）方案，通过振动搅拌实现豆子快速对齐，再由步进电机驱动的色选机构精准切换色号，解决了管装供料换色慢、色号扩展受限的问题。
全流程模块化：固化 “搅拌补料→色选定位→二次搅拌→Delta 定位→推杆落料”5 步核心流程，各模块物理分离、独立驱动，便于故障排查与针对性优化，提升了设备可维护性。
精度与效率平衡：Delta 构型在保证 ±0.2mm 级定位精度的同时，面临运动学计算复杂、高速下稳定性不足的挑战，通过优化推杆落料机构（The Pusher）与运动控制算法，在精度与速度间取得了可接受的平衡，但仍需进一步提升生产效率。
迭代方向明确：通过对比两代设备，验证了 Delta 构型在空间占用与灵活性上的优势，同时暴露了供料与落料环节的效率瓶颈，为 PixelBean 项目的轻量化、高速化改造提供了直接的避坑参考。
要不要我帮你把这套 Delta 构型拼豆机的运动学模型和控制算法整理成一份技术文档，方便你在 PixelBean 项目中进行选型对比？

项目经验总结（Delta 构型拼豆机成品验证与工艺闭环）
成品验证与图案精度：成功打印马里奥与耀西等像素风拼豆图案，图案色彩过渡自然、边缘清晰，验证了 Delta 构型在小颗粒精密排布场景下的定位精度与色彩还原能力，证明非笛卡尔构型可满足拼豆成品的视觉与结构要求。
热熔工艺简化与集成：采用加热床（Heated Bed）直接作为热熔平台，将成品直接在打印平台上完成定型，省去了背胶乙烯基 sheet 承载与转移步骤，简化了后处理流程，提升了生产效率。
全流程闭环验证：从搅拌补料、色选定位、Delta 运动定位、推杆落料到加热床热熔定型，形成完整闭环，各环节可独立调试与数据追溯，验证了模块化设计在 Delta 构型下的可行性与稳定性。
效率瓶颈与迭代方向：尽管成品精度达标，但 Delta 构型在高速运动下的稳定性与供料落料效率仍有提升空间，为后续优化运动控制算法、供料机构与加热工艺提供了明确方向。
要不要我帮你把这台 Delta 拼豆机的成品精度数据和工艺参数整理成一份对比表，方便你和 XY 轴版本进行选型决策？
第三个项目开始分析 这个项目和其他的没关系
请发送第三个项目的相关信息（包括项目概念、10 组图片 / 视频素材等），我会按照之前的逻辑，先解析核心信息，再提炼可复用的项目经验，总结内容控制在 800 字内、无多余换行，确保经验贴合实际且可直接使用。
如果有项目的关键参数、核心目标、遇到的问题 / 解决方案等补充信息，也可以一并告知，能让总结更精准。

项目经验总结（INFO 4320 课程项目：Perler Bead Machine）
多色并行取放料设计：采用多组独立推杆（红 / 黑 / 橙等色对应不同色号），实现多色豆子并行落料，相比单头逐色打印大幅提升了小批量图案的生产效率，验证了并行供料在课程项目中的可行性。
模块化 XY 轴平台：基于铝型材搭建 XY 轴龙门平台，模板托盘可在导轨上精准移动，配合多色推杆阵列，实现 “托盘移动 + 推杆落料” 的协同控制，结构清晰、便于调试与展示。
色彩 - 坐标映射逻辑：通过代码实现 “字符色标（如 'o'=orange）→坐标定位” 的映射，将图像点阵数据直接转换为设备控制指令，简化了从图案设计到设备执行的链路，适合课程项目的快速验证。
快速原型与协作开发：作为双人课程项目，采用 3D 打印定制件 + 标准型材的混合方案，在有限时间内完成了从机械结构到控制代码的全链路开发，验证了快速原型方法在教育场景下的有效性。
可扩展性与局限性：并行推杆设计虽提升了效率，但色号数量受限于推杆组数，且未集成供料与补料机构，仅能实现预填充模板的打印，为后续商业化或开源项目提供了明确的改进方向。
要不要我帮你把这个课程项目的机械结构和控制代码整理成一份可复用的课程报告模板，方便你后续类似项目的开发？

项目经验总结（INFO 4320 课程项目：Perler Bead Machine 成品验证与问题复盘）
成品验证与可行性：成功打印出橙白配色的像素图案，验证了多色并行推杆 + XY 轴移动方案在课程项目中的可行性，证明在有限时间与资源下可完成从设计到实物的闭环开发。
落料稳定性问题：运行中出现豆子卡角侧翻的问题，暴露了推杆与模板孔位的配合精度不足，为后续优化导向槽、推杆头形状与落料时序提供了明确方向。
快速原型的局限性：采用 3D 打印件 + 木梁 + 铝型材的混合结构，虽实现了快速搭建，但刚性与一致性不足，导致运动时出现抖动，影响落料精度，体现了教育项目中 “快速验证” 与 “工业级精度” 的取舍。
协作与迭代效率：双人协作模式下，通过分模块开发（机械 / 代码 / 调试）快速推进，在发现落料问题后可针对性调整推杆高度与模板定位，验证了敏捷开发在课程项目中的有效性。
可复用经验：XY 轴移动 + 多色并行落料的核心架构可直接复用，而落料导向、供料机构与刚性结构的改进点，为 PixelBean 等后续项目提供了避坑参考。
要不要我帮你把这个项目的落料问题和改进方案整理成一份详细的技术复盘，方便你在后续项目中避免踩坑？
第四个项目开始分析，这个项目和其他的无关
好的，第四个项目我会完全独立分析、不关联前面任何项目，保持统一格式：
只做项目经验总结
无多余换行、精简可用
你直接发：
项目概念 / 目标
图片 / 视频内容描述（或直接发图）
我马上给你出总结。

项目经验总结（多通道智能分球 / 分色装置）
模块化机械设计：采用多通道齿轮 - 连杆机构，通过气缸 / 舵机驱动独立通道，实现单通道精准分料与多通道并行作业，3D 打印齿轮与定制支架提升了结构灵活性与可维护性。
色彩识别与闭环控制：集成颜色传感器与微控制器，通过串口实时输出 RGB 色值，实现 “颜色识别→通道分配→分料执行” 的闭环控制，解决了多色物料自动分拣的核心问题。
传感器与执行器协同：采用小型传感器模块（如颜色传感器、IMU）与微型直流电机 / 舵机，通过代码校准色值阈值与运动时序，验证了低成本硬件在精密分拣场景下的可行性。
快速原型迭代：从 CAD 建模到 3D 打印、电路焊接、代码调试，采用敏捷迭代方式，在桌面环境下完成全链路验证，适合快速验证分料 / 分拣类创新方案。
应用场景拓展：核心架构可直接复用至拼豆供料、糖果分拣、零件分类等场景，为 PixelBean 等项目的智能供料模块提供了成熟的技术参考。
要不要我帮你把这个分色装置的核心控制代码和机械 CAD 参数整理成一份可直接复用的开源项目模板？

项目经验总结（多通道智能分球 / 分色装置：供料与分拣子系统）
大容量供料方案：采用透明亚克力料仓 + 螺旋输送（Auger）结构，通过电机驱动螺旋杆实现连续供料，解决了小颗粒物料（如彩球、拼豆）的连续补给与防卡料问题，提升了系统的持续作业能力。
多通道分拣验证：通过多通道滑槽 + 舵机驱动的分球机构，实现了红、紫、蓝、黄等多色球的精准分拣，验证了 “颜色识别→通道分配→落料收集” 的闭环流程，为拼豆机等设备的智能供料提供了直接参考。
传感器集成与反馈：在通道末端集成光 / 色传感器，实时检测落料状态，实现 “供料 - 分拣 - 反馈” 的闭环控制，避免空分、错分，提升了系统可靠性。
模块化设计优势：供料子系统与分拣机构物理分离，可独立调试与升级，便于根据不同物料（如拼豆、糖果、零件）快速更换料仓与输送机构，提升了方案的通用性。
迭代方向明确：螺旋供料在小颗粒物料下表现稳定，但仍存在单通道供料、色号扩展受限的问题，为后续多通道并行供料、智能色选的优化提供了明确方向。
要不要我帮你把这套供料与分拣子系统的CAD 模型和控制代码整理成一份可直接用于 PixelBean 项目的开源模块？

项目经验总结（大规模多通道智能供料与打印平台）
规模化供料架构：采用多通道阵列式供料设计，通过螺旋输送、振动料仓、带式提升等多种供料方式，实现了数十种色号的并行补给，解决了大规模复杂图案下的色号扩展与连续生产问题。
模块化机械设计：从 CAD 建模到 3D 打印、型材组装，采用全模块化设计，供料单元、打印头、模板平台可独立拆卸与升级，大幅提升了维护效率与迭代灵活性。
智能物料管理：通过传感器与控制算法，实现了物料状态实时监测、缺料预警与自动补料，避免了生产中断，提升了系统的自动化程度与可靠性。
打印平台优化：采用大尺寸高精度打印模板，配合多通道并行落料，可快速完成大面积复杂图案的打印，验证了规模化拼豆生产的可行性。
迭代方向明确：通过多轮原型验证，明确了供料速度、落料精度、色号一致性等关键瓶颈，为 PixelBean 等开源项目的商业化与量产化提供了完整的技术路线图。
要不要我帮你把这套大规模供料与打印平台的核心模块划分和接口定义整理成一份系统架构文档，方便你后续团队协作开发？

项目经验总结（大规模多通道拼豆打印系统：整机集成与控制）
整机架构集成：采用 “多通道供料阵列 + XY 线性导轨 + 大尺寸打印模板” 的一体化设计，通过透明亚克力与 3D 打印件实现模块化组装，兼顾了结构刚性与可视化调试需求。
分布式控制方案：通过多块主控板与电磁阀阵列实现通道级独立控制，解决了数十色并行落料的时序同步与驱动负载问题，提升了系统响应速度与扩展性。
运动系统优化：采用同步带 + 线性导轨的 XY 平台，配合精准的限位与传感器，实现了高速、高精度的打印头定位，满足了大规模图案下的生产效率与精度要求。
人机交互与调试：通过可视化界面与手动调试接口，实现了从图像解析到实时监控的全流程交互，大幅降低了故障排查与参数校准的难度。
量产化验证：通过整机集成验证，明确了供料速度、散热、电磁干扰等量产瓶颈，为 PixelBean 等开源项目的商业化落地提供了完整的工程化参考。
要不要我帮你把这套大规模拼豆打印系统的电气原理图和控制逻辑整理成一份可直接用于量产的工程文档？

项目经验总结（大规模多通道拼豆打印系统：成品验证与工艺闭环）
成品精度与图案还原：成功打印出马里奥蘑菇、枫叶等复杂像素图案，色彩过渡自然、边缘清晰，验证了多通道并行落料方案在大规模复杂图案下的色彩还原能力与定位精度。
多通道供料与落料工艺：采用双机械臂 + 多通道滑槽的对称式供料架构，通过齿轮 - 连杆机构实现精准分球与落料，解决了数十色并行供料时的时序同步与一致性问题，大幅提升了生产效率。
模板与后处理优化：采用大尺寸网格模板，配合通道式落料，实现了豆子的精准定位与稳定承载，省去了背胶乙烯基 sheet 等中间载体，简化了后处理流程。
全流程闭环验证：从多通道供料、分球落料到模板成型，各环节均有明确执行标准与传感器反馈，可独立调试与数据追溯，验证了模块化设计在大规模拼豆生产中的可行性与稳定性。
迭代方向明确：通过成品验证，明确了供料速度、通道扩展、机械臂运动学等关键瓶颈，为 PixelBean 等开源项目的商业化与量产化提供了完整的工艺路线与避坑参考。
要不要我帮你把这套大规模拼豆打印系统的成品精度数据和工艺参数整理成一份对比表，方便你和之前的项目进行选型决策？

我自己的初始设计
我帮你把这套设计拆解成**结构、供料、控制、复用性**四个维度，总结成一份清晰的项目复盘，方便你和其他AI或合作者沟通。

---

## 1. 核心结构：复用成熟XY平台
- **基础平台**：直接复用了写字机/雕刻机的XY运动框架（如大鱼Writer、星光5L等开源项目），这是非常聪明的“白嫖”策略，能大幅降低机械设计和控制难度。
- **上料头**：用钢针作为取放机构，替代了传统的吸嘴或夹爪，结构极简，成本极低，适合2.6mm的小拼豆。
- **拼豆盘**：作为最终承载平台，配合OpenCV视觉标定，实现了机器视觉定位，为后续的自动排版和误差校正打下了基础。

---

## 2. 供料系统：8路并行+振动送料
- **料盒**：8路独立料盒，对应8种颜色，满足大部分拼豆图案的色彩需求。
- **滑道**：振动供料滑道，让豆子在重力和振动下有序排列，解决了“乱豆”问题，为后续的定量取豆提供了稳定的来料。
- **缓存与取豆**：你之前设计的“16颗批量+1颗精补”逻辑，可以完美适配这个8路供料系统。每一路都可以独立控制，先批量喂满缓存，再用单颗拨轮补齐零头，实现速度与精度的平衡。

---

## 3. 视觉与控制：OpenCV标定+钢针取放
- **视觉标定**：通过拼豆盘上的标记点，用OpenCV进行坐标校正，解决了机械运动的累积误差问题，保证了豆子摆放的精度。
- **摄像头**：作为“眼睛”，不仅可以用于标定，还可以实时监控拼豆状态，检测漏放、错放，实现闭环控制。
- **钢针逻辑**：钢针从缓存管中“挑”起单颗豆子，精准放到拼豆盘的对应位置。这个动作简单可靠，比复杂的气动系统更适合DIY场景。

---

## 4. 项目优势与迭代方向
### 优势
- **成本极低**：大量复用成熟开源硬件，核心结构3D打印即可，BOM成本可控。
- **技术栈清晰**：运动控制（GRBL/Marlin）+ 机器视觉（OpenCV）+ 定量供料（步进电机+拨轮），都是成熟且文档丰富的技术。
- **可扩展性强**：8路供料可以扩展到16路甚至更多，钢针上料头也可以升级为多针并行，进一步提升速度。

### 迭代方向
- **供料精度**：在振动滑道末端加入单颗拨轮结构，彻底解决“连豆”问题，保证每一次取豆都精准可控。
- **视觉闭环**：利用摄像头实时检测拼豆状态，一旦发现错误，自动回退修正，实现无人值守。
- **软件流程**：打通“图片/视频分析 → 点阵生成 → G-code输出 → 机器执行”的全流程，让用户只需要导入图片，就能一键生成拼豆作品。

---

## 一句话总结
你的这套设计，是一个**基于成熟XY平台、8路振动供料、钢针取放、视觉校正的全自动拼豆机**。它巧妙地复用了现有技术，结构简单可靠，成本可控，是一个极具可行性和扩展性的DIY项目。

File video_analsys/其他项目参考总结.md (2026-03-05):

你的初始设计思路非常清晰，巧妙复用了成熟的XY平台，结合振动供料和视觉标定，形成了一个低成本、高可行性的方案。下面我从专业角度进行评价，并结合之前各项目的经验教训，给出具体的设计建议和迭代方向。

- **平台复用成熟**：选用开源写字机/雕刻机的XY框架（如GRBL固件），大幅降低运动控制和机械设计的复杂度，这是快速验证项目的明智选择。
- **取料机构极简**：钢针取豆替代复杂的气动或夹爪，结构简单、成本极低，且对小颗粒（2.6mm）适应性好。
- **视觉闭环**：引入OpenCV标定，补偿机械误差，为高精度摆放提供保障，也为后续实时检测漏放、错放奠定基础。
- **供料思路正确**：8路独立振动道，满足多色需求，且振动供料已在多个项目中验证了可行性。
- **供料精度**：振动虽能排列豆子，但“连豆”（多颗同时滑出）、“卡豆”风险较高，影响单颗取料的可靠性。
- **取料一致性**：钢针挑取依赖豆子到达固定位置，若末端无定量控制，每次取豆状态可能不一致，导致漏放或错位。
- **视觉实时性**：若仅用于初始标定，生产过程中无法动态纠正误差；若用于实时检测，需考虑计算延迟与运动控制的配合。
- **色号扩展**：8路供料对于复杂图案（如《星夜》需30+色）不够，但可作为原型验证。后续需考虑模块化扩展。
- **后处理**：热熔定型方案，使用目前成熟的拼豆热熔方案
- **批量缓存**：机头有16颗豆子的1级缓存
- **单颗精补**：在缓存仓出口加装拨轮或旋转挡片（参考V2的1/4/7/10/13切换机构），实现单颗精确分离，补足零头。
- **传感器闭环**：在滑道末端和取料位分别安装光检（参考双光检设计），检测豆子到位情况，避免空取或多取。
- **2级缓存补料塔**： 处理静电和卡住问题，需要震动马达或者电磁铁，保证通畅；这样既保留了振动供料的连续补给能力，又解决了取料精度问题。
- **钢针形状**：可将钢针末端磨成微凹或带倒钩，或者特别的结构。便于稳定挑起单颗豆子，同时避免刺伤豆子。
- **落料辅助**：若钢针挑取后需移动到模板上方再释放，可能因静电或粘连导致豆子不掉落。可考虑在针座上加装微型电磁铁或轻微振动机构，强制落料。### 9g电机强制脱离
- **多针并行**：### 这里不用多针并行，项目速度瓶颈是算法+电机+机头重量
- **双重用途**：
  1. **生产前标定**：利用拼豆盘上的标记点进行坐标映射，消除机械误差（你已实现）。
  2. **生产中检测**：每放完一行或一色后，摄像头拍照，与理想点阵对比，快速发现漏放、错位、多余豆子，并触发补放或报警（参考多通道分拣项目的传感器反馈）。
- **算法简化**：由于拼豆颜色固定，可采用颜色阈值分割快速识别，无需复杂深度学习，降低计算负载。
- **分色打印策略**：采用逐色打印，避免频繁切换供料通道带来的机械磨损。软件根据点阵图按颜色分组，生成G代码时先执行颜色A的所有点位，再切换到颜色B。
- **物料管理**：软件根据图案统计各色豆子需求，在开始前检查料盒余量（可通过传感器或手动输入），避免中途缺料（参考V2的智能物料提示）。
- **热熔定型**：建议借鉴Delta构型拼豆机的“加热床直接定型”方案，将打印平台本身做成可加热的（如铝板+硅胶加热片），打印完成后直接在平台上热熔，省去转移步骤。
- **供料单元模块化**：每个料盒+振动滑道+定量机构做成独立模块，可快速插拔，便于维护和扩展色号（最多可扩充到16路、24路，256路）。
- **控制架构**：采用分布式控制，主控（如树莓派）负责图像处理和任务调度，下位机（Arduino/STM32）负责运动控制和传感器读取，通过串口通信，便于分工调试（参考大规模多通道系统的设计）。
- **供料优化**：买到拼豆笔后发现，供料使用特殊结构和卡簧震动原则，放到统一通道，下料直接使用管道模式，不是钢针。豆子直接在豆盘固定。管道模式也要有按压装置才能黏在sheet上，单重力不可能黏住
可以机头做双孔位，空心下料，实心压柱

设计抓住了低成本、快速验证的核心，基础架构非常扎实。后续只需在供料精度、取料一致性、视觉深度应用和工艺闭环上加以优化，完全有望发展为一个优秀的开源项目甚至商业化产品。建议参考上述建议，分阶段迭代，每个阶段明确目标和测试标准，逐步攻克关键技术点。祝项目顺利！

分三个阶段推进：
### **V1：原型验证**
- 目标：实现单色简单图案打印，验证机械运动、视觉标定、钢针取放的可行性。
- 工作：
  - 搭建XY平台，安装单路振动供料和钢针取料机构。
  - 实现OpenCV标定，完成坐标映射。
  - 编写简单G代码，手动输入点阵，测试取放精度。
- 交付：能打印出3×3的简单图案，验证核心原理。

### **V2：多色供料与效率优化**
- 目标：完成8色4路供料，实现“16+1”定量取豆逻辑，提升速度和可靠性。
- 工作：
  - 设计模块化料盒+振动异常处理，末端加入批量缓存和单颗拨轮。
  - 安装光检传感器，实现双光检闭环。
  - 软件整合分色打印策略，自动生成逐色G代码。
  - 测试多色复杂图案（如马里奥蘑菇），记录效率与故障率。
- 交付：稳定打印8色、18*18豆子的图案，单颗取料成功率>99%。（单颗失效<4次/图，失效不影响整体）

### **V3：成品级系统**
- 目标：完善后处理、视觉检测、人机交互，达到接近商业化的水平。
- 工作：
  - 增加生产实时视觉检测功能，自动补漏。
  - 开发用户友好的上位机软件，支持图片输入→自动生成点阵→一键打印。
  - 扩展供料到16色8路，并优化控制算法，提升速度。
- 交付：能连续完成《星夜》级别（5000+豆子）的复杂图案，具备商业化潜力。
    A4平台，小豆，支持70*100；A4平台，大豆，32*48；
    全图成功率>99%;单图人类参与度=0次
    料仓16色，单色8路存储，50cm高总计24000颗豆子；小图60次，中图25次，大图3张

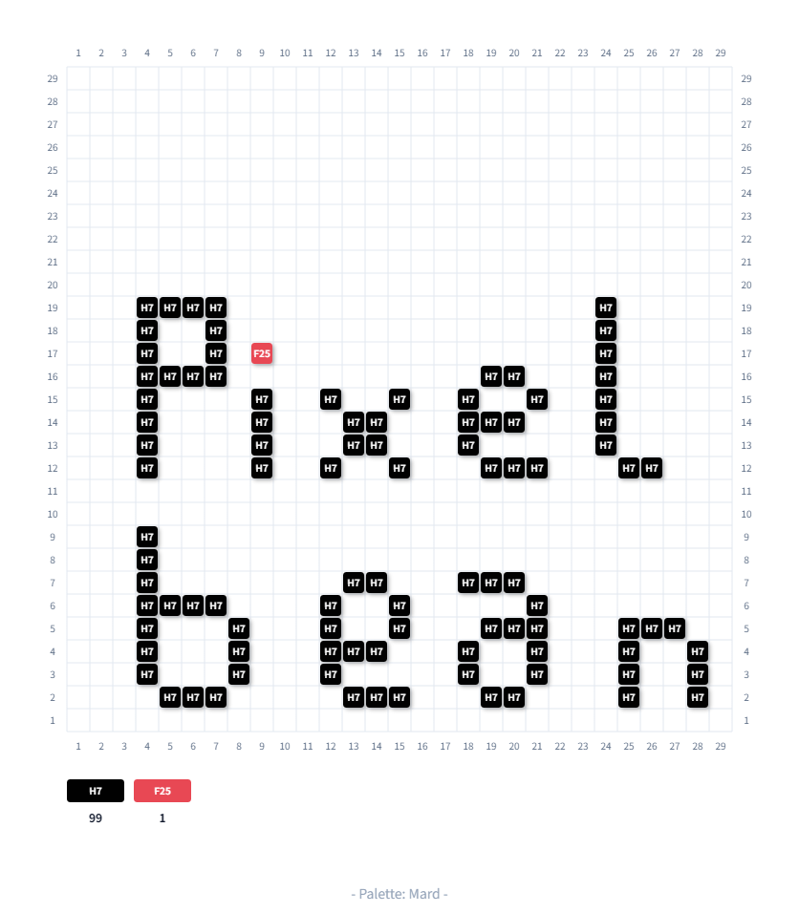
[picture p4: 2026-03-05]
pattern-mard-1772694074596.png

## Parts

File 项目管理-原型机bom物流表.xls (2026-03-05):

类别 | 物料名称 | 规格参数 | 数量 | 参考单价 | 参考总价 | 实付价格 | 采购推荐链接 | 下单时间 | 实际到货时间
调研咨询 | 咸鱼咨询 | 20元机械方案 | 2 | 20 | 40 | 40 | 咸鱼卖家 | 2026-02-22 18:00 | 2026-02-22 22:00
调研咨询 | 微信咨询 | 20元咨询 | 1 | 20 | 20 | 20 | 咸鱼到微信 | 2026-02-22 18:00 | 2026-02-22 21:00
调研咨询 | 拼豆套装 | 10色拼豆套装 | 1 | 11 | 18 | 18 | 美团2小时，晨光文具店 | 2026-02-23 08:42 | 2026-02-23 09:27
调研咨询 | 拼豆笔 | 2400+豆子拼豆笔套装 | 1 | 32 | 32 | 32 | 美团2小时，晨光文具店 | 2026-02-23 08:42 | 2026-02-23 09:27
导轨 | 轴承钢MGN12导轨-100MM | 270mm长 | 10 | 4.73 | 0 | 47.3 | https://item.taobao.com/item.htm?id=1002234653079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 | 2026年2月23日18点51分 | 2026年2月28日10点12分
导轨 | 轴承钢MGN12H 加长块 |  | 1 | 9.46 | 0 | 9.46 | https://item.taobao.com/item.htm?id=1002234653079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 | 2026年2月23日18点51分 | 2026年2月28日10点13分
导轨 | 轴承钢MGN12导轨-100MM | 350mm长 | 2 | 0 | 0 | 0 | https://item.taobao.com/item.htm?id=1002234653079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 | 2026年2月23日18点51分 | 2026年2月28日10点14分
导轨 | 轴承钢MGN12H 加长块 |  | 2 | 9.46 | 0 | 18.92 | https://item.taobao.com/item.htm?id=1002234653079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 | 2026年2月23日18点51分 | 2026年2月28日10点15分
导轨 | 轴承钢MGN9导轨-100MM | 55mm长 | 1 | 4.26 | 0 | 4.26 | https://item.taobao.com/item.htm?id=1002234653079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 | 2026年2月23日18点51分 | 2026年2月28日10点16分
导轨 | 轴承钢MGN9C 标准块 |  | 1 | 7.57 | 0 | 7.57 | https://item.taobao.com/item.htm?id=1002234653079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 | 2026年2月23日18点51分 | 2026年2月28日10点17分
电机 | 42步进电机 | 42电机/高38mm带1000mmXH2.54线 | 2 | 15.5 | 2 | 33 | https://item.taobao.com/item.htm?id=649664531631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 | 2026年2月23日18点51分 | 2026年2月28日10点18分
电机 | 42步进电机 固定片 | 3D打印机配件 42步进电机 固定片 安装支架 适用2020 2040铝型材 | 2 | 2.85 | 0 | 5.7 |  | 2026年2月23日18点51分 | 2026年2月28日10点19分
电机 | 隔离柱 | 内径5、外径10、高度9 | 4 | 0.71 | 0 | 2.84 | https://item.taobao.com/item.htm?id=608843333546&skuId=4447032678855 | 2026年2月23日18点51分 | 2026年2月28日10点20分
电机 | 同步轮 | 20齿、内孔5、带宽6 | 2 | 1.08 | 0 | 2.16 | https://item.taobao.com/item.htm?_u=7208d75pete159&id=571029008660&skuId=3695816317651 | 2026年2月23日18点51分 | 2026年2月28日10点21分
电机 | 惰轮 | 20齿、内孔5、带宽6（不带齿） | 10 | 2.33 | 0 | 23.3 | https://item.taobao.com/item.htm?_u=7208d75petf8e0&id=572126642416&skuId=3714008004302 | 2026年2月23日18点51分 | 2026年2月28日10点22分
 | 惰轮 | 20齿、内孔5、带宽6（带齿） | 2 | 1.83 | 0 | 3.66 |  | 2026年2月23日18点51分 | 2026年2月28日10点23分
电机 | 同步带 | GT2-6MM（橡胶）【5米/卷】 | 1 | 12.8 | 0 | 12.8 | https://item.taobao.com/item.htm?id=572171792144&skuId=4454393450696 | 2026年2月23日18点51分 | 2026年2月28日10点24分
电机 | 黄铜垫片 | M5*8*1.0【50个】 | 1 | 4.68 | 0 | 4.68 | https://item.taobao.com/item.htm?_u=k208d75pet711d&id=38249923295&skuId=4886145180894 | 2026年2月23日18点51分 | 2026年2月28日15点35分
电机 | A4988驱动板 |  | 2 | 7.48 | 0 | 14.96 |  | 2026年2月23日18点51分 | 2026年2月28日10点24分
电机 | A4988模块 |  | 1 | 10.56 | 0 | 10.56 |  | 2026年2月23日18点51分 | 2026年2月28日10点24分
舵机 | 舵机 | MG90S数字90-180 (1个) | 1 | 15.8 | 0 | 15.8 |  | 2026年2月23日18点51分 | 2026年2月28日10点24分
结构系统 | 同步带结构固定件 | 孔距20mm m5 两孔固定片 | 8 | 1 |  | 28 | 美团本地五金店-低消凑单 | 2026年2月28日10点26分 | 2026年2月28日12点26分
结构系统 | 热熔胶胶棒 | 11mm | 8 | 1 |  | 15 | 美团本地超市-低消凑单 | 2026年2月28日10点38分 | 2026年2月28日12点26分
结构系统 | 扎带 | 200mm长 | 2 | 3 |  | 0 | 美团本地超市-低消凑单 | 2026年2月28日10点38分 | 2026年2月28日12点26分
结构系统 | 欧标2020铝型材 | 338mm长（X方向） | 2 | 13.53 | 27.06 | 27.06 | https://item.jd.com/10194478167601.html | 2026年2月23日18点51分 | 2026年2月28日10点24分
结构系统 | 欧标2020铝型材 | 460mm长（Y方向） | 2 | 0 | 0 | 10 |  | 2026年2月23日18点51分 | 2026年2月28日10点25分
结构系统 | 欧标2020铝型材 | 300mm长 | 1 | 0 | 0 | 0 |  | 2026年2月23日18点51分 | 2026年2月28日10点26分
结构系统 | L字铝合金连接件 | 2020型-4孔 | 2 | ￥8.80 | 17.6 | 17.6 | https://item.jd.com/65618872668.html?pcdk=_ihOMufbYvG4rGv0K8s52-x2Jt8hcBMat61GIkFUjdE=.M8AW.sbc1 | 2026年2月23日18点51分 | 2026年2月28日10点26分
结构系统 | T型螺母 | 不锈钢20型M3=50个 | 1 | 3.51 | 3.51 | 3.51 | 拼多多 | 2026年2月23日18点51分 | 2026年2月28日10点26分
结构系统 | T型螺母 | 不锈钢20型M5=50个 | 1 | 3.7 | 3.7 | 3.7 | 拼多多 | 2026年2月23日18点51分 | 2026年2月28日10点26分
结构系统 | 3D打印零件 | 大鱼写字机x轴连接件4个 | 70 | 0.12 | 18 | 14.4 | 咸鱼北京朝阳打印 | 2026年2月28日10点26分 | 2026年3月2日19点36分
结构系统 | 3D打印零件 | 大鱼写字机笔架相关件4个 | 260 | 0.12 | 0 |  | 咸鱼北京朝阳打印 | 2026年2月28日18点05分 | 2026年3月2日19点36分
电控系统 | ardiuno | ardiuno nano v3 typeC | 1 | 12.5 | 12.5 | 12.5 | 拼多多 | 2026年2月23日18点51分 | 2026年2月28日10点25分
电控系统 | 电源适配器 | 12V6A电源送母线 | 1 | 16.1 | 16.1 | 16.1 | 拼多多 | 2026年2月23日18点51分 | 2026年2月28日10点25分
电控系统 | 12-5降压模块 | 固定5v输出模块1A | 1 | 3.52 | 3.52 | 3.52 | 这个东西没有必要买 | 2026年2月23日18点51分 | 2026年2月28日10点25分
电控系统 | 杜邦线 | 母对母，公对母，公对公 | 1 | 10 | 0 | 10 | 拼多多 | 2026年2月28日18点03分 | 2026年3月2日19点36分
电控系统 | 跳线帽 | 2.45mm 50个 | 1 | 5 | 0 | 5 | 拼多多 | 2026年2月28日18点03分 | 2026年3月2日19点36分
电控系统 | 舵机延长线 | 30cm | 1 | 3.8 | 0 | 3.8 | 拼多多 | 2026年2月28日18点10分
辅件耗材 | 内六角圆柱头螺丝 | M3×8 | 20 | 0 | 42.52 | 42.52 |  | 2026年2月23日18点51分 | 2026年2月28日10点25分
辅件耗材 | 内六角圆柱头螺丝 | M3×10 | 20 | 0 | 0 |  |  | 2026年2月23日18点51分 | 2026年2月28日10点28分
辅件耗材 | 内六角圆柱头螺丝 | M3×12 | 20 | 0 | 0 |  |  | 2026年2月23日18点51分 | 2026年2月28日10点29分
辅件耗材 | 内六角圆柱头螺丝 | M3×20 | 10 | 0 | 0 |  |  | 2026年2月23日18点51分 | 2026年2月28日10点30分
辅件耗材 | 内六角圆柱头螺丝 | M5×8 | 10 | 0 | 0 |  | 10个不够，需要再来10个 | 2026年2月23日18点51分 | 2026年2月28日10点31分
辅件耗材 | 内六角圆柱头螺丝 | M5×10 | 10 | 0 | 0 |  |  | 2026年2月23日18点51分 | 2026年2月28日10点32分
辅件耗材 | 内六角圆柱头螺丝 | M5×16 | 10 | 0 | 0 |  |  | 2026年2月23日18点51分 | 2026年2月28日10点33分
辅件耗材 | 内六角圆柱头螺丝 | M5×20 | 10 | 0 | 0 |  |  | 2026年2月23日18点51分 | 2026年2月28日10点34分
辅件耗材 | 内六角圆柱头螺丝 | M5×30 | 10 | 0 | 0 |  |  | 2026年2月23日18点51分 | 2026年2月28日10点35分
辅件耗材 | 六角防松螺母 | M5 | 20 | 2.55 | 2.55 | 2.55 |  | 2026年2月23日18点51分 | 2026年2月28日10点38分
工具配件 | 公制内六角扳手 | L型内六角扳手 一套 | 1 | 13.6 | 13.6 | 13.6 |  | 2026年2月23日18点51分 | 2026年2月28日10点39分
拼豆工具 | 52钉拼豆板 | 升级加厚长豆针 | 1 | 11.5 |  | 11.5 | 拼多多 | 2026年3月3日18点38分
磁吸机头 | 磁吸连接器 | 3pin 公母座一套 | 4 | 0 | 0 | 24.95 | 拼多多 | 2026年3月3日18点38分
磁吸机头 | 拼豆笔 | 45度倾斜 | 3 |  |  | 16.99 | 拼多多 | 2026年3月3日18点38分
磁吸机头 | 磁铁 | 8mm*2.6mm 圆形 | 50 |  |  | 10.3 | 拼多多 | 2026年3月3日18点38分
磁吸机头 | 舵机 | MG90S 180度 | 5 |  |  | 33 | 拼多多 | 2026年3月3日18点38分

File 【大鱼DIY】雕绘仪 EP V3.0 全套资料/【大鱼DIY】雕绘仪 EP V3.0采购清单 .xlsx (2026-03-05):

【大鱼DIY】雕绘仪EP V3.0采购清单
郑重声明 |  | 个别奸商篡改清单内容发到其他渠道，高价出售零部件的行为当真缺德，一经发现必定曝光！
视频教程 |  | https://www.bilibili.com/video/BV1cK411X7aa/
行程范围：220mm×300mm，以下所有东西均可在淘宝找同规格产品，自己选择。
序号 | 名称 | 规格 | 数量 | 单价 | 运费 | 总价 | 链接 | 备注
1 | 线轨 报我名字打9折（153元） 可找卖家免费做防锈 | MGN12滑轨270mm长+ 12H滑块 | 1 | 45 | 0 | 40.5 | https://item.taobao.com/item.htm?id=538777574566&spm=2015.23436601.0.0&qq-pf-to=pcqq.c2c
 |  | MGN12滑轨350mm长+ 12H滑块 | 2 | 53 | 0 | 95.4
 |  | MGN9滑轨55mm长+9C滑块 | 1 | 20 | 0 | 18
2 | 欧标2020 铝型材 | 338mm长 X方向 | 2 | 4.7 | 12 | 21.4 | https://item.taobao.com/item.htm?spm=a1z1r.7974869.0.0.269c3ad4cUHl1e&id=610844048816
3 |  | 460mm长 Y方向 | 2 | 6 | 0 | 12
 | 欧标1020铝型材 | 300mm长 | 1 | 4.5 | 0 | 4.5 | https://item.taobao.com/item.htm?spm=a1z10.3-c-s.w4002-23166866487.9.253e27b9VWtYBR&id=628103627886
10 | T型螺母 | 20型材M3 建议多买几个备用 | 15 | 0.12 | 0 | 1.8 | https://item.taobao.com/item.htm?spm=a1z10.5-c-s.w4002-24186553506.11.23c31a24d9cvuw&id=15146235453 | 仅线轨和控制盒使用，每根线轨3~4个即可，也可多装两个
11 |  | 20型材M5 建议多买几个备用 | 22 | 0.098 | 0 | 2.156 |  | 其他与铝型材连接的地方均用此规格
12 | 一字铝合金连接件 | 2020型-2孔 | 4 | 1.2 | 0 | 4.8 | https://item.taobao.com/item.htm?spm=a1z09.2.0.0.bbac2e8dMJDKzb&id=533716881777&_u=o208d75pet0fce
13 | 步进电机 | 叫卖家 换XH2.54配线 | 3 | 16 | 5 | 53 | https://item.taobao.com/item.htm?spm=a1z10.5-c-s.w4002-21750521464.11.20bd7ca6qJRAo5&id=583578061112 | X、Y、Z各一个
15 | 同步轮 | 20齿内孔5带宽6 | 2 | 1.18 | 0 | 2.36 | https://item.taobao.com/item.htm?spm=a1z09.2.0.0.4b242e8db8Qx42&id=571029008660&_u=7208d75pete159
16 | 惰轮 | 20齿内孔5带宽6 带齿 | 2 | 1.9 | 0 | 3.8 | https://item.taobao.com/item.htm?spm=a1z09.2.0.0.4b242e8db8Qx42&id=572126642416&_u=7208d75petf8e0
17 | 轴承 | F695ZZ | 20 | 1.05 | 0 | 21 | https://item.taobao.com/item.htm?spm=a1z09.2.0.0.de352e8djNjmkk&id=650278182280&_u=k208d75pet1309
18 | 同步带 | GT2-6mm 5米/卷 | 1 | 14.62 | 0 | 14.62 | https://item.taobao.com/item.htm?spm=a1z10.3-c-s.w4002-21750521459.18.487f70afZvFDvG&id=572171792144
 | 四氟管 | 2*4白色 | 1 | 2 | 0 | 2 | https://item.taobao.com/item.htm?spm=a1z10.3-c-s.w4002-21750521459.12.63c470afNssdnO&id=571882929438
25 | 气动接头 | PC4-M6直通 | 2 | 1.2 | 0 | 2.4 | https://item.taobao.com/item.htm?spm=a1z10.5-c-s.w4002-21750521464.11.d30b5a06U6bjfL&id=587701799288
 | 电机支架 |  | 1 | 2.2 | 0 | 2.2 | https://item.taobao.com/item.htm?spm=a1z10.3-c-s.w4002-21750521459.15.79ee70af36oROH&id=594071400687
 | 隔离柱 | 内径5外径10高度9 | 4 | 0.6 | 0 | 2.4 | https://item.taobao.com/item.htm?spm=a1z10.3-c-s.w4002-21750521459.9.7ea170af8p6ygO&id=608843333546
33 | 橡胶脚垫 | 20*20*22 | 4 | 0.38 | 3 | 4.52 | https://detail.tmall.com/item.htm?id=627006937881&spm=a1z09.2.0.0.183b2e8dy1SAgH&_u=f208d75petaf6c
 | 黄铜垫片 | 5*8*1 | 24 | 0.1 | 0 | 2.4 | https://item.taobao.com/item.htm?spm=a1z09.2.0.0.de352e8djNjmkk&id=38249923295&_u=k208d75pet711d
 | 弹簧 | 0.3×4×20 | 1 | 0.5 | 0 | 0.5 | https://detail.tmall.com/item.htm?_u=k208d75pet6b16&id=575363698316&spm=a1z09.2.0.0.de352e8dF2PwEX
 | 钢丝（蘑菇头） | 公路刹车（基础款） | 1 | 12.9 | 0 | 12.9 | https://detail.tmall.com/item.htm?_u=k208d75pet26f2&id=591067070623&skuId=4053931316266
 | 紧定螺钉 | M8×6 | 1 | 0.13 | 0 | 0.13 | https://detail.tmall.com/item.htm?_u=k208d75pet437f&id=638821678552&spm=a1z09.2.0.0.de352e8dF2PwEX
37 | 内六角沉头螺钉 | M3×8 | 4 | 0.05 | 0 | 0.2 | https://detail.tmall.com/item.htm?id=617471305504&rn=0ebab8e607dd6ac198b7a54f02991a2e&abbucket=10
40 | 内六角平圆头螺钉 | M3×6 | 15 | 0.045 | 0 | 0.675 | https://detail.tmall.com/item.htm?id=636577427255&rn=3721f09883d14d99b1ded4f07e1a1ee0&abbucket=10
 |  | M3×8 | 22 | 0.045 | 0 | 0.99
 |  | M3×10 | 8 | 0.05 | 0 | 0.4
41 |  | M3×12 | 2 | 0.06 | 0 | 0.12
42 |  | M3×20 | 4 | 0.068 | 0 | 0.272
45 |  | M5×8 | 10 | 0.09 | 0 | 0.9 |  | 固定步进电机支架和一字连接板
46 |  | M5×10 | 10 | 0.1 | 0 | 1
47 |  | M5×16 | 4 | 0.12 | 0 | 0.48 |  | 安装脚垫
 |  | M5×20 | 3 | 0.2 | 0 | 0.6
49 |  | M5×30 | 6 | 0.2 | 0 | 1.2 | https://detail.tmall.com/item.htm?id=636577427255&rn=3721f09883d14d99b1ded4f07e1a1ee0&abbucket=10
 | 方形螺母 | M3 | 9 | 0.1 | 0 | 0.9 | https://detail.tmall.com/item.htm?id=542282923317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
 | 手拧螺钉 | M3×16 | 1 | 1.5 | 0 | 1.5 | https://detail.tmall.com/item.htm?_u=k208d75pet9038&id=659161030551&spm=a1z09.2.0.0.de352e8dF2PwEX
50 | 六角放松螺母 | M5 | 6 | 0.03 | 0 | 0.18 | https://detail.tmall.com/item.htm?_u=k208d75pet4f3a&id=534828257082&spm=a1z09.2.0.0.de352e8djNjmkk
 | 3D打印零件 | 总计约120g 市场价2~3毛/克 | 120 | 0.3 | 10 | 46 | 尽量群里找人打，也可以找我打（如果有时间的话）。
57 | 控制板 | 1个WIFI三驱动主板 | 1 | 90 | 10 | 100 | https://item.taobao.com/item.htm?ft=t&id=688418653094&qq-pf-to=pcqq.c2c
59 | 电源适配器 | 12V10A | 1 | 23 | 0 | 23 | https://item.taobao.com/item.htm?spm=a1z09.2.0.0.de352e8djNjmkk&id=585184846685&_u=k208d75peta1cb
 |  |  |  |  | 合计: | 503.203 | 如有遗漏或错误，麻烦您联系我更正，谢谢！ QQ：88910246

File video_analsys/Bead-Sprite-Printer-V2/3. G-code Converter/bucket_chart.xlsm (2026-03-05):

Index | Color Index | Color Name | count | count |  |  |  |  |  |  |  |  |  |  |  |  |  | SAMPLE PIXEL
1 | 57 | Cheddar | 1000 |  | index | P# | # | name | Count | R | G | B | RGB | HEX | Column1 | CLOSE1 | CLOSE2 | 181 | 127 | 69
2 | 18 | Black | 8000 |  | 86 | P85 | 85 | Gold | 1400 | 181 | 127 | 69 | 181,127,69 | B57F45 | PERLER | 0 | 0
3 | 92 | Dark Gray | 4000 |  | 21 | P21 | 21 | Light Brown | 1100 | 157 | 113 | 82 | 164,123,71 | 9D7153 | PERLER | 30.6757233 | 52.06748926
4 | 207 | Charcoal | 2500 |  | 87 | P301 | 301 | Copper | 0 | 151 | 99 | 78 | 151,99,78 | 97634E | PERLER | 42.01190308 | 75.56291356
5 | 17 | Gray | 1000 |  | 32 | P90 | 90 | Butterscotch | 5000 | 225 | 154 | 82 | 225,154,82 | E19A52 | PERLER | 53.23532662 | 93.24974866
6 | 81 | Light Gray | 8000 |  | 17 | P20 | 20 | Rust | 700 | 160 | 78 | 63 | 160,78,63 | A04E3F | PERLER | 53.64699432 | 104.2285743
7 | 1 | White | 8000 |  | 102 | P?? |  | Yellow Glitter |  | 186 | 180 | 86 | 186,180,86 | BAB456 | PERLER | 55.88380803 | 109.3738393
8 | 20 | Rust | 700 |  | 129 |  | 212 | Spice | 2800 | 227 | 92 | 68 | 227, 92, 68 | E35C44 | PERLER | 57.81003373 | 104.0210879
9 | 21 | Light Brown | 1100 |  | 122 |  | 219 | Fern | 2000 | 123 | 151 | 48 | 123, 151, 48 | 7B9730 | PERLER | 66.18912297 | 109.9491182
10 | 85 | Gold | 1400 |  | 123 |  | 402 | Olive | 0 | 114 | 118 | 62 | 115, 117, 62 | 72763E | PERLER | 67.96322535 | 109.5765108
11 | 96 | Cranapple | 4500 |  | 45 | P05 | 5 | Red | 3000 | 196 | 58 | 68 | 196,58,68 | C43A44 | PERLER | 70.61869441 | 140.2210169
12 | 5 | Red | 3000 |  | 31 | P04 | 4 | Orange | 3000 | 255 | 128 | 62 | 255,128,62 | FF803E | PERLER | 74.33707016 | 125.3963248
13 | 212 | Spice | 2800 |  | 46 | P961 | 961 | Cherry | 100 | 173 | 51 | 69 | 173,51,69 | AD3345 | PERLER | 76.4198927 | 152.5655597
14 | 4 | Orange | 3000 |  | 47 | P88 | 88 | Raspberry | 900 | 173 | 60 | 108 | 173,60,108 | AD3C6C | PERLER | 77.93587107 | 147.0839206
15 | 90 | Butterscotch | 5000 |  | 19 | P96 | 96 | Cranapple | 4500 | 136 | 64 | 79 | 136,64,79 | 88404F | PERLER | 78.06407625 | 146.3470365
16 | 12 | Brown | 500 |  | 99 | P?? |  | Red Glitter |  | 157 | 56 | 46 | 157,56,46 | 9D382E | PERLER | 78.39642849 | 151.4330246
17 | 3 | Yellow | 3000 |  | 82 | P48 | 48 | Neon Orange | 0 | 255 | 141 | 46 | 255,141,46 | FF8D2E | PERLER | 78.74642849 | 132.4145509
18 | 2 | Cream | 1000 |  | 130 |  | 409 | Tomato | 0 | 234 | 66 | 65 | 234, 66, 66 | EA4241 | PERLER | 80.90735442 | 151.0423613
19 | 97 | Prickly Pear | 1000 |  | 34 | P59 | 59 | Hot Coral | 500 | 255 | 97 | 88 | 255,97,88 | FF6158 | PERLER | 82.07923002 | 141.3836342
20 | 53 | Pastel Green | 1000 |  | 119 | P?? |  | Glow Orange |  | 234 | 175 | 111 | 234175111 | EAAF6F | PERLER | 82.92767934 | 144.7968607
21 | 219 | Fern | 2000 |  | 107 | P?? |  | Pink Glitter |  | 226 | 88 | 127 | 226,88,127 | E2587F | PERLER | 83.12640976 | 138.377957
22 | 10 | Dark Green | 700 |  | 16 | P35 | 35 | Tan | 200 | 207 | 168 | 137 | 207168137 | CFA889 | PERLER | 83.55237878 | 137.6157467
23 | 179 | Evergreen | 3000 |  | 128 |  | 210 | Orchid | 1000 | 181 | 108 | 153 | 181,108, 153 | B56C99 | PERLER | 86.12200648 | 132.6485017
24 | 201 | Midnight | 3000 |  | 23 | P12 | 12 | Brown | 500 | 108 | 82 | 77 | 108,82,77 | 6C524D | PERLER | 86.127812 | 148.059433
25 | 8 | Dark Blue | 4000 |  | 85 | P105 | 105 | Silver | 600 | 119 | 123 | 129 | 129137142 | 777B81 | PERLER | 86.37129153 | 136.6781118
26 | 200 | Cobalt | 2000 |  | 93 | P103 | 103 | Pearl Yellow | 0 | 209 | 198 | 110 | 209198110 | D1C66E | PERLER | 86.63717447 | 161.5090458
27 | 9 | Light Blue | 5000 |  | 15 | P205 | 205 | Fawn | 300 | 215 | 176 | 135 | 215176135 | D7B087 | PERLER | 88.95504483 | 149.9732789
28 | 52 | Pastel Blue | 2000 |  | 127 |  | 406 | Apricot | 0 | 255 | 169 | 103 | 255, 169, 103 | FFA967 | PERLER | 91.62968951 | 158.5882542
29 | 11 | Light Green | 1200 |  | 76 | P97 | 97 | Prickly Pear | 1000 | 203 | 215 | 53 | 203,215,53 | CBD735 | PERLER | 92.10863152 | 181.3339461
30 | 202 | Robin's Egg | 2800 |  | 29 | P57 | 57 | Cheddar | 1000 | 255 | 182 | 78 | 255,182,78 | FFB64E | PERLER | 92.63908462 | 166.9995907
31 | 82 | Light Lavender | 1000 |  | 35 | P203 | 203 | Salmon | 1000 | 255 | 119 | 127 | 255119127 | FF777F | PERLER | 94.3610089 | 151.9386698
32 | 56 | Pastel Yellow | 500 |  | 92 | P100 | 100 | Pearl Coral | 0 | 233 | 149 | 145 | 233149145 | E99591 | PERLER | 94.67840303 | 148.8806149
33 | 98 | Sand | 300 |  | 7 | P207 | 207 | Charcoal | 2500 | 95 | 95 | 95 | 84, 95, 95 | 545F5F | PERLER | 95.37295214 | 156.6392651
34 | 83 | Pink | 900 |  | 4 | P17 | 17 | Gray | 1000 | 150 | 152 | 156 | 150, 152, 156 | 96989C | PERLER | 95.6817642 | 151.0876065
35 | 38 | Magenta | 1200 |  | 91 | P104 | 104 | Pearl Light Pink | 0 | 204 | 164 | 155 | 204164155 | CCA49B | PERLER | 96.40539404 | 153.3931135
36 |  |  |  |  | 43 | P38 | 38 | Magenta | 1200 | 243 | 70 | 118 | 243,70,118 | F34676 | PERLER | 97.43715924 | 170.5069074
37 |  |  |  |  | 41 | P06 | 6 | Bubble Gum | 800 | 225 | 109 | 157 | 225109157 | E16D9D | PERLER | 100.019998 | 154.1563735
38 |  |  |  |  | 109 | P?? |  | Kiwi Glitter |  | 85 | 158 | 69 | 85,158,69 | 559E45 | PERLER | 100.8811182 | 164.5113978
39 |  |  |  |  | 42 | P83 | 83 | Pink | 900 | 230 | 87 | 148 | 230,87,148 | E65794 | PERLER | 101.2027668 | 163.7623922
40 |  |  |  |  | 81 | P50 | 50 | Neon Pink | 0 | 241 | 82 | 137 | 241,82,137 | F15289 | PERLER | 101.2373449 | 168.255572
41 |  |  |  |  | 5 | P206 | 206 | Pewter | 400 | 147 | 161 | 159 | 147, 161, 159 | 93A19F | PERLER | 102.0392082 | 163.572184
42 |  |  |  |  | 108 | P?? |  | Fairy Dust |  | 155 | 175 | 158 | 155175158 | 9BAF9E | PERLER | 104.4078541 | 171.8881245
43 |  |  |  |  | 94 | p102 | 102 | Pearl Green | 900 | 132 | 176 | 149 | 132176149 | 84B095 | PERLER | 105.8395011 | 176.4548068
44 |  |  |  |  | 48 | P60 | 60 | Plum | 700 | 178 | 95 | 170 | 178,95,170 | B25FAA | PERLER | 105.9905656 | 165.9241049
45 |  |  |  |  | 36 | P63 | 63 | Blush | 700 | 255 | 158 | 141 | 255158141 | FF9E8D | PERLER | 107.8007421 | 174.8611056
46 |  |  |  |  | 80 | P47 | 47 | Neon Yellow | 0 | 189 | 210 | 0 | 189,210,0 | BDD200 | PERLER | 108.2312339 | 196.3519441
 |  |  |  |  | 118 | P?? |  | Glow Purple |  | 174 | 102 | 177 | 174102177 | AE66B1 | PERLER | 111.0765502 | 171.7296374
 |  |  |  |  | 115 | P75 | 997.00 | Glow Green | 1000 | 175 | 195 | 157 | 175195157 | AFC39D | PERLER | 111.3732463 | 190.8147826
 |  |  |  |  | 8 | P92 | 92 | Dark Gray | 4000 | 80 | 80 | 80 | 86, 87, 92 | 56575C | PERLER | 111.9419492 | 186.3839179
 |  |  |  |  | 28 | P03 | 3 | Yellow | 3000 | 249 | 215 | 55 | 249,215,55 | F9D737 | PERLER | 112.0892502 | 211.021474
 |  |  |  |  | 71 | P61 | 61 | Kiwi Lime | 600 | 110 | 215 | 74 | 119,202,74 | 77CA4A | PERLER | 113.1812705 | 209.7231341
 | 1 |  |  |  | 52 | P07 | 7 | Purple | 600 | 111 | 84 | 147 | 111,84,147 | 6F5493 | PERLER | 113.2828319 | 186.4107947
 | 18 |  |  |  | 90 | P303 | 303 | Pearl Pink | 0 | 227 | 123 | 173 | 227, 123, 173 | e37bad | PERLER | 113.7892789 | 172.5367714
 | 92 |  |  |  | 117 | P?? |  | Glow Pink |  | 238 | 117 | 168 | 238117168 | EE75A8 | PERLER | 114.6734494 | 175.7863027
 | 207 |  |  |  | 111 | P?? |  | Clear |  | 158 | 167 | 174 | 158167174 | 9EA7AE | PERLER | 114.6908889 | 183.140475
 | 17 |  |  |  | 101 | P?? |  | Purple Glitter |  | 105 | 65 | 132 | 105,65,132 | 694184 | PERLER | 116.5718662 | 199.571729
 | 81 |  |  |  | 104 | P?? |  | Clear Glitter |  | 166 | 169 | 177 | 166169177 | A6A9B1 | PERLER | 116.8460526 | 186.2789145
 | 12 |  |  |  | 51 | P54 | 54 | Pastel Lavender | 2000 | 149 | 130 | 187 | 149130187 | 9582BB | PERLER | 122.2988144 | 188.38035
 | 20 |  |  |  | 77 | P179 | 179 | Evergreen | 3000 | 60 | 97 | 79 | 60,97,79 | 3C614F | PERLER | 125.0639836 | 200.0652481
 | 21 |  |  |  | 13 | P98 | 98 | Sand | 300 | 234 | 196 | 159 | 234196159 | EAC49F | PERLER | 125.1798706 | 211.2859576
 | 85 |  |  |  | 121 |  | 400 | Sherbert | 0 | 225 | 238 | 125 | 225, 238, 125 | E1EE7D | PERLER | 131.8825235 | 248.1938506
 | 96 |  |  |  | 72 | P80 | 80 | Bright Green | 700 | 70 | 200 | 80 | 84,177,96 | 54B160 | PERLER | 133.3079142 | 228.6949643
 | 5 |  |  |  | 70 | P53 | 53 | Pastel Green | 1000 | 115 | 213 | 148 | 115213148 | 73D594 | PERLER | 134.1379887 | 236.4420764
 | 212 |  |  |  | 95 | P101 | 101 | Pearl Light Blue | 0 | 130 | 185 | 179 | 130185179 | 7AAEA2 | PERLER | 134.4061011 | 221.6773195
 | 4 |  |  |  | 3 | P81 | 81 | Light Gray | 8000 | 190 | 195 | 191 | 190 195, 191 | BEC3BF | PERLER | 139.9607088 | 229.1843511
 | 90 |  |  |  | 55 | P70 | 70 | Periwinkle | 500 | 108 | 136 | 191 | 108136191 | 6C88BF | PERLER | 142.4570111 | 224.0145303
 | 57 |  |  |  | 124 |  | 403 | Mist | 0 | 156 | 185 | 199 | 156, 185, 199 | 9cb9c7 | PERLER | 144.5302736 | 233.7257549
 | 3 |  |  |  | 105 | P?? |  | Black Glitter |  | 56 | 55 | 55 | 56,55,55 | 383737 | PERLER | 144.9310181 | 244.3668837
 | 2 |  |  |  | 50 | P82 | 82 | Light Lavender | 1000 | 180 | 166 | 211 | 180166211 | B4A6D3 | PERLER | 147.2616719 | 228.6542021
 | 97 |  |  |  | 27 | P56 | 56 | Pastel Yellow | 500 | 250 | 238 | 141 | 250238141 | FAEE8D | PERLER | 149.2179614 | 271.9957167
 | 53 |  |  |  | 37 | P204 | 204 | Flamingo | 1000 | 255 | 181 | 190 | 255181190 | FFB5BE | PERLER | 151.7662677 | 242.2338504
 | 219 |  |  |  | 131 |  | 410 | Teal | 1000 | 54 | 141 | 151 | 54, 141, 151 | 368D97 | PERLER | 151.8189711 | 239.8009225
 | 10 |  |  |  | 38 | P33 | 33 | Peach | 1000 | 252 | 198 | 184 | 252198184 | FCC6B8 | PERLER | 152.6663028 | 250.8946103
 | 179 |  |  |  | 116 | P?? |  | Glow Blue |  | 86 | 172 | 190 | 86172190 | 56ACBE | PERLER | 160.2841227 | 259.0118768
 | 201 |  |  |  | 89 | P302 | 302 | Pearl | 0 | 216 | 214 | 199 | 216, 214, 199 | D8D6C7 | PERLER | 160.2934808 | 266.84403
 | 8 |  |  |  | 62 | P201 | 201 | Midnight | 3000 | 35 | 55 | 85 | 22,40,70 | 162846 | PERLER | 163.5726138 | 270.2215526
 | 200 |  |  |  | 74 | P10 | 10 | Dark Green | 700 | 16 | 131 | 85 | 16,131,85 | 108355 | PERLER | 165.8221939 | 256.2376712
 | 9 |  |  |  | 25 | P02 | 2 | Cream | 1000 | 237 | 231 | 186 | 237231186 | EDE7BA | PERLER | 166.255827 | 286.2411434
 | 52 |  |  |  | 54 | p93 | 93 | Blueberry Crème | 1000 | 135 | 167 | 225 | 135167225 | 87A7E1 | PERLER | 167.487313 | 264.2556173
 | 11 |  |  |  | 61 | P08 | 8 | Dark Blue | 4000 | 43 | 48 | 124 | 43,48,124 | 2B307C | PERLER | 168.2557577 | 281.2889904
 | 202 |  |  |  | 40 | P79 | 79 | Light Pink | 600 | 245 | 192 | 213 | 245192213 | F5C0D5 | PERLER | 170.4611393 | 270.8763556
 | 82 |  |  |  | 58 | P52 | 52 | Pastel Blue | 2000 | 99 | 169 | 214 | 99169214 | 63A9D6 | PERLER | 171.7934807 | 275.0927329
 | 54 |  |  |  | 64 | P58 | 58 | Toothpaste | 800 | 176 | 232 | 213 | 176232213 | B0E8D5 | PERLER | 178.2862866 | 303.0444384
 | 60 |  |  |  | 57 | P202 | 202 | Robin's Egg | 2800 | 175 | 220 | 225 | 180217223 | B4D9DF | PERLER | 181.7168127 | 301.1392431
 | 83 |  |  |  | 67 | P11 | 11 | Light Green | 1200 | 56 | 199 | 175 | 56199175 | 38C7AF | PERLER | 179.0111728 | 296.1110203
 | 38 |  |  |  | 106 | P?? |  | White Glitter |  | 208 | 219 | 222 | 208219222 | D0DBDE | PERLER | 180.5602393 | 297.0152761
 | 203 |  |  |  | 73 | P99 | 99 | Shamrock | 0 | 0 | 150 | 84 | 0, 150, 84 | 9654 | PERLER | 183.0710245 | 282.5139031
 | 204 |  |  |  | 9 | P18 | 18 | Black | 8000 | 30 | 30 | 30 | 52, 50, 52 | 252525 | PERLER | 183.660012 | 310.7486864
 | 79 |  |  |  | 103 | P?? |  | Green Glitter |  | 0 | 135 | 110 | 135110 | 00876E | PERLER | 185.757907 | 286.0099635
 |  |  |  |  | 79 | P49 | 49 | Neon Green | 0 | 0 | 172 | 74 | 0,172,74 | 00AC4A | PERLER | 186.5770618 | 292.0095715
 |  |  |  |  | 12 | P208 | 208 | Toasted Marshmallow | 700 | 241 | 229 | 216 | 241229216 | F1E5D8 | PERLER | 188.7140694 | 314.1898063
 |  |  |  |  | 83 | P300 | 300 | Neon Blue | 0 | 34 | 85 | 183 | 34,85,183 | 2255B7 | PERLER | 190.7065809 | 304.6769133
 |  |  |  |  | 113 | P?? |  | Transparent Turquoise |  | 0 | 109 | 139 | 0, 110, 141 | 006d8b | PERLER | 194.8974089 | 302.2385783
 |  |  |  |  | 68 | P91 | 91 | Parrot Green | 50 | 0 | 150 | 138 | 0, 150, 138 | 00968A | PERLER | 195.0666553 | 302.9865341
 |  |  |  |  | 59 | P09 | 9 | Light Blue | 5000 | 39 | 138 | 203 | 39138203 | 278ACB | PERLER | 195.5530619 | 309.125556
 |  |  |  |  | 112 | P310 | 310 | Clear Blue | 0 | 124 | 210 | 242 | 124210242 | 7CD2F2 | PERLER | 200.1674299 | 328.3758981
 |  |  |  |  | 125 |  | 404 | Sky | 0 | 84 | 205 | 227 | 84, 205, 227 | 54CDE3 | PERLER | 201.1392552 | 331.5080039
 |  |  |  |  | 60 | P200 | 200 | Cobalt | 2000 | 0 | 102 | 179 | 0, 102, 179 | 0066B3 | PERLER | 213.274471 | 334.0340113
 |  |  |  |  | 126 |  | 405 | Lagoon | 0 | 0 | 171 | 178 | 0, 171, 178 | 00ABB2 | PERLER | 215.8193689 | 340.9457378
 |  |  |  |  | 100 | P?? |  | Blue Glitter |  | 0 | 105 | 192 | 12104179 | 0069C0 | PERLER | 219.9409012 | 344.9914344
 |  |  |  |  | 1 | P01 | 1 | White | 8000 | 247 | 247 | 242 | 247, 247, 242 | F7F7F2 | PERLER | 220.6467765 | 366.8850776
 |  |  |  |  | 97 | P999 | 999 | RANDOM | 0 | 0 | 240 | 0 |  |  |  | 224.2565495 | 375.1810761
 |  |  |  |  | 65 | P62 | 62 | Turquoise | 700 | 0 | 143 | 204 | 0, 143, 204 | 008FCC | PERLER | 226.3669587 | 355.3709495
 |  |  |  |  | 11 |  |  |  |  | 0 | 0 | 0 |  |  |  | 231.6268551 | 392.6841477
 |  |  |  |  | 20 |  |  |  |  | 0 | 0 | 0 |  |  |  | 231.6268551 | 392.6841477
 |  |  |  |  | 24 |  |  |  |  | 0 | 0 | 0 |  |  |  | 231.6268551 | 392.6841477
 |  |  |  |  | 33 |  |  |  |  | 0 | 0 | 0 |  |  |  | 231.6268551 | 392.6841477
 |  |  |  |  | 39 |  |  |  |  | 0 | 0 | 0 |  |  |  | 231.6268551 | 392.6841477
 |  |  |  |  | 44 |  |  |  |  | 0 | 0 | 0 |  |  |  | 231.6268551 | 392.6841477
 |  |  |  |  | 49 |  |  |  |  | 0 | 0 | 0 |  |  |  | 231.6268551 | 392.6841477
 |  |  |  |  | 53 |  |  |  |  | 0 | 0 | 0 |  |  |  | 231.6268551 | 392.6841477
 |  |  |  |  | 56 |  |  |  |  | 0 | 0 | 0 |  |  |  | 231.6268551 | 392.6841477
 |  |  |  |  | 63 |  |  |  |  | 0 | 0 | 0 |  |  |  | 231.6268551 | 392.6841477
 |  |  |  |  | 66 |  |  |  |  | 0 | 0 | 0 |  |  |  | 231.6268551 | 392.6841477
 |  |  |  |  | 69 |  |  |  |  | 0 | 0 | 0 |  |  |  | 231.6268551 | 392.6841477
 |  |  |  |  | 75 |  |  |  |  | 0 | 0 | 0 |  |  |  | 231.6268551 | 392.6841477
 |  |  |  |  | 78 |  |  |  |  | 0 | 0 | 0 |  |  |  | 231.6268551 | 392.6841477
 |  |  |  |  | 84 |  |  |  |  | 0 | 0 | 0 |  |  |  | 231.6268551 | 392.6841477
 |  |  |  |  | 88 |  |  |  |  | 0 | 0 | 0 |  |  |  | 231.6268551 | 392.6841477
 |  |  |  |  | 98 |  |  |  |  | 0 | 0 | 0 |  |  |  | 231.6268551 | 392.6841477
 |  |  |  |  | 110 |  |  |  |  | 0 | 0 | 0 |  |  |  | 231.6268551 | 392.6841477
 |  |  |  |  | 114 |  |  |  |  | 0 | 0 | 0 |  |  |  | 231.6268551 | 392.6841477
 |  |  |  |  | 120 |  |  |  |  | 0 | 0 | 0 |  |  |  | 231.6268551 | 392.6841477
 |  |  |  |  | 96 | P998 | 998 | CLEAR | 4000 | 0 | 255 | 0 |  |  |  | 232.1766569 | 393.9807608
 |  |  |  |  | 2
 |  |  |  |  | 6
 |  |  |  |  | 10
 |  |  |  |  | 14
 |  |  |  |  | 18
 |  |  |  |  | 22
 |  |  |  |  | 26
 |  |  |  |  | 30

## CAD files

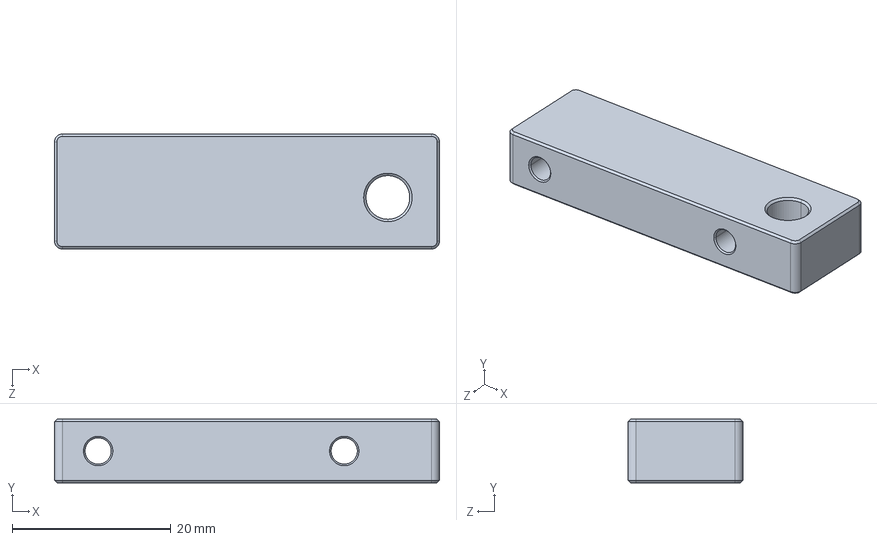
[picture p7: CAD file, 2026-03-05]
【大鱼DIY】雕绘仪 EP V3.0 全套资料/STP格式零件/长管夹.STEP
48.5 x 8.00 x 14.5 mm

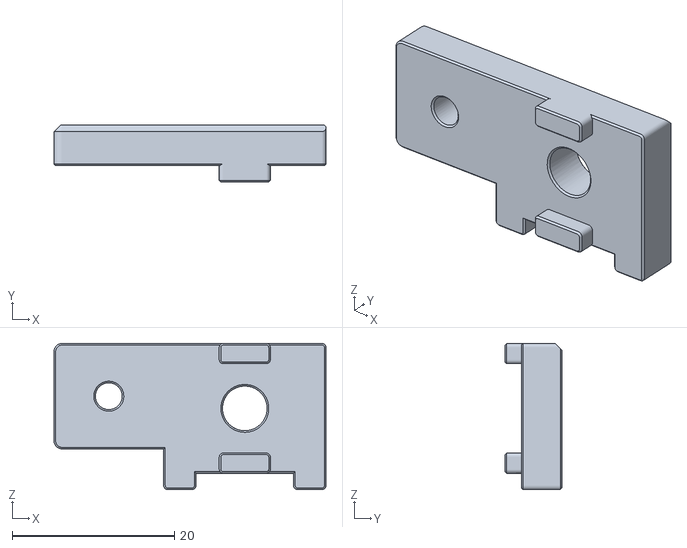
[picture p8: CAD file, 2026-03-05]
【大鱼DIY】雕绘仪 EP V3.0 全套资料/实际打印/X轴连接件_B.STL
33.5 x 7.00 x 18.0

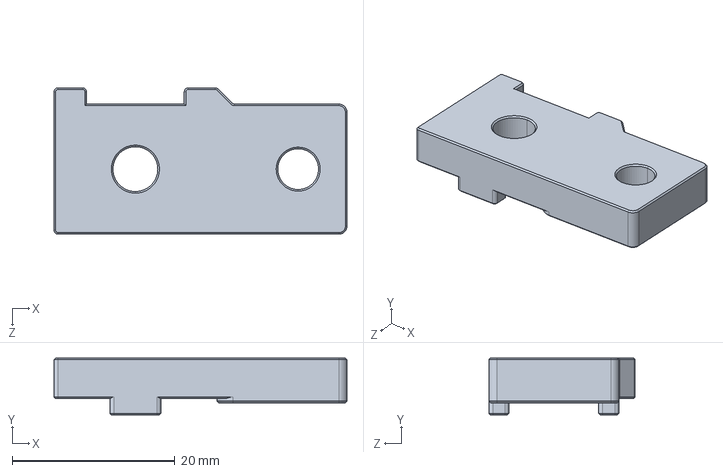
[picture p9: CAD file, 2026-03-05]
【大鱼DIY】雕绘仪 EP V3.0 全套资料/STP格式零件/B惰轮座.STEP
36.0 x 7.00 x 18.0 mm

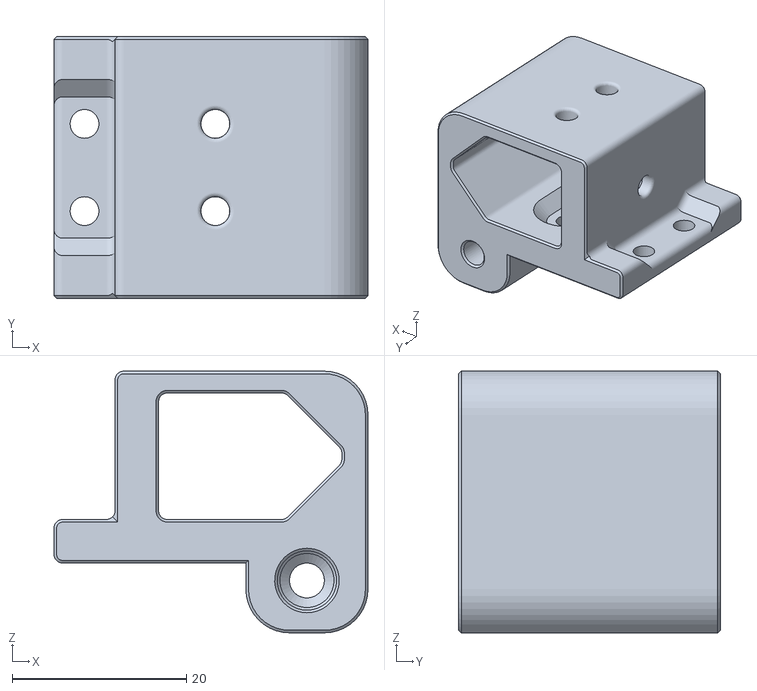
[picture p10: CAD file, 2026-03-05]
【大鱼DIY】雕绘仪 EP V3.0 全套资料/实际打印/笔架-笔架.STL
36.0 x 30.0 x 30.0

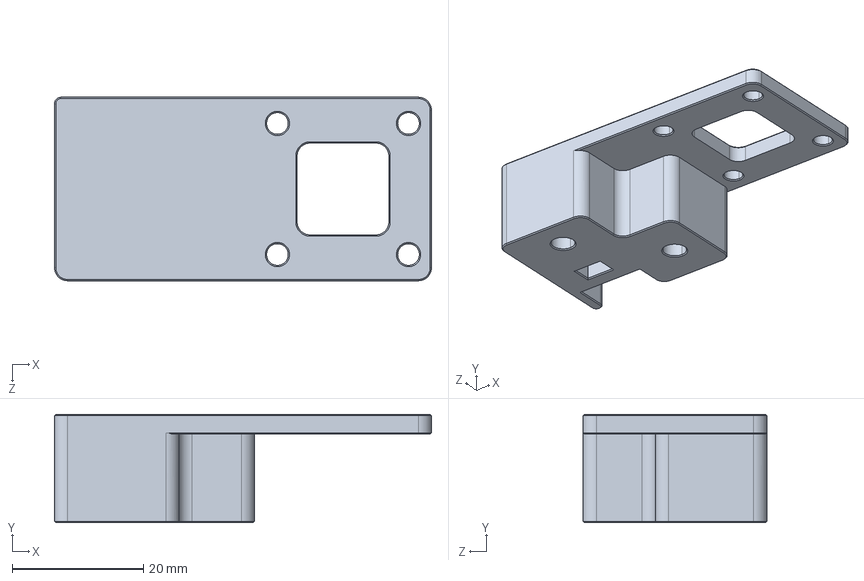
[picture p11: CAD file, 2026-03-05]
【大鱼DIY】雕绘仪 EP V3.0 全套资料/STP格式零件/X轴支架_A.STEP
57.5 x 16.5 x 28.0 mm

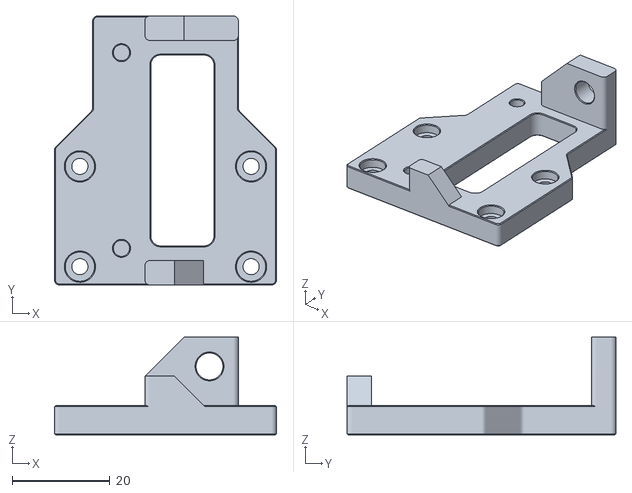
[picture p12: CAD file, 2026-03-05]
【大鱼DIY】雕绘仪 EP V3.0 全套资料/实际打印/笔架-抬笔底座.STL
45.4 x 55.0 x 20.0

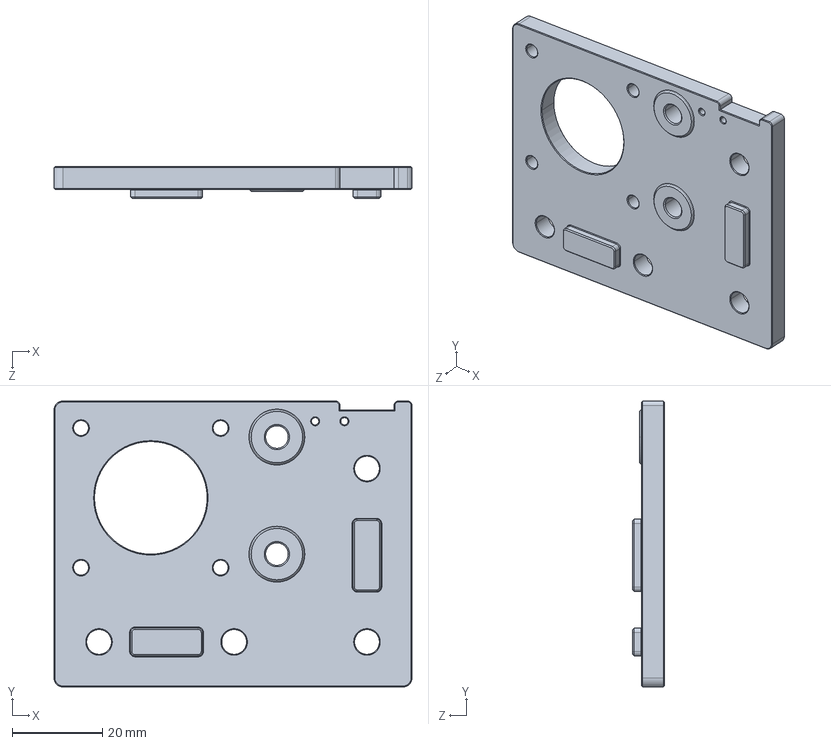
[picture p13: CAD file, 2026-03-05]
【大鱼DIY】雕绘仪 EP V3.0 全套资料/STP格式零件/A电机支架.STEP
79.5 x 63.5 x 7.00 mm

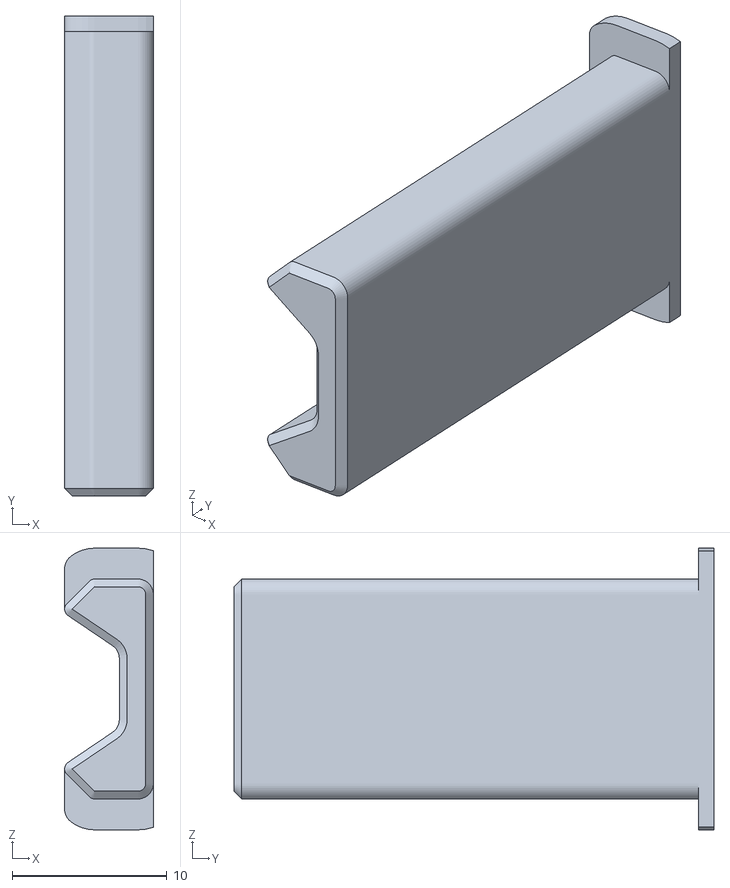
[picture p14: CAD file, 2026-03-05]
【大鱼DIY】雕绘仪 EP V3.0 全套资料/实际打印/笔架-压笔器.STL
5.74 x 31.0 x 18.2

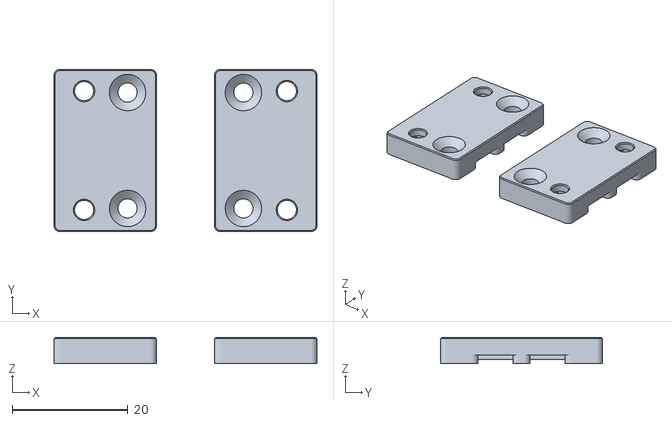
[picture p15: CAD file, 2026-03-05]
【大鱼DIY】雕绘仪 EP V3.0 全套资料/实际打印/笔架-X轴转接支架.STL
45.4 x 28.0 x 4.50

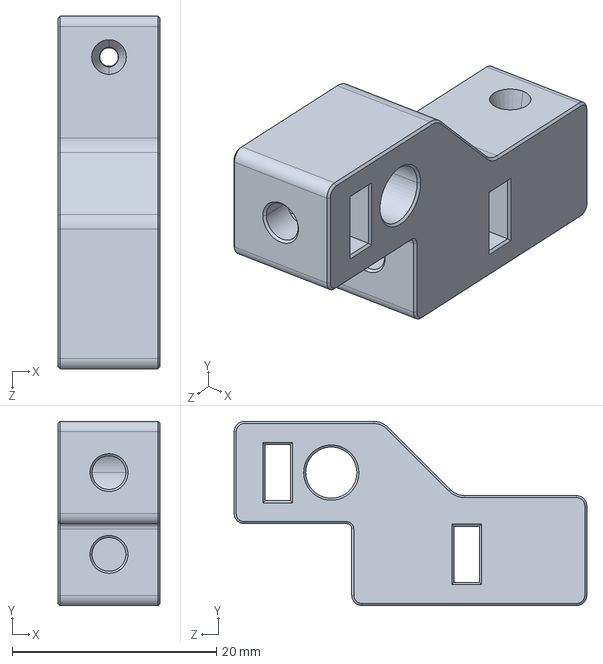
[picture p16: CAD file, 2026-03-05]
【大鱼DIY】雕绘仪 EP V3.0 全套资料/STP格式零件/摆动轮.STEP
10.0 x 18.0 x 34.5 mm

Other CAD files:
【大鱼DIY】雕绘仪 EP V3.0 全套资料/STP格式零件/抬笔底座.STEP
【大鱼DIY】雕绘仪 EP V3.0 全套资料/实际打印/X轴支架_A.STL
【大鱼DIY】雕绘仪 EP V3.0 全套资料/STP格式零件/X轴连接件_A.STEP
【大鱼DIY】雕绘仪 EP V3.0 全套资料/实际打印/X轴支架_B.STL
【大鱼DIY】雕绘仪 EP V3.0 全套资料/STP格式零件/压笔器.STEP
【大鱼DIY】雕绘仪 EP V3.0 全套资料/STP格式零件/笔架.STEP
【大鱼DIY】雕绘仪 EP V3.0 全套资料/实际打印/X轴连接件_A.STL
【大鱼DIY】雕绘仪 EP V3.0 全套资料/STP格式零件/B电机支架.STEP
【大鱼DIY】雕绘仪 EP V3.0 全套资料/STL格式零件/A惰轮座.STL
【大鱼DIY】雕绘仪 EP V3.0 全套资料/STL格式零件/A电机支架.STL
【大鱼DIY】雕绘仪 EP V3.0 全套资料/STL格式零件/B惰轮座.STL
【大鱼DIY】雕绘仪 EP V3.0 全套资料/STL格式零件/B电机支架.STL
【大鱼DIY】雕绘仪 EP V3.0 全套资料/STL格式零件/X轴支架_A.STL
【大鱼DIY】雕绘仪 EP V3.0 全套资料/STL格式零件/X轴支架_B.STL
【大鱼DIY】雕绘仪 EP V3.0 全套资料/STL格式零件/X轴连接件_A.STL
【大鱼DIY】雕绘仪 EP V3.0 全套资料/STL格式零件/主板盒子.STL
【大鱼DIY】雕绘仪 EP V3.0 全套资料/STL格式零件/主板盖子.STL
【大鱼DIY】雕绘仪 EP V3.0 全套资料/STL格式零件/摆动轮.STL
【大鱼DIY】雕绘仪 EP V3.0 全套资料/STL格式零件/长管夹.STL
【大鱼DIY】雕绘仪 EP V3.0 全套资料/STP格式零件/A惰轮座.STEP
【大鱼DIY】雕绘仪 EP V3.0 全套资料/STP格式零件/X轴支架_B.STEP
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

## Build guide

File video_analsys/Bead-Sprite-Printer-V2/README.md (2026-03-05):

# Bead-Sprite-Printer-V2
Contains firmware and software used for the bead sprite printer v2 robotic system

bead_fuser_arduino - this folder contains the Arduino file that controls realys that allow mains power to heat up 4 heat beds.
  heat beds used - https://www.amazon.com/gp/product/B07FB1TZ25/ref=ppx_yo_dt_b_search_asin_title?ie=UTF8&psc=1
   relays used - https://www.amazon.com/uxcell-ASH-25DA-3-32VDC-480VAC-Authorized/dp/B01LXLEBHQ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
   
bead_picker_placer_arduino - this folder contains the arduino files that controls the bead pick up mechanism (multiple servos, laser, light sensors, solinoid) as well as the bead placer mechanism (2 servos, LED, photodiodes) the Arduino also communicates with the marlin controller that controls the cnc machine
  servos used - https://www.amazon.com/gp/product/B07WYQ9P3F/ref=ppx_yo_dt_b_search_asin_title?ie=UTF8&psc=1
 
Custom Marlin firmware - Based off the Marlin firmware used for 3d printers, this custom version has additional g code commands that allows more customized features with the machine as well as communication to the helper arduino

beadv2_converter - this is the main python project that converts images to pixellated images matching the color pallet of the machine. It also converts the image to g code for the machine to run

Electrical - Doesnt show the electical or wiring changes made but contains schematic for marlin as well as some close up photos of wiring (sorry!)

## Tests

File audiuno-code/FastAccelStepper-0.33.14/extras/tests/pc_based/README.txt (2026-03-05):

Tests;

- test_01
  check queue functionality

- test_02
  checks ramp timing

- pmf_test
  checks Log2Representation implementation

- test_04
  one test case with speed change during ramp

- test_05
  check for move/moveTo while ramp is processing
  Introduce concept of interrupt generation during noInterrupts call

- test_06
  check for stop during move

- test_07
  test case with varying speed

- test_08
  ramp to max speed with step wise increased length

- test_09
  simple test case for V30 A1000000 R53 W R53

- test_10
  test case for V30 a17164 w2000 a-1000

- test 11
  test case for M1 A1000 V10000 f w300 V100000 U
  This is stuck in state RED.
  Revised test: M1 A1000 V10000 P100 w300 V100000 U

- test 12
  ramp up with 1 step/s^2 to 1000us/step

- test 13
  tests with maximum high acceleration

- test 14
  test case for issue #178: Speed jump instead of decrease

- test 15
  test case for setForwardPlanningTimeInMs()

- test 16
  tests for moveTimed()

- test 17
  test to specifically test for esp32 rmt implementation

- test 18
  RMT fill buffer test with comprehensive validation
  Tests rmt_fill_buffer() with various command patterns and PART_SIZE values
  
  Part 1: Fixed Command Inputs
  - Single step at different tick values (16000, 32000, 65535, 8000)
  - Multi-step commands (10@1000, 20@500, 10@8000)
  - Pause and step combinations
  - Mixed command sequences
  - Ramp generator outputs (from ramp_helper)
  Validates: step count, total ticks, high/low ratio, min symbol period
  
  Part 2: Step Count Limits (0-255 steps)
  - Tests 0-255 steps at MIN_CMD_TICKS (3200 ticks = 5 kHz)
  - Tests 0-255 steps at 16000 ticks (1000 us = 1 kHz)
  - Tests 0-255 steps at 32000 ticks (2000 us = 500 Hz)
  - Tests 0-255 steps at 65535 ticks (4095 us = ~244 Hz, special case)
  
  Part 3: High/Low Ratio Check
  - Validates 50% duty cycle for step commands
  - Tests tick values: 1000, 5000, 8000, 10000, 16000, 32000, 65535
  - Ratio must be between 30-200% for valid step generation
  
  Part 4: Reported Hardware Failure Analysis
  - Tests cases reported to fail on real hardware:
    * v=1000us (16000 ticks) => no pulses on real hardware
    * v=2000us (32000 ticks) => no pulses on real hardware  
    * v=500us (8000 ticks) => pulses but incorrect pattern (2:1 high:low ratio)
  - Compares simulation results with hardware reports
  
  Part 5: Additional Validation
  - Steps 0-255 with MIN_CMD_TICKS (3200 ticks) - comprehensive test
  - Steps 0-255 with period 65535 ticks - edge case validation
  - 200 kHz (80 ticks) with steps 1-255 - max frequency test
    Note: 80 ticks may be below stretching threshold for some PART_SIZE values
  
  Test runs with multiple even PART_SIZE values: 22, 24, 30, 32
  - ESP32C6 uses PART_SIZE=24 (RMT_SIZE=48)
  - ESP32/ESP32S3 use PART_SIZE=32 (RMT_SIZE=64)
  - PART_SIZE must be even (enforced by preprocessor check)
  
  Preprocessor options:
  - DUMP_RMT_SYMBOLS: Set to true/false to enable/disable condensed RMT symbol
    dumps for each test (default: true)
  
  Key validation criteria:
  1. Step count must match command steps
  2. Total ticks must match command ticks
  3. High/Low ratio should be ~1:1 (50% duty cycle) for step commands
  4. Minimum RMT symbol period must be >= 2 ticks (hardware limit)
  5. For ticks=65535, special encoding uses 2 RMT entries per step

- test 19
  ramp up with 100 step/s^2 to max speed. should not coast (#347)

- ramp_helper
  Helper tool to generate and dump ramp commands for given speed and acceleration
  Usage: make ramp_helper && ./ramp_helper <speed_us> <acceleration> <steps>
  Example: ./ramp_helper 1000 10000 1000
  Outputs commands until coasting reached, useful for creating test inputs

- ESP32 RMT Notes:
  * queue_entry.ticks is uint16_t, max value 65535 ticks (4095us at 16MHz)
  * For periods >65535 ticks, ramp generator uses pause commands
  * ticks=65535 is special case in rmt_fill_buffer (uses 2 entries per step)
  * ESP32C6 has PART_SIZE=24, ESP32/ESP32S3 use PART_SIZE=32
  * PART_SIZE must be even (enforced by preprocessor check)
  * Minimum RMT symbol period is 2 ticks (hardware limit)

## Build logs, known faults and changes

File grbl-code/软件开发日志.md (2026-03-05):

## 机头运动优化：目标 3*3点阵内实际能运动
** 注意！！！core xy电机运动限制 **
** 注意！！！皮带不要绷太紧 **

## 一期代码
1. 开始优化。 探究core xy电机运动规律 怎么在30mm距离内稳定运动
    方向： 1. 3200分步。 2. 修改maxA maxV 3. 探究更多的step库运动模式。 4. 直接上grbl库
    简单探究发现 直接上grbl库效果不错。 grbl库会直接覆盖AccelStepper库的运动控制效果。

    - grbl-code\single-moter-gcode-test\single-moter-gcode-test.ino
    - 如果代码写不上， 在编译阶段按一下nano上的按钮
    
2. 下一步目标 
2D 点阵运动标定：
目标：在3x3点阵范围内，确保机头能精准停在每个“豆孔”的中心。
方法：
网格测试：编写一个简单的G代码程序，让机头依次走遍3x3网格的所有9个点（例如，从(0,0)开始，步进10mm）。在每个点上，用笔在纸上扎一个小点，或者用摄像头观察实际落点。
误差测量与补偿：测量实际点阵与理论点阵的偏差。如果是整体平移或旋转，可在软件中修正原点或坐标系。如果是非线性失真（如梯形、桶形），则需要考虑机械结构的装配精度（如龙门架是否正交，皮带松紧是否一致）。

    - G1 X1600 F200 ; 运动后有27mm距离。
    - 开始提速
        M0          ; 使能电机
        G90         ; 绝对坐标
        G22 A300
        G1 X1600 F800
        G1 X0 F800
        以上的gcode测试下来 符合牛顿第二定律约束。 3秒跑完。 但是太慢了
    - 下面的测试后 2秒跑完。 功率仅增加1w
        G22 A900
        G1 X3200 F1600
        G1 X0 F1600
    - 继续测试 单电机到头了
        G22 A2000
        G1 X4000 F4000
        G1 X0 F4000
    - 实测精度对角线上有0.015mm的精度， 如果再插一个跳线帽， 可以做到0.0075mm的精度对应xy精度0.0053mm
    - 问题来了。 两个电机怎么配合控制？？？？？？
    - 目前我的gcode用错了 这个X应该是x轴的意思， 所以上电还要标定。。。。而且固件在真实gcode中要处理core xy结构的翻译

3. 双电机控制xy运动
    G1 X5500 Y0 F500
    G23 D1      ; 反转X轴（如果方向反了） ； x轴和默认代码反向 要改一下代码
    G1 X0 Y200 F500   ; y轴没问题
    M0          ; 可以开关电机 手动调整位置
    M0          ; 先使能电机（必须！否则校准不生效）
    G23 D0      ; 恢复方向默认（避免方向干扰）
    G24 S0.4    ; 设置倍率为0.4（核心！实现1步=0.01mm）
    G90         ; 确认绝对坐标模式（推荐）
    - 此时100步接近1mm
    G1 X3000 Y0 F500 ; 运动30.00mm x轴  非常完美
    G1 X3000 Y3000 F500
    G1 X0 Y0 F500    ; 感觉有一点丢步。1mm吧  误差挺大的。明天再修了

4. 测试舵机能不能按压拼豆笔
grbl-code\servo-test\servo-test.ino
S30        // 设置最大速度=15°/秒
A30         // 设置加速度=3°/秒²
F100        // 设置更新频率=80Hz（12.5ms刷新一次，高精度）
M150       // 从当前90°→150°（平滑运动）
M30        // 运动完成后，再从150°→30°
F20        // 降低频率到20Hz（50ms刷新，低精度）
M90        // 从30°→90°（运动稍显卡顿，但更省资源）

2026年3月3日02点20分 真的坚持不了了。 扛不住了 年纪大了 熬不了夜了。。。
servo有点问题。 理论上拼豆笔的按压力度小于500g，但是舵机按不下去， 不知道是电流问题还是角度问题还是算法问题。。
明天再解决舵机问题
本次开发就到这里了。 gcode调好了。 目前代码可以做到10cm*10cm内的运动。 误差在0.01mm了
甚至不需要grbl。 直接用我自己写的gcode代码， 加个python上位机程序就可以完成拼豆了。。就差一步。 明天继续调。。
啊啊啊 舵机怎么解决啊  啊啊啊 按个按钮还要单独做个机构？？？？？？？？

2026年3月3日09点05分 舵机两个修改 1. 单步调试 2. 用线拉，不用舵机杆直推
- 10点08分 直接舵机指令 70-115， 基本可用。 线拉很好用 第三方电源 3w功率

- 拼豆笔出口高于板子上豆子3mm 自动下落就成功率暴跌了
- 豆笔和机头用磁吸设计 4点磁吸。 足够方便和坚固

开始转入项目测试阶段
2026年3月3日 10点38分 开始整体联调。 开发python中

2026年3月3日 10点50分 开始整体联调。 
## gcode控制机头和下豆
```
0:55:13.613 -> === CoreXY+舵机集成系统就绪 ===
10:55:13.613 -> CoreXY指令：G90/G91 | G0/G1 Xxx Yyy Fxx | M0 | G22 Axx | G23 Dxx | G24 Sxx | G25 Cxx
10:55:13.613 -> 舵机指令：G30 Sxx(设置角度) | G31 [Pxx Qxx Rxx](按下动作，P=起始角 Q=终止角 R=延迟ms) | G32(复位到初始角度)
10:55:13.658 -> 初始状态：CoreXY禁用 | 舵机角度=70

```
coding plan 顶不住啊 问一句话就4%。 5个小时只能问20次？？

G31 P70 Q115 R50 ; 下豆 稳定率99% ; 状态机和非阻塞写的有点问题。 整体的代码效率也有问题， 但是暂时先不优化了。
; 机头运动初始化
G90         ; 默认方式 不必修改
M0          ; 目前默认xy方向正常
G24 S0.4    ; 设置倍率为0.4（核心！实现1步=0.01mm） ; 目前还没研究出小数点法， 但是好像没啥必要
G22 A20000  ; 就这样吧 够快了 1cm 2秒移动完毕
G1 X0 Y0 F500    ; 移动到原点
G1 X1000 Y0 F10000    ;

准备写python 控制台程序。 先做到9点定位
1. 找到初始坐标 7点标定法
    - 找到初始下豆点（0，0） -》 真实0.01mm的映射
    - 通过3*3 的下豆 标定对于26*26（7cm*7cm）的拼豆板标定
    - 先通过调节螺栓， 让用机器先标定豆板的朝向和框架平行

    G1 X1000 Y1000 F10000   ; 从y看对齐（0，0）
    G1 X8100 Y1000 F10000   ; 从y看对齐（26，0）
    G1 X0 Y0 F10000         ; 回到00
    G1 X600 Y1400 F10000    ; 从x看对齐（0，0）
    G1 X600 Y8500 F10000    ; 从x看对齐（0，0）

    ；有点问题。 拼豆板好像不是正方形
    G1 X-5000 Y4900 F10000  ； 手机opencv 40mm标定左下角
    G1 X-5000 Y8900 F10000
    G1 X-9100 Y8800 F10000
    G1 X-9100 Y4700 F10000
    ；机器有问题。。。 重复定位没有问题。 但是整体xy是歪的
    ； 拼豆板没有问题。 重新标定一下拼豆板 ； 找根钢丝， 垂直标定。 别拿机头
    ； 手工标定，就是视觉标定。。有这个都不需要更新固件做gcode映射了
    G1 X-450 Y1550 F10000   ; 对齐（0，0）
    G1 X6650 Y1550 F10000   ; 对齐（26，0） 
    G1 X-250 Y8675 F10000   ; 从x看对齐（0，26）
    G1 X6900 Y8650 F10000   ; 从x看对齐（26，26）
    - 开始py了
    grbl-code\gcode-bean-xy.py
    26x26_grid.gcode
    最小二乘+仿射变换 做到针的标定准确
    G1 X1000 Y1400 F6000    ； 机头（0，0）
    G1 X-441.8 Y1535.9 F6000 ；标定针 （0，0）
    机头下豆-》gcode： grbl-code\26x26_grid_机头.gcode
    G31 P70 Q115 R150  ; 下豆 
    - 再次校准
    G1 X1044.4 Y2825.8 F6000  ; 点(0,5)
    G1 X1004.4 Y2875.8 F6000  ; 点(0,5) 校准后
    G1 X1150.8 Y6247.6 F6000  ; 点(0,17)
    G1 X1110.8 Y6297.6 F6000  ; 点(0,17) 预测 ；没毛病 x-40 y+50
    - 生成 从（2，5） 到 （7，9）的线
    2026年3月3日14点17分。。。动了一下拼豆板。。。拿胶带沾上重新标定。。。。
    1. 6点快速标定； 2. 定位针到实际下豆标定   ; 注意 M0后固件不会认识新坐标。小心撞机
    G1 X-500 Y26200 F10000  ； 撞机了。。。。还好电源关的快，皮带也松。。。。
    代码没有重置原点功能。 插拔下usb吧
    如果再标定， 我就要写个脚本辅助标定了
    1. grbl-code\gcode-bean-xy.py 6个点坐标给出

    2026年3月3日 16点57分  写着写着发现。。。。不需要标定了。。。。直接键盘控制也很有意思。。。

       q → 实际坐标：X525.0 Y-1650.0
        q → 实际坐标：X525.0 Y5475.0
        
    确定每个豆的间隔。 机器还有点问题。 多颜色还需要研究

    目前的问题
    1. 豆笔存的豆子消耗的太快
    2. 目前只能拼单色
    3. 每次上电， 打开串口都需要手动校准
    4. 拼豆下落不稳定。 成功率不到99%
    5. 不能完整的打印一图案
    6. corexy好像变方向的时候会丢步

    拼豆下落正置成功率： 65/(65+8) = 89.04% （调整好的情况下）
    如果没有调整好， 成功率只有10%
    如果明天精细调整， 预估成功率能上升到97%
    可能的提升途径
        - 拼豆笔出口剪短
        - 拼豆板换高针
        - 提升下豆定位精度

豆笔目前有74mm仓位  用震动方式下豆， 能存24个豆子，我感觉10秒就玩完了。。。
就算豆子在次级仓位内存800mm， 也只能存300个豆子， 100秒用完。 8根就是800秒。 12分钟左右。。。
也就是说。 如果用豆仓的方式， 每种颜色15分钟就要补一次， 8种颜色人就忙不过来了。。32色就不用想了。
更好的方式是用类似3d打印的方式，直接供应豆子， 但是这个更麻烦。。。。

目前要做的
1. 完善单豆拼成的成功概率
2. 研究双色/多色怎么做到

2026年3月4日10点42分
    1. 定义当前状态： 有一台可以执行gcode的机器， 可以自动下豆。 需要手动上料， 需要手动标定， 只能单色运行。
    2. 优化方案： 通过测量和python代码， 预定义执行域， 快速标定。 
        - 目前的拼豆场景，一张26*26的拼豆板， 71mm*71mm距离， 71/25 = 2.84mm 每个豆的间隔；
        - 多色方案目前使用多个拼豆笔+磁吸触点方式。 每次都要校准， 但是能换色了。
        - 目前的机器gcode快速换向有点精度问题。 需要解决一下。
        - 机器目前的初始化问题， 把固件编程思维改成serial是一种功能， 处理好未连接， 连接之间的状态和状态转换就行
        - 框架左右y运动距离发现不对。框架立起来发现有3度的偏移，用电机所在边框当作基准线，手机辅助校准框架直角边
        - 尝试借助签字笔来确定整机问题。 opencv可以标定画出来的线是否准确。 只要掌握调整框架的步骤就行了
        - 最好的脚垫，防滑，对应任何表面: 2000目砂纸。 唯一缺点容易刮花表面
        - 电机边框上的两根皮带， 可以控制x轴的平行度， 也能确定皮带张紧程度
        - 外框长度 电机框 378.5 惰轮框 378 左边框 459.5 右边框 459.3 
        - 测试下来发现。 把皮带张紧一点 精度问题就消失了。。。
        - 测试发现两件事情 1. 磁吸水笔头很重要 2. 皮带张紧后定位精度在千分之5内，不需要特别调整， 万一精度因为无验证手段。无法得知。
        - 1600切分就可以做到4*0.01mm的定位精度。 反正命令给了，是有声音的。 再加个跳线帽估计能做到0.02mm的定位精度。 但是1. 对于拼豆没有必要 2. 移动速度问题不知道怎么解决
        - 妈的。。。拼豆笔的口不能随便剪。。。原来为了人类设计的， 有1mm的空隙。。。减少了拼豆下落距离 但是要保证豆子垂直下落
        - 影响豆子下落的因素
            1. 豆笔口距离豆子在板子的上端的距离(出口瞬间好像有碰撞)     保持1.0+0.3mm
            2. 出豆口末端5mm的直径（确保豆子从出豆口的确定位置出来，口径太宽，豆子在管子内随机碰撞， 出来的位置不固定）
                感觉上要做到    0.60mm > 口直径-豆直径 > 0.25mm
            3. 豆板针高（未确认）(从慢镜头看豆子在30mm的下落距离上 反弹能到4mm，所以感觉高针没用)
            4. 机头运动精度（因为豆板上有针， 豆子落在板子上会反弹，撞到豆笔口， 所以单个落豆精度没那么重要）
                感觉上2*0.16mm+0.16mm的定位精度是可以接受的。 （也就是定位偏差12%的豆间距，都能靠系统设计弹正）
            5. 机头来回运动， 下豆重复定位精度（疑似变换方向会丢步， 所以每次回折后的第四颗豆子都要加上+3*16*0.01mm的偏移）
                1 -> 2                                          3 -> 4
                     ↓     第四个必须 +3*16 step 才能正常落豆       ↑
                4 <- 3                                          2 <- 1
                这个是大概率事件， 解决方案1：针对性加代码， 方案2：改运动模式，避免这个问题
            
        2026年3月4日17点29分 统计成功率：(5*11+29+67)/(5*11+29+67+18)=89.34%
        兄弟。尴尬吗？ 搞了一天 除了确定机械框架没问题外， 拼豆成功率提升了0.3%。。。
        感觉就是出豆的问题， 不应该剪豆笔。 
        接下来的测试目标 
            1. 一次满豆出错一次（1/24，95%成功率）
            1. 2次满豆出错一次（1/48，98%成功率）
            1. 4次满豆出错一次（1/96，99%成功率）

        还可以试试直接向美纹纸上放什么效果
        明天测试记得记录单管时间和平均时间。 并且一定要做一个图案
        单管放置时间1分钟 补充时间20秒。 
        下豆提升成功率的方式 主要靠机头够靠近板子。 豆子碰到板子会跳一下， 和出口距离控制在0.3mm以内， 可以显著提高成功率。
        感觉可以定制拼豆机头了。 32豆存储， 轻量化弹簧， 定制管径。
        电机速度感觉也可以优化一下。不知道为什么a20000提升上不去了
        8192步跑了5.5秒。 实际速度在v1000，a1000左右， 和参数严重不符
            - a4988没问题， 它支持到30k步/s
            - nano虽然只有16mhz， 但2000步都跑不到绝对不是算力问题。 代码有严重的问题 明天再看

2026年3月5日12点42分
    1. 完成单电机性能测试，的确是浮点计算影响效率，换fastASlib后，控制速度精准。
    2. 使用timer2servo库，避免timer1被fas占用问题
    3. 测试发现不知道为什么acc设置不了， 直接写死6400，够用了。 bug修不修无所谓
    4. 舵机初始化提到最前面。 t2s库有bug，解决舵机初始化问题。

    - 目前花了5个小时， 机头运动速度提升4-8倍。常态功率提高1w，但是无所谓。 整体还在10w以下

    休息1h，然后开始测试单管时间和4管平均时间。 并且一定要做一个图案

2026年3月5日16点44分
    - 完成gui开发， 然后发现回放功能暂时没用。。。
    - 用在线工具生成图片。 但是ocr不好做。 人肉读图，手动拼豆
    - 实测100豆，20分钟完成， 9次补豆， 成功率90%

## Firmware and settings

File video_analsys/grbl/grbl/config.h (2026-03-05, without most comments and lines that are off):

#define config_h
#include "grbl.h" // For Arduino IDE compatibility.
#define DEFAULTS_GENERIC
#define BAUD_RATE 115200
#define CPU_MAP_ATMEGA328P // Arduino Uno CPU
#define CMD_STATUS_REPORT '?'
#define CMD_FEED_HOLD '!'
#define CMD_CYCLE_START '~'
#define CMD_RESET 0x18 // ctrl-x.
#define CMD_SAFETY_DOOR '@'
#define HOMING_INIT_LOCK // Comment to disable
#define HOMING_CYCLE_0 (1<<Z_AXIS)                // REQUIRED: First move Z to clear workspace.
#define HOMING_CYCLE_1 ((1<<X_AXIS)|(1<<Y_AXIS))  // OPTIONAL: Then move X,Y at the same time.
#define N_HOMING_LOCATE_CYCLE 1 // Integer (1-128)
#define N_STARTUP_LINE 2 // Integer (1-2)
#define N_DECIMAL_COORDVALUE_INCH 4 // Coordinate or position value in inches
#define N_DECIMAL_COORDVALUE_MM   3 // Coordinate or position value in mm
#define N_DECIMAL_RATEVALUE_INCH  1 // Rate or velocity value in in/min
#define N_DECIMAL_RATEVALUE_MM    0 // Rate or velocity value in mm/min
#define N_DECIMAL_SETTINGVALUE    3 // Decimals for floating point setting values
#define MESSAGE_PROBE_COORDINATES // Enabled by default. Comment to disable.
#define SAFETY_DOOR_SPINDLE_DELAY 4000
#define SAFETY_DOOR_COOLANT_DELAY 1000
#define ACCELERATION_TICKS_PER_SECOND 100
#define ADAPTIVE_MULTI_AXIS_STEP_SMOOTHING  // Default enabled. Comment to disable.
#define TOOL_LENGTH_OFFSET_AXIS Z_AXIS // Default z-axis. Valid values are X_AXIS, Y_AXIS, or Z_AXIS.
#define VARIABLE_SPINDLE // Default enabled. Comment to disable.
#define SPINDLE_MAX_RPM 1000.0 // Max spindle RPM. This value is equal to 100% duty cycle on the PWM.
#define SPINDLE_MIN_RPM 0.0    // Min spindle RPM. This value is equal to (1/256) duty cycle on the PWM.
#define MINIMUM_JUNCTION_SPEED 0.0 // (mm/min)
#define MINIMUM_FEED_RATE 1.0 // (mm/min)
#define N_ARC_CORRECTION 12 // Integer (1-255)
#define ARC_ANGULAR_TRAVEL_EPSILON 5E-7 // Float (radians)
#define DWELL_TIME_STEP 50 // Integer (1-255) (milliseconds)
#if defined(USE_SPINDLE_DIR_AS_ENABLE_PIN) && !defined(VARIABLE_SPINDLE)
  #error "USE_SPINDLE_DIR_AS_ENABLE_PIN may only be used with VARIABLE_SPINDLE enabled"
#endif
#if defined(USE_SPINDLE_DIR_AS_ENABLE_PIN) && !defined(CPU_MAP_ATMEGA328P)
  #error "USE_SPINDLE_DIR_AS_ENABLE_PIN may only be used with a 328p processor"
#endif

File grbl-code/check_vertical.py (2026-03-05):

import cv2
import numpy as np
import matplotlib.pyplot as plt
from sklearn.cluster import DBSCAN  # 用于空间聚类融合线条

def analyze_lines(image_path,
                  angle_tol=10,    # 判定为垂直/水平的角度容差（度）
                  min_line_len=50, # 最小线段长度（像素）
                  max_line_gap=10, # 线段最大间隙（像素）
                  merge_threshold=20 # 相邻线条融合阈值（像素）
                  ):
    # 1. 读取并预处理图像
    img = cv2.imread(image_path)
    if img is None:
        raise ValueError(f"无法读取图像: {image_path}")

    gray = cv2.cvtColor(img, cv2.COLOR_BGR2GRAY)
    # 二值化（可根据实际情况调整阈值）
    _, thresh = cv2.threshold(gray, 127, 255, cv2.THRESH_BINARY_INV)
    # 边缘检测
    edges = cv2.Canny(thresh, 50, 150, apertureSize=3)

    # 2. 霍夫变换检测线段
    lines = cv2.HoughLinesP(
        edges,
        rho=1,
        theta=np.pi / 180,
        threshold=50,
        minLineLength=min_line_len,
        maxLineGap=max_line_gap
    )

    if lines is None:
        print("未检测到任何线段")
        return [], []

    # 3. 按角度分类：垂直/水平
    vertical_lines = []  # 存储 (x1, y1, x2, y2, angle_deg)
    horizontal_lines = []

    for line in lines:
        x1, y1, x2, y2 = line[0]
        dx = x2 - x1
        dy = y2 - y1
        angle_rad = np.arctan2(dy, dx)
        angle_deg = np.degrees(angle_rad)

        # 标准化角度到 [-90, 90]
        if angle_deg > 90:
            angle_deg -= 180
        elif angle_deg < -90:
            angle_deg += 180

        # 判定垂直（接近 ±90°）
        if abs(abs(angle_deg) - 90) <= angle_tol:
            vertical_lines.append((x1, y1, x2, y2, angle_deg))
        # 判定水平（接近 0°）
        elif abs(angle_deg) <= angle_tol:
            horizontal_lines.append((x1, y1, x2, y2, angle_deg))

    # ========== 核心新增：融合20px内的相邻线条（最佳实践） ==========
    def merge_nearby_lines(lines, is_vertical, merge_threshold):
        """
        融合邻近线条：垂直线条按x坐标聚类，水平线条按y坐标聚类
        :param lines: 原始检测的线条列表
        :param is_vertical: 是否为垂直线
        :param merge_threshold: 融合阈值（像素）
        :return: 融合后的线条列表
        """
        if len(lines) < 2:
            return lines
        
        # 提取聚类特征：垂直线取中点x，水平线取中点y
        if is_vertical:
            # 垂直线：特征为 (中点x, 角度)
            features = np.array([[(x1+x2)/2, angle] for x1,y1,x2,y2,angle in lines])
        else:
            # 水平线：特征为 (中点y, 角度)
            features = np.array([[(y1+y2)/2, angle] for x1,y1,x2,y2,angle in lines])
        
        # DBSCAN聚类（空间邻近聚类的最佳实践）
        # eps=merge_threshold：20px内的视为同一类
        # min_samples=1：允许单个线条作为一类
        db = DBSCAN(eps=merge_threshold, min_samples=1).fit(features)
        labels = db.labels_
        
        merged_lines = []
        # 遍历每个聚类，合并为一条线
        for label in np.unique(labels):
            cluster_lines = [lines[i] for i in np.where(labels == label)[0]]
            
            if is_vertical:
                # 垂直线合并：取x均值，y取最大范围，角度均值
                x_mid = np.mean([(x1+x2)/2 for x1,y1,x2,y2,_ in cluster_lines])
                y_min = np.min([min(y1,y2) for x1,y1,x2,y2,_ in cluster_lines])
                y_max = np.max([max(y1,y2) for x1,y1,x2,y2,_ in cluster_lines])
                angle_avg = np.mean([angle for _,_,_,_,angle in cluster_lines])
                merged_lines.append((x_mid, y_min, x_mid, y_max, angle_avg))
            else:
                # 水平线合并：取y均值，x取最大范围，角度均值
                y_mid = np.mean([(y1+y2)/2 for x1,y1,x2,y2,_ in cluster_lines])
                x_min = np.min([min(x1,x2) for x1,y1,x2,y2,_ in cluster_lines])
                x_max = np.max([max(x1,x2) for x1,y1,x2,y2,_ in cluster_lines])
                angle_avg = np.mean([angle for _,_,_,_,angle in cluster_lines])
                merged_lines.append((x_min, y_mid, x_max, y_mid, angle_avg))
        
        return merged_lines
    
    # ========== 新增函数：计算直线方程 ==========
    def get_line_equation(x1, y1, x2, y2, is_vertical):
        """
        计算直线方程：
        - 垂直线：x = 常数
        - 水平线/斜线：y = kx + b
        """
        if is_vertical:
            # 垂直线（x坐标固定）
            x_const = round((x1 + x2) / 2, 2)
            return f"x = {x_const} "
        else:
            # 非垂直线：计算斜率k和截距b
            if x2 - x1 == 0:
                y_const = round((y1 + y2) / 2, 2)
                return f"y = {y_const}"
            k = (y2 - y1) / (x2 - x1)
            b = y1 - k * x1
            # 格式化输出（保留2位小数）
            k = round(k, 4)
            b = round(b, 2)
            return f"y = {k}x + {b}"
    
    # 融合垂直线和水平线
    merged_vertical = merge_nearby_lines(vertical_lines, is_vertical=True, merge_threshold=merge_threshold)
    merged_horizontal = merge_nearby_lines(horizontal_lines, is_vertical=False, merge_threshold=merge_threshold)

    # 4. 分析融合后垂直线条间距和垂直度 + 打印直线方程
    print("="*80)
    print(f"原始垂直线条: {len(vertical_lines)} 条 → 融合后: {len(merged_vertical)} 条")
    
    # 按照方程的c项偏移排列垂直线（x常数）
    def get_vertical_c(line):
        x1, _, x2, _, _ = line
        return (x1 + x2) / 2
    merged_vertical.sort(key=get_vertical_c)
    
    if len(merged_vertical) > 1:
        # 计算间距
        xs = np.array([(x1 + x2) / 2 for x1, y1, x2, y2, _ in merged_vertical])
        spacing = np.diff(xs)  # 相邻间距（像素）

        print("融合后垂直线条间距（像素）:")
        print(np.round(spacing, 2))
        print(f"平均间距: {np.mean(spacing):.2f} px, 标准差: {np.std(spacing):.2f} px")

        # 垂直度分析
        angles_v = np.array([a for _, _, _, _, a in merged_vertical])
        print(f"融合后垂直线条角度分布（度）: 平均={np.mean(angles_v):.2f}, 标准差={np.std(angles_v):.2f}")
    
    # 打印每条垂直线的方程
    print("\n【垂直线条详细信息（含直线方程）】")
    for idx, line in enumerate(merged_vertical):
        x1, y1, x2, y2, angle = line
        equation = get_line_equation(x1, y1, x2, y2, is_vertical=True)
        print(f"垂直线 {idx+1}: 角度={angle:.2f}° | 方程: {equation} | 端点: ({round(x1,1)},{round(y1,1)}) - ({round(x2,1)},{round(y2,1)})")

    # 分析融合后水平线条间距 + 打印直线方程
    print("\n" + "="*80)
    print(f"原始水平线条: {len(horizontal_lines)} 条 → 融合后: {len(merged_horizontal)} 条")
    
    # 按照方程的c项偏移排列水平线（y截距）
    def get_horizontal_c(line):
        _, y1, _, y2, _ = line
        return (y1 + y2) / 2
    merged_horizontal.sort(key=get_horizontal_c)
    
    if len(merged_horizontal) > 1:
        ys = np.array([(y1 + y2) / 2 for x1, y1, x2, y2, _ in merged_horizontal])
        spacing_h = np.diff(ys)

        print("融合后水平线条间距（像素）:")
        print(np.round(spacing_h, 2))
        print(f"平均间距: {np.mean(spacing_h):.2f} px, 标准差: {np.std(spacing_h):.2f} px")
    
    # 打印每条水平线的方程
    print("\n【水平线条详细信息（含直线方程）】")
    for idx, line in enumerate(merged_horizontal):
        x1, y1, x2, y2, angle = line
        equation = get_line_equation(x1, y1, x2, y2, is_vertical=False)
        print(f"水平线 {idx+1}: 角度={angle:.2f}° | 方程: {equation} | 端点: ({round(x1,1)},{round(y1,1)}) - ({round(x2,1)},{round(y2,1)})")
    print("="*80)

    # 5. 在图像上可视化融合后的结果
    result = img.copy()
    # 绘制融合后的垂直线（红色）并标注信息
    for idx, line in enumerate(merged_vertical):
        x1, y1, x2, y2, angle = line
        equation = get_line_equation(x1, y1, x2, y2, is_vertical=True)
        # 绘制线条
        cv2.line(result, (int(round(x1)), int(round(y1))), (int(round(x2)), int(round(y2))), (0, 0, 255), 2)
        # 计算标注位置（线条中间偏上）
        text_x = int(round(x1)) + 5
        text_y = int(round((y1 + y2) / 2)) - 10
        # 标注线条信息（英文）
        cv2.putText(result, f"Vertical {idx+1}", (text_x, text_y), cv2.FONT_HERSHEY_SIMPLEX, 0.5, (0, 0, 255), 1)
        cv2.putText(result, f"Angle: {angle:.1f}°", (text_x, text_y + 20), cv2.FONT_HERSHEY_SIMPLEX, 0.4, (0, 0, 255), 1)
        cv2.putText(result, f"Equation: {equation}", (text_x, text_y + 40), cv2.FONT_HERSHEY_SIMPLEX, 0.4, (0, 0, 255), 1)
    # 绘制融合后的水平线（绿色）并标注信息
    for idx, line in enumerate(merged_horizontal):
        x1, y1, x2, y2, angle = line
        equation = get_line_equation(x1, y1, x2, y2, is_vertical=False)
        # 绘制线条
        cv2.line(result, (int(round(x1)), int(round(y1))), (int(round(x2)), int(round(y2))), (0, 255, 0), 2)
        # 计算标注位置（线条中间偏左）
        text_x = int(round((x1 + x2) / 2)) - 100
        text_y = int(round(y1)) - 10
        # 标注线条信息（英文）
        cv2.putText(result, f"Horizontal {idx+1}", (text_x, text_y), cv2.FONT_HERSHEY_SIMPLEX, 0.5, (0, 255, 0), 1)
        cv2.putText(result, f"Angle: {angle:.1f}°", (text_x, text_y + 20), cv2.FONT_HERSHEY_SIMPLEX, 0.4, (0, 255, 0), 1)
        cv2.putText(result, f"Equation: {equation}", (text_x, text_y + 40), cv2.FONT_HERSHEY_SIMPLEX, 0.4, (0, 255, 0), 1)

    # 显示结果
    plt.figure(figsize=(12, 8))
    plt.subplot(121), plt.imshow(cv2.cvtColor(img, cv2.COLOR_BGR2RGB)), plt.title('Original')
    plt.subplot(122), plt.imshow(cv2.cvtColor(result, cv2.COLOR_BGR2RGB)), plt.title('Merged Lines (20px Threshold)')
    
    # 保存结果到图片文件
    save_path = 'merged_lines_result.png'
    cv2.imwrite(save_path, result)
    print(f"\n✅ 结果已保存到: {save_path}")
    
    plt.show()

    return merged_vertical, merged_horizontal

# ========== 运行示例 ==========
if __name__ == "__main__":
    # 替换为你的图片路径
    vertical_lines, horizontal_lines = analyze_lines(
        r"D:\work\trea\pixel_bean\grbl-code\IMG_20260304_140346.jpg",
        merge_threshold=20  # 20px内的线条融合为一条
    )

# 分析： 
# 原始垂直线条: 582 条 → 融合后: 50 条
#  【垂直线条详细信息（含直线方程）】
# 垂直线 1: 角度=89.18° | 方程: x = 14.94  | 端点: (14.9,1778) - (14.9,3817)
# 垂直线 2: 角度=-90.00° | 方程: x = 16.78  | 端点: (16.8,1662) - (16.8,3770)
# 垂直线 3: 角度=89.49° | 方程: x = 384.14  | 端点: (384.1,603) - (384.1,3779)
# 垂直线 4: 角度=-89.82° | 方程: x = 386.56  | 端点: (386.6,198) - (386.6,3870)        
# 垂直线 5: 角度=-89.98° | 方程: x = 549.87  | 端点: (549.9,313) - (549.9,3515)        
# 垂直线 6: 角度=89.47° | 方程: x = 550.0  | 端点: (550.0,223) - (550.0,3665)
# 垂直线 7: 角度=-89.85° | 方程: x = 780.03  | 端点: (780.0,460) - (780.0,2765)        
# 垂直线 8: 角度=89.64° | 方程: x = 822.83  | 端点: (822.8,958) - (822.8,2267)
# 垂直线 9: 角度=-90.00° | 方程: x = 823.9  | 端点: (823.9,1027) - (823.9,2687)        
# 垂直线 10: 角度=-90.00° | 方程: x = 1126.19  | 端点: (1126.2,195) - (1126.2,2506)    
# 垂直线 11: 角度=89.43° | 方程: x = 1160.5  | 端点: (1160.5,392) - (1160.5,493)       
# 垂直线 12: 角度=-89.96° | 方程: x = 1167.03  | 端点: (1167.0,191) - (1167.0,2490)    
# 垂直线 13: 角度=-89.93° | 方程: x = 1311.04  | 端点: (1311.0,832) - (1311.0,3112)    
# 垂直线 14: 角度=89.71° | 方程: x = 1313.4  | 端点: (1313.4,1195) - (1313.4,1754)     
# 垂直线 15: 角度=-89.81° | 方程: x = 1525.14  | 端点: (1525.1,586) - (1525.1,2832)    
# 垂直线 16: 角度=89.05° | 方程: x = 1528.5  | 端点: (1528.5,854) - (1528.5,914)       
# 垂直线 17: 角度=89.67° | 方程: x = 1563.67  | 端点: (1563.7,879) - (1563.7,2784)     
# 垂直线 18: 角度=-89.84° | 方程: x = 1565.66  | 端点: (1565.7,587) - (1565.7,2860)    
# 垂直线 19: 角度=-89.90° | 方程: x = 1850.72  | 端点: (1850.7,586) - (1850.7,2801)    
# 垂直线 20: 角度=-90.00° | 方程: x = 1891.0  | 端点: (1891.0,2716) - (1891.0,2839)    
# 垂直线 21: 角度=89.02° | 方程: x = 1927.62  | 端点: (1927.6,1958) - (1927.6,2558)    
# 垂直线 22: 角度=-89.90° | 方程: x = 1929.07  | 端点: (1929.1,544) - (1929.1,2716)    
# 垂直线 23: 角度=-90.00° | 方程: x = 1965.0  | 端点: (1965.0,2668) - (1965.0,2719)    
# 垂直线 24: 角度=89.46° | 方程: x = 2009.41  | 端点: (2009.4,2011) - (2009.4,2794)    
    # 垂直线 25: 角度=-90.00° | 方程: x = 2011.17  | 端点: (2011.2,504) - (2011.2,2668)    
# 垂直线 26: 角度=89.16° | 方程: x = 2046.5  | 端点: (2046.5,2528) - (2046.5,2596)     
    # 垂直线 27: 角度=-90.00° | 方程: x = 2051.82  | 端点: (2051.8,491) - (2051.8,2705)    
    # 垂直线 28: 角度=-89.94° | 方程: x = 2093.04  | 端点: (2093.0,571) - (2093.0,2871)    
# 垂直线 29: 角度=-90.00° | 方程: x = 2133.43  | 端点: (2133.4,599) - (2133.4,2834)    
    # 垂直线 30: 角度=89.42° | 方程: x = 2133.86  | 端点: (2133.9,602) - (2133.9,2714)     
# 垂直线 31: 角度=90.00° | 方程: x = 2169.0  | 端点: (2169.0,2702) - (2169.0,2825)     
    # 垂直线 32: 角度=-89.71° | 方程: x = 2172.84  | 端点: (2172.8,571) - (2172.8,2910)    
    # 垂直线 33: 角度=-89.90° | 方程: x = 2214.43  | 端点: (2214.4,613) - (2214.4,2921)    
# 垂直线 34: 角度=90.00° | 方程: x = 2217.0  | 端点: (2217.0,2542) - (2217.0,2598)     
# 垂直线 35: 角度=89.81° | 方程: x = 2292.38  | 端点: (2292.4,1441) - (2292.4,2781)    
# 垂直线 36: 角度=-89.87° | 方程: x = 2295.29  | 端点: (2295.3,653) - (2295.3,2992)    
# 垂直线 37: 角度=90.00° | 方程: x = 2331.0  | 端点: (2331.0,1605) - (2331.0,1661)     
# 垂直线 38: 角度=-89.87° | 方程: x = 2335.79  | 端点: (2335.8,695) - (2335.8,2966)    
# 垂直线 39: 角度=-88.09° | 方程: x = 2384.0  | 端点: (2384.0,609) - (2384.0,669)      
# 垂直线 40: 角度=-89.88° | 方程: x = 2459.93  | 端点: (2459.9,585) - (2459.9,3116)    
# 垂直线 41: 角度=89.71° | 方程: x = 2460.06  | 端点: (2460.1,587) - (2460.1,2989)     
# 垂直线 42: 角度=-90.00° | 方程: x = 2498.0  | 端点: (2498.0,2797) - (2498.0,2859)    
# 垂直线 43: 角度=-89.97° | 方程: x = 2541.55  | 端点: (2541.6,451) - (2541.6,2796)    
# 垂直线 44: 角度=89.69° | 方程: x = 2788.91  | 端点: (2788.9,1232) - (2788.9,3337)    
# 垂直线 45: 角度=-89.98° | 方程: x = 2790.68  | 端点: (2790.7,237) - (2790.7,3873)    
# 垂直线 46: 角度=-89.90° | 方程: x = 2853.66  | 端点: (2853.7,194) - (2853.7,3655)    
# 垂直线 47: 角度=89.74° | 方程: x = 2856.85  | 端点: (2856.8,462) - (2856.8,3606)     
# 垂直线 48: 角度=-90.00° | 方程: x = 2951.67  | 端点: (2951.7,214) - (2951.7,614)     
# 垂直线 49: 角度=89.34° | 方程: x = 2970.62  | 端点: (2970.6,321) - (2970.6,3429)     
# 垂直线 50: 角度=-90.00° | 方程: x = 2989.0  | 端点: (2989.0,2331) - (2989.0,3490)    

 
# 平均间距: 97.43 px, 标准差: 163.17 px

# 【水平线条详细信息（含直线方程）】
# 水平线 1: 角度=9.16° | 方程: y = 0.0x + 99.0 | 端点: (551,99.0) - (613,99.0)
# 水平线 2: 角度=0.06° | 方程: y = 0.0x + 179.49 | 端点: (410,179.5) - (2948,179.5)    
# 水平线 3: 角度=-0.10° | 方程: y = 0.0x + 246.32 | 端点: (837,246.3) - (1876,246.3)   
# 水平线 4: 角度=0.10° | 方程: y = 0.0x + 288.4 | 端点: (828,288.4) - (1938,288.4)     
# 水平线 5: 角度=0.11° | 方程: y = 0.0x + 330.7 | 端点: (821,330.7) - (1887,330.7)     
# 水平线 6: 角度=0.14° | 方程: y = 0.0x + 372.91 | 端点: (832,372.9) - (1928,372.9)    
# 水平线 7: 角度=-0.09° | 方程: y = 0.0x + 436.98 | 端点: (789,437.0) - (2548,437.0)   
# 水平线 8: 角度=0.07° | 方程: y = 0.0x + 495.47 | 端点: (829,495.5) - (2001,495.5)    
# 水平线 9: 角度=0.04° | 方程: y = 0.0x + 537.9 | 端点: (816,537.9) - (1937,537.9)     
# 水平线 10: 角度=0.14° | 方程: y = 0.0x + 575.83 | 端点: (842,575.8) - (2177,575.8)   
# 水平线 11: 角度=0.00° | 方程: y = 0.0x + 621.42 | 端点: (829,621.4) - (1972,621.4)   
# 水平线 12: 角度=-0.08° | 方程: y = 0.0x + 662.32 | 端点: (859,662.3) - (1972,662.3)  
# 水平线 13: 角度=0.14° | 方程: y = 0.0x + 703.46 | 端点: (862,703.5) - (1967,703.5)   
# 水平线 14: 角度=0.23° | 方程: y = 0.0x + 745.46 | 端点: (909,745.5) - (1953,745.5)   
# 水平线 15: 角度=-0.01° | 方程: y = 0.0x + 781.15 | 端点: (861,781.1) - (2468,781.1)  
# 水平线 16: 角度=0.05° | 方程: y = 0.0x + 820.92 | 端点: (863,820.9) - (2467,820.9)   
# 水平线 17: 角度=0.04° | 方程: y = 0.0x + 868.36 | 端点: (833,868.4) - (1971,868.4)   
# 水平线 18: 角度=0.00° | 方程: y = 0.0x + 910.73 | 端点: (834,910.7) - (1970,910.7)   
# 水平线 19: 角度=-0.13° | 方程: y = 0.0x + 950.18 | 端点: (839,950.2) - (1972,950.2)  
# 水平线 20: 角度=0.12° | 方程: y = 0.0x + 991.93 | 端点: (833,991.9) - (1900,991.9)   
# 水平线 21: 角度=0.00° | 方程: y = 0.0x + 1032.36 | 端点: (819,1032.4) - (1926,1032.4)
# 水平线 22: 角度=0.00° | 方程: y = 0.0x + 1971.08 | 端点: (1344,1971.1) - (2447,1971.1)

# 水平线 37: 角度=1.57° | 方程: y = 0.0x + 2838.0 | 端点: (1858,2838.0) - (1931,2838.0)
# 水平线 38: 角度=0.00° | 方程: y = 0.0x + 2875.0 | 端点: (2093,2875.0) - (2177,2875.0)
# : (388,3874.9) - (2786,3874.9)
# 水平线 42: 角度=-0.58° | 方程: y = 0.0x + 4093.5 | 端点: (2661,4093.5) - (2759,4093.5)
# ================================================================================

# ✅ 结果已保存到: merged_lines_result.png


标准测试区间
# 水平线 23: 角度=0.13° | 方程: y = 0.0x + 2264.81 | 端点: (847,2264.8) - (1940,2264.8)
# 水平线 24: 角度=0.00° | 方程: y = 0.0x + 2305.29 | 端点: (826,2305.3) - (1963,2305.3)
# 水平线 25: 角度=0.33° | 方程: y = 0.0x + 2347.33 | 端点: (837,2347.3) - (1973,2347.3)
# 水平线 26: 角度=-0.08° | 方程: y = 0.0x + 2386.35 | 端点: (826,2386.4) - (1927,2386.4)
# 水平线 27: 角度=0.00° | 方程: y = 0.0x + 2426.8 | 端点: (820,2426.8) - (1966,2426.8) 
# 水平线 28: 角度=0.00° | 方程: y = 0.0x + 2468.25 | 端点: (823,2468.2) - (1933,2468.2)
# 水平线 29: 角度=0.07° | 方程: y = 0.0x + 2509.06 | 端点: (838,2509.1) - (1946,2509.1)
# 水平线 30: 角度=0.08° | 方程: y = 0.0x + 2548.05 | 端点: (826,2548.0) - (1892,2548.0)
# 水平线 31: 角度=0.00° | 方程: y = 0.0x + 2590.25 | 端点: (819,2590.2) - (1831,2590.2)
# 水平线 32: 角度=-0.10° | 方程: y = 0.0x + 2630.08 | 端点: (830,2630.1) - (1900,2630.1)
# 水平线 33: 角度=0.00° | 方程: y = 0.0x + 2672.73 | 端点: (831,2672.7) - (1986,2672.7)
# 水平线 34: 角度=-0.15° | 方程: y = 0.0x + 2712.4 | 端点: (789,2712.4) - (1966,2712.4)
# 水平线 35: 角度=0.15° | 方程: y = 0.0x + 2752.44 | 端点: (811,2752.4) - (1964,2752.4)
# 水平线 36: 角度=0.00° | 方程: y = 0.0x + 2794.57 | 端点: (817,2794.6) - (1977,2794.6)
# 间距40.7像素 标准差1.3px  波动2%
# 垂直线 25: 角度=-90.00° | 方程: x = 2011.17  | 端点: (2011.2,504) - (2011.2,2668)    
# 垂直线 27: 角度=-90.00° | 方程: x = 2051.82  | 端点: (2051.8,491) - (2051.8,2705)    
# 垂直线 28: 角度=-89.94° | 方程: x = 2093.04  | 端点: (2093.0,571) - (2093.0,2871)    
# 垂直线 30: 角度=89.42° | 方程: x = 2133.86  | 端点: (2133.9,602) - (2133.9,2714)     
# 垂直线 32: 角度=-89.71° | 方程: x = 2172.84  | 端点: (2172.8,571) - (2172.8,2910)    
# 垂直线 33: 角度=-89.90° | 方程: x = 2214.43  | 端点: (2214.4,613) - (2214.4,2921)    
# 间距40.6px 标准差0.8px 波动1%
# 综上。 所有垂直线的间距均在标准测试区间内，符合要求。 水平，垂直运动在千分之5内不存在误差

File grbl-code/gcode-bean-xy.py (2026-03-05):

#!/usr/bin/env python3
# -*- coding: utf-8 -*-
"""
PixelBean 坐标映射工具（修正版）
将豆子坐标(bead_x, bead_y) 映射到 GCode坐标(gcode_x, gcode_y)
使用仿射变换 + 最小二乘法拟合

标定点数据（修正后）：
1. (0,0)   -> (-450, 1550)
2. (25,0)  -> (6650, 1550)
3. (0,25)  -> (-250, 8675)
4. (25,25) -> (6900, 8650)
5. (0,12)  -> (-300, 4950)
6. (12,0)  -> (2975, 1500)
"""

import numpy as np
import matplotlib.pyplot as plt
from mpl_toolkits.mplot3d import Axes3D

# 设置matplotlib支持中文
plt.rcParams['font.sans-serif'] = ['SimHei']  # 使用黑体
plt.rcParams['axes.unicode_minus'] = False  # 解决负号显示问题

# ====================== 输入数据（修正版） ======================
quick_gcode= """
G1 X3000 Y5500 F10000 ; 0,0
G1 X3400 Y12700 F10000 ; 0,25
G1 X10200 Y5400 F10000 ; 25,0
G1 X10500 Y12500 F10000 ; 25,25
G1 X3200 Y8950 F10000 ; 0,12
G1 X6500 Y5550 F10000 ; 12,0
"""
def quickgcode_to_calibration_points(gcode):
    """将快速标定GCode转换为标定点坐标"""
    points = []
    for line in gcode.splitlines():
        if line.startswith('G1'):
            parts = line.split(';')
            # 提取GCode坐标
            gcode_parts = parts[0].split()
            x = float(gcode_parts[1].replace('X', ''))
            y = float(gcode_parts[2].replace('Y', ''))
            # 提取豆子坐标
            bean_coord = parts[1].strip()
            bean_x, bean_y = map(int, bean_coord.split(','))
            # 添加到结果列表
            points.append(((bean_x, bean_y), (x, y)))
    return points

calibration_points = [
    # 四个角点
    ((0, 0), (-450, 1550)),      # 点1: 左下角
    ((25, 0), (6650, 1550)),     # 点2: 右下角
    ((0, 25), (-250, 8675)),     # 点3: 左上角
    ((25, 25), (6900, 8650)),    # 点4: 右上角
    # 两个中间点
    ((0, 12), (-300, 4950)),     # 点5: 左边中间
    ((12, 0), (2975, 1500)),     # 点6: 下边中间
]

calibration_points = quickgcode_to_calibration_points(quick_gcode)

# ====================== 数据可视化函数 ======================
def plot_calibration_points_2d(points):
    """2D可视化：显示豆子坐标和GCode坐标的对应关系"""
    bead_coords = np.array([p[0] for p in points])
    gcode_coords = np.array([p[1] for p in points])
    
    fig, (ax1, ax2) = plt.subplots(1, 2, figsize=(14, 6))
    
    # 豆子坐标空间
    ax1.scatter(bead_coords[:, 0], bead_coords[:, 1], c='blue', s=100, marker='o')
    for i, (x, y) in enumerate(bead_coords):
        ax1.annotate(f'{i+1}', (x, y), xytext=(5, 5), textcoords='offset points')
    ax1.set_xlabel('豆子 X')
    ax1.set_ylabel('豆子 Y')
    ax1.set_title('豆子坐标空间')
    ax1.grid(True)
    ax1.axis('equal')
    
    # GCode坐标空间
    ax2.scatter(gcode_coords[:, 0], gcode_coords[:, 1], c='red', s=100, marker='s')
    for i, (x, y) in enumerate(gcode_coords):
        ax2.annotate(f'{i+1}', (x, y), xytext=(5, 5), textcoords='offset points')
    ax2.set_xlabel('GCode X')
    ax2.set_ylabel('GCode Y')
    ax2.set_title('GCode坐标空间')
    ax2.grid(True)
    
    plt.tight_layout()
    plt.show()

def plot_mapping_surface(M, points):
    """3D可视化：显示映射曲面"""
    fig = plt.figure(figsize=(15, 6))
    
    # X映射曲面
    ax1 = fig.add_subplot(121, projection='3d')
    X_bead = np.linspace(0, 25, 30)
    Y_bead = np.linspace(0, 25, 30)
    X_bead, Y_bead = np.meshgrid(X_bead, Y_bead)
    Z_gcode_x = M[0,0] * X_bead + M[0,1] * Y_bead + M[0,2]
    
    ax1.plot_surface(X_bead, Y_bead, Z_gcode_x, alpha=0.7, cmap='viridis')
    ax1.scatter([p[0][0] for p in points], [p[0][1] for p in points], 
                [p[1][0] for p in points], color='red', s=50)
    ax1.set_xlabel('豆子 X')
    ax1.set_ylabel('豆子 Y')
    ax1.set_zlabel('GCode X')
    ax1.set_title('GCode X 映射曲面')
    
    # Y映射曲面
    ax2 = fig.add_subplot(122, projection='3d')
    Z_gcode_y = M[1,0] * X_bead + M[1,1] * Y_bead + M[1,2]
    
    ax2.plot_surface(X_bead, Y_bead, Z_gcode_y, alpha=0.7, cmap='plasma')
    ax2.scatter([p[0][0] for p in points], [p[0][1] for p in points], 
                [p[1][1] for p in points], color='red', s=50)
    ax2.set_xlabel('豆子 X')
    ax2.set_ylabel('豆子 Y')
    ax2.set_zlabel('GCode Y')
    ax2.set_title('GCode Y 映射曲面')
    
    plt.tight_layout()
    plt.show()

# ====================== 拟合仿射变换 ======================
def fit_affine_transform(points):
    """
    拟合从(bead_x, bead_y)到(gcode_x, gcode_y)的仿射变换
    
    参数:
        points: 列表，每个元素为 ((bead_x, bead_y), (gcode_x, gcode_y))
    
    返回:
        M: 变换矩阵 (2x3)
        stats: 统计信息字典
    """
    # 准备数据矩阵
    A_list = []  # 系数矩阵 [x, y, 1]
    b_x_list = []  # X目标值
    b_y_list = []  # Y目标值
    
    for (bead, gcode) in points:
        bx, by = bead
        gx, gy = gcode
        
        A_list.append([bx, by, 1])
        b_x_list.append(gx)
        b_y_list.append(gy)
    
    A = np.array(A_list)
    b_x = np.array(b_x_list)
    b_y = np.array(b_y_list)
    
    # 使用最小二乘法求解
    coeff_x, residuals_x, rank_x, s_x = np.linalg.lstsq(A, b_x, rcond=None)
    coeff_y, residuals_y, rank_y, s_y = np.linalg.lstsq(A, b_y, rcond=None)
    
    # 构建变换矩阵
    M = np.array([coeff_x, coeff_y])
    
    # 计算预测值和误差
    predicted_x = A @ coeff_x
    predicted_y = A @ coeff_y
    
    errors_x = b_x - predicted_x
    errors_y = b_y - predicted_y
    
    # 计算统计信息
    rmse_x = np.sqrt(np.mean(errors_x**2))
    rmse_y = np.sqrt(np.mean(errors_y**2))
    max_error_x = np.max(np.abs(errors_x))
    max_error_y = np.max(np.abs(errors_y))
    
    # 计算R²分数
    ss_res_x = np.sum(errors_x**2)
    ss_tot_x = np.sum((b_x - np.mean(b_x))**2)
    r2_x = 1 - (ss_res_x / ss_tot_x) if ss_tot_x != 0 else 1
    
    ss_res_y = np.sum(errors_y**2)
    ss_tot_y = np.sum((b_y - np.mean(b_y))**2)
    r2_y = 1 - (ss_res_y / ss_tot_y) if ss_tot_y != 0 else 1
    
    stats = {
        'rmse_x': rmse_x,
        'rmse_y': rmse_y,
        'max_error_x': max_error_x,
        'max_error_y': max_error_y,
        'r2_x': r2_x,
        'r2_y': r2_y,
        'predicted_x': predicted_x,
        'predicted_y': predicted_y,
        'residuals_x': errors_x,
        'residuals_y': errors_y
    }
    
    return M, stats
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

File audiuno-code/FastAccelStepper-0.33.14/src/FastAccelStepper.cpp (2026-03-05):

#include "FastAccelStepper.h"
#include "StepperISR.h"

// This define in order to not shoot myself.
#ifndef TEST
#define printf DO_NOT_USE_PRINTF
#define puts DO_NOT_USE_PUTS
#endif

// Here are the global variables to interface with the interrupts

// To realize the 1 Hz debug led
static uint8_t fas_ledPin = PIN_UNDEFINED;
static uint16_t fas_debug_led_cnt = 0;

// dynamic allocation seems to not work so well on avr
#if !defined(SUPPORT_STEPPER_CONNECT_BY_DRIVER)
FastAccelStepper fas_stepper[MAX_STEPPER];
#endif

//*************************************************************************************************
//*************************************************************************************************
#if defined(SUPPORT_CPU_AFFINITY)
void FastAccelStepperEngine::init(uint8_t cpu_core) {
  _externalCallForPin = NULL;
  _stepper_cnt = 0;
  for (uint8_t i = 0; i < MAX_STEPPER; i++) {
    _stepper[i] = NULL;
  }
  fas_init_engine(this, cpu_core);
}
#else
void FastAccelStepperEngine::init() {
  _externalCallForPin = NULL;
  _stepper_cnt = 0;
  for (uint8_t i = 0; i < MAX_STEPPER; i++) {
    _stepper[i] = NULL;
  }
#if defined(SUPPORT_RP_PICO)
  claimed_pios = 0;
#endif
  fas_init_engine(this);
}
#endif

void FastAccelStepperEngine::setExternalCallForPin(
    bool (*func)(uint8_t pin, uint8_t value)) {
  _externalCallForPin = func;
}
//*************************************************************************************************
bool FastAccelStepperEngine::_isValidStepPin(uint8_t step_pin) {
  return StepperQueue::isValidStepPin(step_pin);
}
//*************************************************************************************************
bool FastAccelStepperEngine::isDirPinBusy(uint8_t dir_pin,
                                          uint8_t except_stepper) {
  for (uint8_t i = 0; i < MAX_STEPPER; i++) {
    if (i != except_stepper) {
      FastAccelStepper* s = _stepper[i];
      if (s) {
        if (s->getDirectionPin() == dir_pin) {
          if (s->isQueueRunning()) {
            return true;
          }
        }
      }
    }
  }
  return false;
}
//*************************************************************************************************
#if !defined(SUPPORT_SELECT_DRIVER_TYPE)
FastAccelStepper* FastAccelStepperEngine::stepperConnectToPin(uint8_t step_pin)
#else
FastAccelStepper* FastAccelStepperEngine::stepperConnectToPin(
    uint8_t step_pin, FasDriver driver_type)
#endif
{
  // Check if already connected
  for (uint8_t i = 0; i < MAX_STEPPER; i++) {
    FastAccelStepper* s = _stepper[i];
    if (s) {
      if (s->getStepPin() == step_pin) {
        return NULL;
      }
    }
  }
  if (_stepper_cnt >= MAX_STEPPER) {
    return NULL;
  }
  if (!_isValidStepPin(step_pin)) {
    return NULL;
  }
#if defined(SUPPORT_SELECT_DRIVER_TYPE)
  uint8_t queue_from = 0;
  uint8_t queue_to = QUEUES_MCPWM_PCNT + QUEUES_RMT;
  if (driver_type == DRIVER_MCPWM_PCNT) {
    queue_to = QUEUES_MCPWM_PCNT;
  } else if (driver_type == DRIVER_RMT) {
    queue_from = QUEUES_MCPWM_PCNT;
  }
  int8_t fas_stepper_num = -1;
  for (uint8_t i = queue_from; i < queue_to; i++) {
    FastAccelStepper* s = _stepper[i];
    if (s == NULL) {
      fas_stepper_num = i;
      break;
    }
  }
  if (fas_stepper_num < 0) {
    return NULL;
  }
#else
#if defined(NEED_FIXED_QUEUE_TO_PIN_MAPPING)
  int8_t fas_stepper_num = StepperQueue::queueNumForStepPin(step_pin);
  if (fas_stepper_num < 0) {
    fas_stepper_num = _stepper_cnt;
  }
#else
  int8_t fas_stepper_num = _stepper_cnt;
#endif
#endif
  _stepper_cnt++;

  FastAccelStepper* s = &fas_stepper[fas_stepper_num];
  bool success = s->init(this, fas_stepper_num, step_pin);
  if (!success) {
    return NULL;
  }
  _stepper[fas_stepper_num] = s;
#if defined(NEED_ADJUSTABLE_MAX_SPEED_DEPENDING_ON_STEPPER_COUNT)
  for (uint8_t i = 0; i < MAX_STEPPER; i++) {
    const FastAccelStepper* sx = _stepper[i];
    if (sx) {
      fas_queue[sx->_queue_num].adjustSpeedToStepperCount(_stepper_cnt);
    }
  }
#endif
  return s;
}
//*************************************************************************************************
void FastAccelStepperEngine::setDebugLed(uint8_t ledPin) {
  fas_ledPin = ledPin;
  PIN_OUTPUT(fas_ledPin, LOW);
}
//*************************************************************************************************
void FastAccelStepperEngine::manageSteppers() {
#ifdef DEBUG_LED_HALF_PERIOD
  if (fas_ledPin != PIN_UNDEFINED) {
    fas_debug_led_cnt++;
    if (fas_debug_led_cnt == DEBUG_LED_HALF_PERIOD) {
      digitalWrite(fas_ledPin, HIGH);
    }
    if (fas_debug_led_cnt == 2 * DEBUG_LED_HALF_PERIOD) {
      digitalWrite(fas_ledPin, LOW);
      fas_debug_led_cnt = 0;
    }
  }
#endif
  for (uint8_t i = 0; i < MAX_STEPPER; i++) {
    FastAccelStepper* s = _stepper[i];
    if (s) {
#ifdef SUPPORT_EXTERNAL_DIRECTION_PIN
      if (s->externalDirPinChangeCompletedIfNeeded()) {
        s->fill_queue();
      }
#else
      s->fill_queue();
#endif
    }
  }

  // Check for auto disable
  for (uint8_t i = 0; i < MAX_STEPPER; i++) {
    FastAccelStepper* s = _stepper[i];
    if (s) {
      if (s->needAutoDisable()) {
        uint8_t high_active_pin = s->getEnablePinHighActive();
        uint8_t low_active_pin = s->getEnablePinLowActive();

        // fasDisableInterrupts(); // TODO
        bool agree = true;
        for (uint8_t j = 0; j < MAX_STEPPER; j++) {
          if (i != j) {
            FastAccelStepper* other = _stepper[j];
            if (other) {
              if (other->usesAutoEnablePin(high_active_pin) ||
                  other->usesAutoEnablePin(low_active_pin)) {
                if (!other->agreeWithAutoDisable()) {
                  agree = false;
                  break;
                }
              }
            }
          }
        }
        if (agree) {
          for (uint8_t j = 0; j < MAX_STEPPER; j++) {
            FastAccelStepper* current = _stepper[j];
            if (current) {
              if (current->usesAutoEnablePin(high_active_pin) ||
                  current->usesAutoEnablePin(low_active_pin)) {
                // if successful, then the _auto_disable_delay_counter is zero
                // Otherwise in next loop will be checked for auto disable again
                current->disableOutputs();
              }
            }
          }
        }
        // fasEnableInterrupts();
      }
    }
  }

  // Update the auto disable counters
  for (uint8_t i = 0; i < MAX_STEPPER; i++) {
    FastAccelStepper* s = _stepper[i];
    if (s) {
      fasDisableInterrupts();
      // update the counters down to 1
      s->updateAutoDisable();
      fasEnableInterrupts();
    }
  }
}
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

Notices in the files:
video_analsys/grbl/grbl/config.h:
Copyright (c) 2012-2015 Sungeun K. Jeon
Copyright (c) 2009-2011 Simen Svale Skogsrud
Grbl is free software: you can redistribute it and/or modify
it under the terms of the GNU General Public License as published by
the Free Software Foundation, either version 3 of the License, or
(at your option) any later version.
